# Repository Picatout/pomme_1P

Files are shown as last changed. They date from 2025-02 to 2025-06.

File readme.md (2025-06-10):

<!-- 
Copyright Jacques Deschênes, 2025
Ce document fait parti du projet pomme-I+
https://github.com/picatout/pomme-I+
-->

# POMME I+

En 2023/24 j'ai développé l'ordinateur [pomme-I](https://github.com/Picatout/pomme-I) sur une carte [NUCLEO-8S207K8](https://www.st.com/en/evaluation-tools/nucleo-8s207k8.html)
, cette année j'ai décidé de fabriqué une version du [pomme-I](https://github.com/Picatout/pomme-I) avec un micropresseur [W65C02S](https://www.mouser.ca/ProductDetail/Western-Design-Center-WDC/W65C02S6TPG-14?qs=opBjA1TV903lvWo9AEKH5w%3D%3D) qui est une version CMOS améliorée du vénérable 6502 qui était utilisé dans le Apple-I. Cette version du **MPU** comprend des instructions supplémentaires par rapport à l'original mais possède une compatibilité ascendante.

J'ai effectué le montage sur 3 cartes de prototypage pleine longueur [Ptsolns](https://ptsolns.com/fr/products/proto-full-basic) collée l'une à l'autre par la tranche pour former un ensemble mesurant 17,5 x 20 cm. 

### Assemblage résivé
* Ajout du PIA W65C22
* Remplacé socket du EEPROM par un socket ZIF
* Remplacé socket du EEPROM optionnel par un DIP-28 300mil au lieu du DIP28 600 mil.

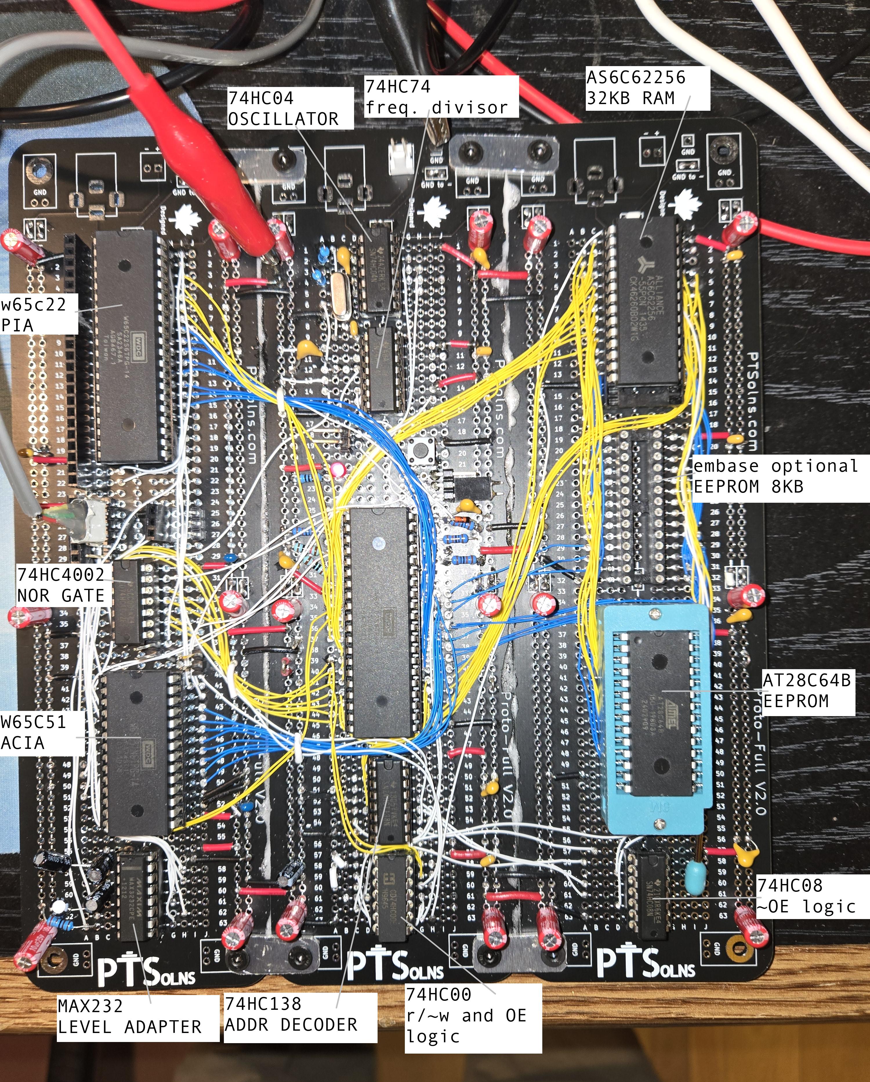
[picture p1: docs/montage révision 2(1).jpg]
assemblage


* La carte centrale comprend l'oscillateur *system clock* le *MPU* ainsi que le *décodeur d'adresses*.
* La carte de droite contient la mémoire **RAM** et **EEPROM**
* La carte de gauche contient un [W65C51S](https://www.mouser.ca/ProductDetail/Western-Design-Center-WDC/W65C51N6TPG-14?qs=AgbsAOSw7WDdUCKSkUixbw%3D%3D) qui est une interface de communication sérielle, i.e. UART. Un [MAX232CPE](https://www.mouser.ca/ProductDetail/Analog-Devices-Maxim-Integrated/MAX232CPE%2b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) est utilisé pour l'adaptation de niveau au standard **RS-232** pour permettre la communication avec un port sériel de PC. Il y a un espace libre suffisante sur la carte pour ajouter un module de développement du genre **NUCLEO-8S207K8**, **PI-PICO**, **BLUE PILL** ou encore **BLACK PILL**. À ce moment je n'ai pas arrêté mon choix sur le type d'exention que je vais ajouté sur cet espace. 

À cette étape je vais utilisé mon PC comme terminal pour le développement du software.  

### Schématique

Pour l'essentiel la schématique du circuit est complète et peut-être consultée dans le document [docs/pomme_1+_schematic.pdf](docs/pomme_1+_schematic.pdf).

### État actuel du projet
Dans l'état actuel du projet je branche l'ordinateur au PC et utilise l'émulateur de terminal **GTKTerm** configuré à 115200 8N1. Il n'y a qu'un petit programme de [test1.s](p1pMonitor/test1.s) dans l'EEPROM. 

Le projet [eeProg](https://github.com/Picatout/eeprom-programmer) que j'ai développer dernièrement me sert à programmer cet EEPROM. 

### spécifications:

* Processeur **W65C02STPG** de Western Design Center
* 3 fréquences d'horlogue (*system clock*) sont disponibles en positionnant un cavalier.
    * 3,6864Mhz 
    * 1,8432Mhz 
    * 0,9216Mhz 

* Mémoire RAM de 32Ko, 0x0000-0x7FFF 
* Mémoire EEPROM de 8Ko, 0xE000-0xFFFF 
* Mémoire EEPROM optionnelle de 8Ko, 0xB000-0xCFFF
* Périphérique ACIA à 0xD000-0xD003, décodage partiel sur un espace de 4Ko.

### Dévelopement logiciel
J'utilise l'assembleur [ca65](https://cc65.github.io/doc/ca65.html) pour le dévelopement logiciel.

1. je vais écrire les fonctions de base de l'interface de communication et ensuite adapter le WOZMON du Apple I. 

2. je vais étendre le BIOS et écrire un système d'exploitation inspiré de CP/M. 

3. Adapter le Microsoft BASIC à partir du Travail de [Ben Eater](https://github.com/beneater/msbasic) qui est lui-même une adaptation à partir de [mist64/msBasic](https://github.com/mist64/msbasic).

### Continuation du dévelopement matériel
Au final cet ordinateur aura son propre terminal intégré et sera monté dans un boitier en bois semblable à celui que j'ai fait pour le [pomme-I](https://github.com/Picatout/pomme-I).

### 2025-03-11 vidéo de présention 

[vidéo de présentation du pomme 1+](https://youtu.be/0cAoQgj5ZgQ)

[début](#top)

### 2025-04-24

* Changement de direction, pour le moment j'ai abandonné le sous-projet **p1+_drive** pour fabriquer une carte contenant seulement la mémoire flash **W25Q080DV** de 1MO et qui et branchée directement sur un connecteur relié au PIA **W65C22**. Donc tous le firmware pour le stockage des programmes dans la mémoire flash cera programmé dans le BIOS du **pomme 1+.** 

carte mémoire flash. 

[lien vidéo montrant la carte](https://youtube.com/shorts/QT92BZp_K6k?feature=share)

[début](#top)

### 2025-05-21

Modification de la carte SSD et son. Ajout d'un amplificateur audio et d'un petit haut-parleur sur la carte. LE timer 1 du VIA , i.e. **W65C22** est utilisé pour générer des tonalités en sortie sur PB7. 

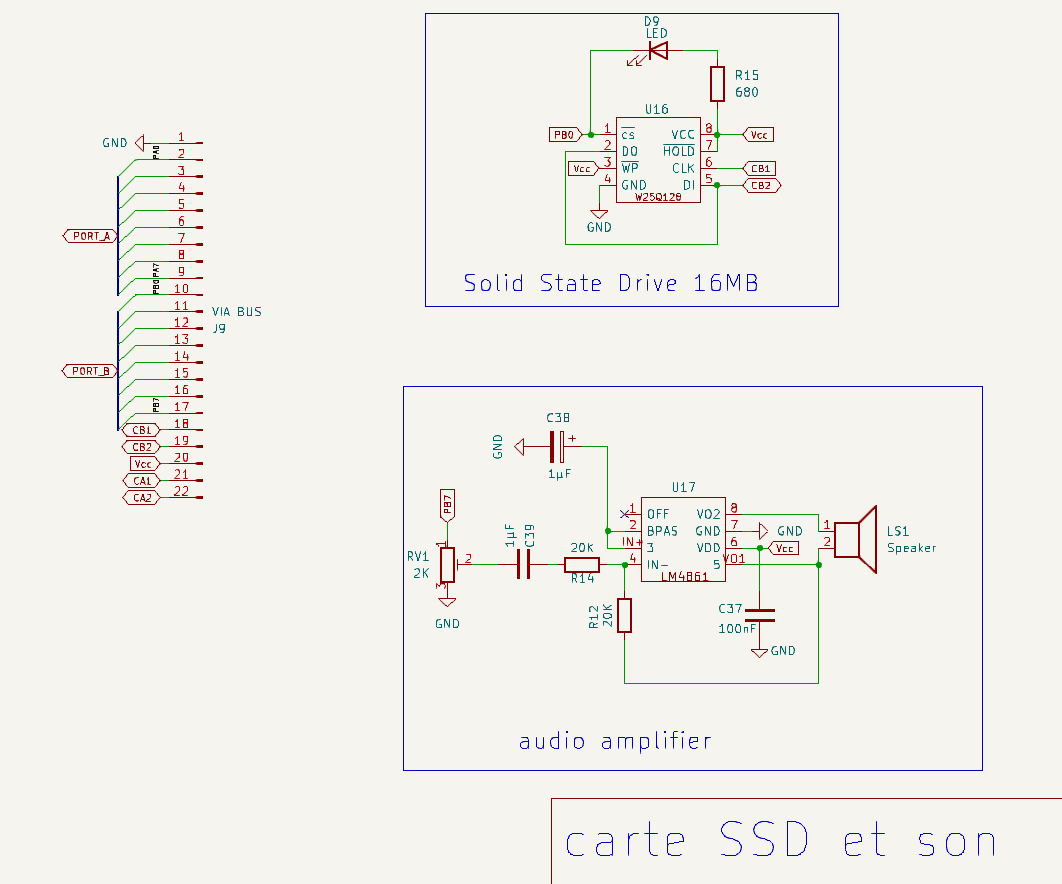
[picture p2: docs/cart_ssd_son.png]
schématique ssd et son
 

carte ssd+son 

Cette carte se branche sur un connecteur qui est relié à toutes les broches E/S du VIA. 

**p1+Monitor version 1.2.2** 

[lien vidéo démonstration de la dernière version du moniteur](https://youtu.be/FdeKaAmC1mY)

[début](#top)

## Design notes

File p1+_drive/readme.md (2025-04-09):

# p1+_drive 

Comme tous les ordinateurs le **pomme 1+** a besoin d'une mémoire de masse persistante pour stocké les fichiers. Ce projet créé un périphérique de stockage de 1 Mo en utilisant un MCU STM8S207K8T ainsi qu'une mémoire flash Winbond W25Q080DV . Le STM8S207K8T sera interfacé avec le **pomme 1+** directement par le **data bus**.

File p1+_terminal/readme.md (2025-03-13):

# STM8 terminal 

Un terminal ASCII réalisé sur une carte NUCLEO-S207K8

*   Affichage 62 caractères par ligne, 25 lignes 
*   Clavier PS/2 
*   TVout NTSC. 
*   interface UART niveaux 0:5 volts 

### NOTE 

Sur la carte **nucleo_8S207K8** les cavaliers **SB3,SB4** doivent-être déplacés vers **SB7,SB9**.

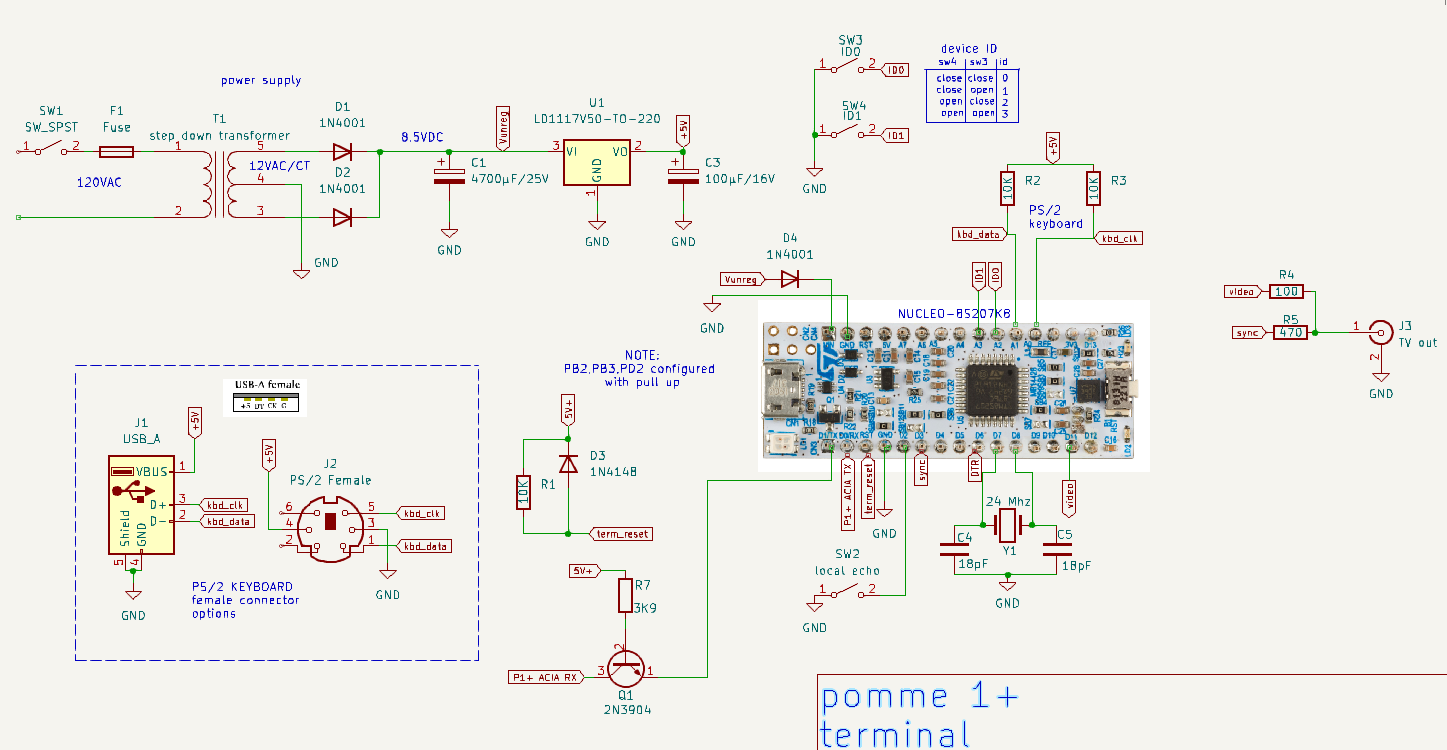
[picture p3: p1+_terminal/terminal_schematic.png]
schématique


Ce terminal a été créé pour le projet [POMME-I+](https://github.com/Picatout/pomme-1P).

Les 2 cartes NUCLEO-8S207K8 communique entre elle via le UART. Voir la schématique complète du projet [POMME-I](https://github.com/Picatout/pomme-I) sur le déppôt github de ce dernier. 

## Quand il faut compter les cycles machines.

Sortir 40 caractères par ligne avec un MCU fonctionnant à 20Mhz en utilisant le protocole NTSC n'a pa été évident. Il n'y avait tout simplement pas suffisamment de temps pour utiliser des compteurs avec boucle. Le temps d'affichage d'une ligne de balayage NTSC est de 52µsec. 1 cycle cpu à 20Mhz dure 50nsec on dispose donc d'un maximum de 1040 cycles pour afficher les 40 caractères ce qui donne 26 cycles cpu par caractère.

Après plusieurs expérimentation avec le périphérique SPI qui ne donnait pas de résultat satisfaisant j'ai abandonné le SPI. Pour y parvenir j'ai fait 2 choses. 

1. Le tampon video **video_buffer** ne contient pas les caractères à afficher mais l'adresse du caractère dans la table **font_6x8**. Ainsi il n'y a pas de cycle perdu pour faire le calcul de l'adresse du caractère pendant l'affichage. C'est la routine **tv_putc** qui fait le travail. 

1. Pour sortir les pixels vidéos il faut sérialiser les pixels représentant le caractère. Faire ça en sorftware prend 14 cycles cpu avec la macro  **_shift_out_char** du fichier [tvout.asm](tvout.asm).
La macro **_shift_out_scan_line** prend 20 cycles au total en incluant **_shift_out_char**. Si on fait le calcul pour 40 caractères ça fait 800 cycles soit 40µsec. Bien en déça des 52µsec allouée. Ça c'est selon les cycles machines fournis par le manufacturier du STM8 mais en pratique la durée mesurée à l'oscilloscope est de 51.2µsec. C'est serré! Tellement serré que je ne pouvait utiliser des boucles avec compteurs. Pour arriver à ce temps j'ai du dérouler la macro 40 fois. 

# Où sont passés ces cycles CPU. 

Je me suis mis à réfléchir à cette différence entre le nombre de cycles CPU selon ce que je mesure à l'oscilloscope le temps d'éxécution par caractère serait de 51.2µsec/50nsec=1024/40=25.6 cycles au lieu de 20 cycles. 5.6 de plus. Donc je me demandais où étaient passés ces cycles? Je me suis dit que le fait de lire l'octet dans la table font_6x8 entre en concurrence avec la lecture des instructions machine. STM8 est une architecture Harvard. Ça signigit que le bus d'instruction est séparé du bus de données. Cette architecture a étée conçue pour améliorer la vitesse d'exécution des instructions puisque celle-ci n'ont pas à partager l'accès mémoire avec les données. Je me suis donc dit que si je copiais la table [font_6x8](font.asm) dans la mémoire RAM ce conflit d'accès serait éliminé et que l'exécution serait plus rapide. 

J'ai fait le test et c'est bien le cas, sauf qu'il n'y a qu'un seul cycle machine par caractère de récupéré. L'affichage des 40 caractères avec la police en mémoire RAM prend 49.2µsec soit 2µsec de moins ce qui correspond une fois le calcul fait à 1 cycle par caractère. Il y a donc encore 4.6 cycles manquant. 

Pour comprendre cette différence il faut lire le chapitre 5 du manuel de progammation  [PM0044](https://www.st.com/content/ccc/resource/technical/document/programming_manual/43/24/13/9a/89/df/45/ed/CD00161709.pdf/files/CD00161709.pdf/jcr:content/translations/en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). La section 5.4 et la table 3 nous donnes un bel exemple. Selon le nombre de cycles données dans la description de chaque instruction: 

1.  LDW X,[$50.w] ; 5 cycles 
1.  ADDW X,#20   ; 2 cycles 
1.  LD A,[$300].w ; 4 cycles 

On obtient un total de **11 cycles**. mais dans la table 3 on voit qu'en fait il en faut **12**. 

Donc en conclusion le pipelining permet d'accélérer l'exécution des instructions sauf qu'il n'est plus possible de se fier au nombre de cycles donnés dans la description de chaque instruction pour calculer le temps d'exécution d'une séquence d'instructions, comme c'est le cas pour un mcu PIC 16Fxxxx. 

### 2023-07-17

L'intégration du **STM8_terminal** avec l'ordinateur **POMME-I** a nécessité des modifications aux 2 projets. Durant certaines opérations du terminal ce dernier perdait des caractères envoyés par l'ordinateur. Le problème a été corrigé par l'ajout d'un contrôle de flux matériel appellé **DTR** pour *Data Terminal Ready*. l'ordinateur n'envoie des caractères au terminal que lorsque ce signal est à **0** volt.

### 2023-07-05 

* Modification au circuit du terminal pour ajouter des commutateurs pour la sélection d'options utilisateur.

    * **SW3** sert à sélectionner un écho local lorsqu'il est à **1** 
    * **SW4** et **SW5** permettent de sélectionner un BAUD rate pour  le UART.

  SW4|SW5|BAUD 
    -|-|-
    0|0| 9600
    0|1| 19200
    1|0| 38400
    1|1| 115200

Si les commutateurs ne sont pas installés par défaut les broches sont toutes à **1** à travers les résistances *pull up* MCU, donc il y a écho local et le BAUD est à 115200.

Les commautateurs sont lu lors de l'initialisation et toute modification de leur position requiert un redémarrage du MCU pour que la nouvelle configuration prenne effet.

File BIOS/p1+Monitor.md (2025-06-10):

# manuel du moniteur pomme I+

Le moniteur est l'application qui est exécutée au démarrage de l'ordinateur pomme I+. Cette application permet les fonctions suivantes:

* Examiner le contenu de la mémoire.
* Modifier le contenu de la mémoire RAM.
* Initialiser une plage mémoire à zéro.
* Copier une plage mémoire vers une autre addresse.
* Comparer du plages mémoire pour les différences.
* Sauvarder une plage mémoire vers le SSD.
* Charger une plage mémoire avec le contenu du SSD.
* Exécuter une routine en langage machine.

## Utilisation du moniteur 

Au démarrage le message suivant apparaît. le caractère **#** est le prompt de commande.

```
pomme I+ BIOS version 1.0R0
pomme 1+ monitor version 1.2R1

#
```
## les commandes 

Toutes les valeurs numériques doivent-être en hexadécimal.

### Examiner le contenu de la mémoire.

Simplement en appuyant sur la touche __&lt;ENTER&gt;__ le contenu de 16 adresses mémoire est affiché. 
```
#

0000: E5 97 11 00 00 00 00 00 00 00 00 00 03 00 7D FF  ;               } 
#

0010: FF 00 00 00 00 00 00 02 02 00 FC 0D 0D 33 66 66  ;              3ff
#

0020: 0D 66 66 6D 33 30 31 0D 33 30 30 2E 33 66 66 0D  ;  ffm301 300.3ff 
#

0030: 33 30 30 2E 33 66 66 7A 0D 33 30 00 00 3D 00 3F  ; 300.3ffz 30  = ?
#
``` 
Pour afficher une plage mémoire spécifique on entre l'adresse de départ et l'adresse de fin séparées par un **.** (point). 
```
#400.4FF

0400: 47 00 00 00 00 00 00 00 00 00 00 00 00 00 00 00  ; G               
0410: 00 00 00 00 00 00 00 00 00 00 00 00 00 00 00 00  ;                 
0420: 00 00 00 00 00 00 00 00 00 00 00 00 00 00 00 00  ;                 
0430: 00 00 00 00 00 00 00 00 00 00 00 00 00 00 00 00  ;                 
0440: 00 00 00 00 00 00 00 00 00 00 00 00 00 00 00 00  ;                 
0450: 00 00 00 00 00 00 00 00 00 00 00 00 00 00 00 00  ;                 
0460: 00 00 00 00 00 00 00 00 00 00 00 00 00 00 00 00  ;                 
0470: 00 00 00 00 00 00 00 00 00 00 00 00 00 00 00 00  ;                 
0480: 00 00 00 00 00 00 00 00 00 00 00 00 00 00 00 00  ;                 
0490: 00 00 00 00 00 00 00 00 00 00 00 00 00 00 00 00  ;                 
04A0: 00 00 00 00 00 00 00 00 00 00 00 00 00 00 00 00  ;                 
04B0: 00 00 00 00 00 00 00 00 00 00 00 00 00 00 00 00  ;                 
04C0: 00 00 00 00 00 00 00 00 00 00 00 00 00 00 00 00  ;                 
04D0: 00 00 00 00 00 00 00 00 00 00 00 00 00 00 00 00  ;                 
04E0: 00 00 00 00 00 00 00 00 00 00 00 00 00 00 00 00  ;                 
04F0: 00 00 00 00 00 00 00 00 00 00 00 00 00 00 00 00  ;                 
#
```
 __&lt;ENTER&gt;__ après cette commande va afficher le contenu de 500.50f
 ```
 #

0500: 00 00 00 00 00 00 00 00 00 00 00 00 00 00 00 00  ;                 
#

``` 

### Modifier le contenu de la mémoire. 
Une addresse suivie du caractère **:**  et de valeurs numérique ou chaines de caractères permet de modifier le contenu de la mémoire.
```
#400: 30 31 32 33 34 35 " bonjour  vous!"

#400.41f

0400: 30 31 32 33 34 35 20 62 6F 6E 6A 6F 75 72 20 20  ; 012345 bonjour  
0410: 76 6F 75 73 21 00 00 00 00 00 00 00 00 00 00 00  ; vous!           
#
```
### Exécuter une routine en langage machine.
La commande **G**o sub permet d'exécuter une sous-routine en langague machine.
```
#300:d "hello world!"

#310: A9 3 A2 0 20 43 E4 60

#300.31F

0300: 0D 68 65 6C 6C 6F 20 77 6F 72 6C 64 21 00 83 71  ;  hello world!  q
0310: A9 03 A2 00 20 43 E4 60 00 00 00 04 02 00 00 00  ;      C `        
#310G

hello world!
#G

hello world!
#
```
Dans cet exemple on a inscrit à l'adresse **0x300** la chaine de caractères "\rhello world!" et à l'adresse **0x310** on a inscrit la routine à exécuter.
l'adresse de la routine suivit de la lettre **G** permet d'exécuter la routine. On peut réexécuter la routine plusieurs fois simplement en entrant la lettre **G** Suivant de la touche **&lt;ENTER&gt;**. 

### Copîer le contenu d'une plage mémoire 
La commande **M**  permet de copier une plage vers une destination.
```
#400.415M420

#400.44F

0400: 30 31 32 33 34 35 20 62 6F 6E 6A 6F 75 72 20 20  ; 012345 bonjour  
0410: 76 6F 75 73 21 00 00 00 00 00 00 00 00 00 00 00  ; vous!           
0420: 30 31 32 33 34 35 20 62 6F 6E 6A 6F 75 72 20 20  ; 012345 bonjour  
0430: 76 6F 75 73 21 00 00 00 00 00 00 00 00 00 00 00  ; vous!           
0440: 00 00 00 00 00 00 00 00 00 00 00 00 00 00 00 00  ;                 
#
```
Dans cette exemple le contenu de la plage débutant à 400 et se terminant à 415 a été copiée à l'adresse 420.

### Mettre une plage à la valeur zéro.
La commande **Z** permet de mettre une plage mémoire à zéro.
```
#400.435Z

#400.435

0400: 00 00 00 00 00 00 00 00 00 00 00 00 00 00 00 00  ;                 
0410: 00 00 00 00 00 00 00 00 00 00 00 00 00 00 00 00  ;                 
0420: 00 00 00 00 00 00 00 00 00 00 00 00 00 00 00 00  ;                 
0430: 00 00 00 00 00 00  ;                 
#
```
ComMe on le voie le texte a été remplacé par des zéro. 

### Mettre une autre valeur que zéro.
Il existe une astuce pour remplir une plage avec une valeur autre que zéro. Il s'agit d'utiliser la commandees **:** suivit de la commande **M**.
```
#400: "hello world!" 

#400.40f

0400: 68 65 6C 6C 6F 20 77 6F 72 6C 64 21 00 00 00 00  ; hello world!    
#400.4FFM40C

#400.4FF

0400: 68 65 6C 6C 6F 20 77 6F 72 6C 64 21 68 65 6C 6C  ; hello world!hell
0410: 6F 20 77 6F 72 6C 64 21 68 65 6C 6C 6F 20 77 6F  ; o world!hello wo
0420: 72 6C 64 21 68 65 6C 6C 6F 20 77 6F 72 6C 64 21  ; rld!hello world!
0430: 68 65 6C 6C 6F 20 77 6F 72 6C 64 21 68 65 6C 6C  ; hello world!hell
0440: 6F 20 77 6F 72 6C 64 21 68 65 6C 6C 6F 20 77 6F  ; o world!hello wo
0450: 72 6C 64 21 68 65 6C 6C 6F 20 77 6F 72 6C 64 21  ; rld!hello world!
0460: 68 65 6C 6C 6F 20 77 6F 72 6C 64 21 68 65 6C 6C  ; hello world!hell
0470: 6F 20 77 6F 72 6C 64 21 68 65 6C 6C 6F 20 77 6F  ; o world!hello wo
0480: 72 6C 64 21 68 65 6C 6C 6F 20 77 6F 72 6C 64 21  ; rld!hello world!
0490: 68 65 6C 6C 6F 20 77 6F 72 6C 64 21 68 65 6C 6C  ; hello world!hell
04A0: 6F 20 77 6F 72 6C 64 21 68 65 6C 6C 6F 20 77 6F  ; o world!hello wo
04B0: 72 6C 64 21 68 65 6C 6C 6F 20 77 6F 72 6C 64 21  ; rld!hello world!
04C0: 68 65 6C 6C 6F 20 77 6F 72 6C 64 21 68 65 6C 6C  ; hello world!hell
04D0: 6F 20 77 6F 72 6C 64 21 68 65 6C 6C 6F 20 77 6F  ; o world!hello wo
04E0: 72 6C 64 21 68 65 6C 6C 6F 20 77 6F 72 6C 64 21  ; rld!hello world!
04F0: 68 65 6C 6C 6F 20 77 6F 72 6C 64 21 68 65 6C 6C  ; hello world!hell
#
```
Dans cette exemple on a initialiser la plage 400.41C avec la chaine "hello world!" ensuite on a utiliser la commande **M**ove pour copier à répétion cette chaîne en décallant l'adresse de destination juste après la chaîne. 

Évidemment on peut remplir avec une valeur unique avec cette astuce.
```
#400: 21
#400.4FFM401

#400.4FF

0400: 21 21 21 21 21 21 21 21 21 21 21 21 21 21 21 21  ; !!!!!!!!!!!!!!!!
0410: 21 21 21 21 21 21 21 21 21 21 21 21 21 21 21 21  ; !!!!!!!!!!!!!!!!
0420: 21 21 21 21 21 21 21 21 21 21 21 21 21 21 21 21  ; !!!!!!!!!!!!!!!!
0430: 21 21 21 21 21 21 21 21 21 21 21 21 21 21 21 21  ; !!!!!!!!!!!!!!!!
0440: 21 21 21 21 21 21 21 21 21 21 21 21 21 21 21 21  ; !!!!!!!!!!!!!!!!
0450: 21 21 21 21 21 21 21 21 21 21 21 21 21 21 21 21  ; !!!!!!!!!!!!!!!!
0460: 21 21 21 21 21 21 21 21 21 21 21 21 21 21 21 21  ; !!!!!!!!!!!!!!!!
0470: 21 21 21 21 21 21 21 21 21 21 21 21 21 21 21 21  ; !!!!!!!!!!!!!!!!
0480: 21 21 21 21 21 21 21 21 21 21 21 21 21 21 21 21  ; !!!!!!!!!!!!!!!!
0490: 21 21 21 21 21 21 21 21 21 21 21 21 21 21 21 21  ; !!!!!!!!!!!!!!!!
04A0: 21 21 21 21 21 21 21 21 21 21 21 21 21 21 21 21  ; !!!!!!!!!!!!!!!!
04B0: 21 21 21 21 21 21 21 21 21 21 21 21 21 21 21 21  ; !!!!!!!!!!!!!!!!
04C0: 21 21 21 21 21 21 21 21 21 21 21 21 21 21 21 21  ; !!!!!!!!!!!!!!!!
04D0: 21 21 21 21 21 21 21 21 21 21 21 21 21 21 21 21  ; !!!!!!!!!!!!!!!!
04E0: 21 21 21 21 21 21 21 21 21 21 21 21 21 21 21 21  ; !!!!!!!!!!!!!!!!
04F0: 21 21 21 21 21 21 21 21 21 21 21 21 21 21 21 21  ; !!!!!!!!!!!!!!!!
#
```
## Sauvagarder et restaurer dans la mémoire FLASH 
Le pomme I+ possède une mémoire FLASH de 16Mo **W25Q128**  qui sert de SSD pour l'ordinateur. Il est possible de sauvegarder une plage mémoire dans celle-ci et de la recharger dans la RAM de l'ordinaeur. Cette plage doit-être un multiple de 256 octets.

### Sauvegarde une plage 
La sauvegarde se fait par plage de 256 octets car pour la programmation le W25Q128 n'accepte que 256 octets par étape. La commande **W** est effectuée 
pour cette opération. 

On va d'abord initialiser une plage mémoire avec un patron facilement reconnaissable.
```
#300: "The quick brown fox jump over the lazy dog."          

#32B.3FFZ

#400: "Le renard rapide saute par dessus le chien paresseux."

#438.4FFZ

#300.4FFW0 

#300.4FFZ  

```

Examinons cette plage mémoire avant de la sauvegardée sur le SSD.
```
0300: 54 68 65 20 71 75 69 63 6B 20 62 72 6F 77 6E 20  ; The quick brown 
0310: 66 6F 78 20 6A 75 6D 70 20 6F 76 65 72 20 74 68  ; fox jump over th
0320: 65 20 6C 61 7A 79 20 64 6F 67 2E 00 00 00 00 00  ; e lazy dog.     
0330: 00 00 00 00 00 00 00 00 00 00 00 00 00 00 00 00  ;                 
0340: 00 00 00 00 00 00 00 00 00 00 00 00 00 00 00 00  ;                 
0350: 00 00 00 00 00 00 00 00 00 00 00 00 00 00 00 00  ;                 
0360: 00 00 00 00 00 00 00 00 00 00 00 00 00 00 00 00  ;                 
0370: 00 00 00 00 00 00 00 00 00 00 00 00 00 00 00 00  ;                 
0380: 00 00 00 00 00 00 00 00 00 00 00 00 00 00 00 00  ;                 
0390: 00 00 00 00 00 00 00 00 00 00 00 00 00 00 00 00  ;                 
03A0: 00 00 00 00 00 00 00 00 00 00 00 00 00 00 00 00  ;                 
03B0: 00 00 00 00 00 00 00 00 00 00 00 00 00 00 00 00  ;                 
03C0: 00 00 00 00 00 00 00 00 00 00 00 00 00 00 00 00  ;                 
03D0: 00 00 00 00 00 00 00 00 00 00 00 00 00 00 00 00  ;                 
03E0: 00 00 00 00 00 00 00 00 00 00 00 00 00 00 00 00  ;                 
03F0: 00 00 00 00 00 00 00 00 00 00 00 00 00 00 00 00  ;                 
0400: 4C 65 20 72 65 6E 61 72 64 20 72 61 70 69 64 65  ; Le renard rapide
0410: 20 73 61 75 74 65 20 70 61 72 20 64 65 73 73 75  ;  saute par dessu
0420: 73 20 6C 65 20 63 68 69 65 6E 20 70 61 72 65 73  ; s le chien pares
0430: 73 65 75 78 2E 00 00 00 00 00 00 00 00 00 00 00  ; seux.           
0440: 00 00 00 00 00 00 00 00 00 00 00 00 00 00 00 00  ;                 
0450: 00 00 00 00 00 00 00 00 00 00 00 00 00 00 00 00  ;                 
0460: 00 00 00 00 00 00 00 00 00 00 00 00 00 00 00 00  ;                 
0470: 00 00 00 00 00 00 00 00 00 00 00 00 00 00 00 00  ;                 
0480: 00 00 00 00 00 00 00 00 00 00 00 00 00 00 00 00  ;                 
0490: 00 00 00 00 00 00 00 00 00 00 00 00 00 00 00 00  ;                 
04A0: 00 00 00 00 00 00 00 00 00 00 00 00 00 00 00 00  ;                 
04B0: 00 00 00 00 00 00 00 00 00 00 00 00 00 00 00 00  ;                 
04C0: 00 00 00 00 00 00 00 00 00 00 00 00 00 00 00 00  ;                 
04D0: 00 00 00 00 00 00 00 00 00 00 00 00 00 00 00 00  ;                 
04E0: 00 00 00 00 00 00 00 00 00 00 00 00 00 00 00 00  ;                 
04F0: 00 00 00 00 00 00 00 00 00 00 00 00 00 00 00 00  ;                 
#
```

On va sauvegarder cette plage de 512 octets à la page 0  de la W25Q128 
```
#300.4FFW0

#
```
On va recharger cette page à l'adresse 0x500 avec la commande **R**EAD.
```
#500.6FFR0
```
Maintenant on va regarché ses 512 octets dans la plage 500.6FF et vérifier que le chargement est identuique à la plaque sauvegardée sur le SSD. 
```
#500.6FFR0

#300.4FFV500

#
```

Il n'y a pas de différences d'affichées donc c'est correct. Affichons la plage pour voir son contenu.
```
#500.6FF

0500: 54 68 65 20 71 75 69 63 6B 20 62 72 6F 77 6E 20  ; The quick brown 
0510: 66 6F 78 20 6A 75 6D 70 20 6F 76 65 72 20 74 68  ; fox jump over th
0520: 65 20 6C 61 7A 79 20 64 6F 67 2E 00 00 00 00 00  ; e lazy dog.     
0530: 00 00 00 00 00 00 00 00 00 00 00 00 00 00 00 00  ;                 
0540: 00 00 00 00 00 00 00 00 00 00 00 00 00 00 00 00  ;                 
0550: 00 00 00 00 00 00 00 00 00 00 00 00 00 00 00 00  ;                 
0560: 00 00 00 00 00 00 00 00 00 00 00 00 00 00 00 00  ;                 
0570: 00 00 00 00 00 00 00 00 00 00 00 00 00 00 00 00  ;                 
0580: 00 00 00 00 00 00 00 00 00 00 00 00 00 00 00 00  ;                 
0590: 00 00 00 00 00 00 00 00 00 00 00 00 00 00 00 00  ;                 
05A0: 00 00 00 00 00 00 00 00 00 00 00 00 00 00 00 00  ;                 
05B0: 00 00 00 00 00 00 00 00 00 00 00 00 00 00 00 00  ;                 
05C0: 00 00 00 00 00 00 00 00 00 00 00 00 00 00 00 00  ;                 
05D0: 00 00 00 00 00 00 00 00 00 00 00 00 00 00 00 00  ;                 
05E0: 00 00 00 00 00 00 00 00 00 00 00 00 00 00 00 00  ;                 
05F0: 00 00 00 00 00 00 00 00 00 00 00 00 00 00 00 00  ;                 
0600: 4C 65 20 72 65 6E 61 72 64 20 72 61 70 69 64 65  ; Le renard rapide
0610: 20 73 61 75 74 65 20 70 61 72 20 64 65 73 73 75  ;  saute par dessu
0620: 73 20 6C 65 20 63 68 69 65 6E 20 70 61 72 65 73  ; s le chien pares
0630: 73 65 75 78 2E 00 00 00 00 00 00 00 00 00 00 00  ; seux.           
0640: 00 00 00 00 00 00 00 00 00 00 00 00 00 00 00 00  ;                 
0650: 00 00 00 00 00 00 00 00 00 00 00 00 00 00 00 00  ;                 
0660: 00 00 00 00 00 00 00 00 00 00 00 00 00 00 00 00  ;                 
0670: 00 00 00 00 00 00 00 00 00 00 00 00 00 00 00 00  ;                 
0680: 00 00 00 00 00 00 00 00 00 00 00 00 00 00 00 00  ;                 
0690: 00 00 00 00 00 00 00 00 00 00 00 00 00 00 00 00  ;                 
06A0: 00 00 00 00 00 00 00 00 00 00 00 00 00 00 00 00  ;                 
06B0: 00 00 00 00 00 00 00 00 00 00 00 00 00 00 00 00  ;                 
06C0: 00 00 00 00 00 00 00 00 00 00 00 00 00 00 00 00  ;                 
06D0: 00 00 00 00 00 00 00 00 00 00 00 00 00 00 00 00  ;                 
06E0: 00 00 00 00 00 00 00 00 00 00 00 00 00 00 00 00  ;                 
06F0: 00 00 00 00 00 00 00 00 00 00 00 00 00 00 00 00  ;                 
#

```

### Vérifier le contenu.
Dans l'exemple précédent il est facile de vérifier que l'opération s'est effectuée correctement, mais s'il s'agissait de code binaire ce ne serait pas si simple. La commande **V**erify  peut le faire pour nous.
```
#400.4FFV600

#

```
La vérification n'a rien affichée donc les 2 plages sont identiques. Modifions quelques octets à l'adresse 400 et répétons la vérification.
```
#400:"bonjour"

#400.4ffv600
0400 62  0600 48
0401 6F  0601 45
0402 6E  0602 4C
0403 6A  0603 4C
0404 6F  0604 4F
0405 75  0605 20
0406 72  0606 57
0407 00  0607 4F

#
```
Le **bonjour** a remplacé le début de **HELLO WORLD!** donc la commande affiche les 7 adresses mémoires qui divergent.

### Effacer un secteur du SSD 
la Commande **X** permet d'effacer un secteur de la W25Q128. Le plus petit bloc de la mémoire FLASH qui peut-être effacé est de 4096 octets. Puisque le W25Q128 possède 16MO de mémoire il y a 65536 secteurs effacables {0..FFFF}.
Puisqu'on a enregistré quelque chose à la page 0x10 on va effacer le secteur qui contient cette page. Puisqu'il y a 16 pages par secteur la page 0x10 est la première page du secteur 1.
```
#1x
CONFIRM FLASH ERASE(Y/N)

#300r10

#300.3ff

0300: FF FF FF FF FF FF FF FF FF FF FF FF FF FF FF FF  ;                 
0310: FF FF FF FF FF FF FF FF FF FF FF FF FF FF FF FF  ;                 
0320: FF FF FF FF FF FF FF FF FF FF FF FF FF FF FF FF  ;                 
0330: FF FF FF FF FF FF FF FF FF FF FF FF FF FF FF FF  ;                 
0340: FF FF FF FF FF FF FF FF FF FF FF FF FF FF FF FF  ;                 
0350: FF FF FF FF FF FF FF FF FF FF FF FF FF FF FF FF  ;                 
0360: FF FF FF FF FF FF FF FF FF FF FF FF FF FF FF FF  ;                 
0370: FF FF FF FF FF FF FF FF FF FF FF FF FF FF FF FF  ;                 
0380: FF FF FF FF FF FF FF FF FF FF FF FF FF FF FF FF  ;                 
0390: FF FF FF FF FF FF FF FF FF FF FF FF FF FF FF FF  ;                 
03A0: FF FF FF FF FF FF FF FF FF FF FF FF FF FF FF FF  ;                 
03B0: FF FF FF FF FF FF FF FF FF FF FF FF FF FF FF FF  ;                 
03C0: FF FF FF FF FF FF FF FF FF FF FF FF FF FF FF FF  ;                 
03D0: FF FF FF FF FF FF FF FF FF FF FF FF FF FF FF FF  ;                 
03E0: FF FF FF FF FF FF FF FF FF FF FF FF FF FF FF FF  ;                 
03F0: FF FF FF FF FF FF FF FF FF FF FF FF FF FF FF FF  ;                 
#
```
Une demande de confirmation est faite à laquelle on doit répondre **Y** pour effectuer l'opération.

Lorsque un secteur est effacé toutes les valeurs sont mise à **0xFF** 

### Effacer tout le SSD 
La commande __*__ permet d'effacer tout le chip W25Q128. Cette opération dure plus de **40 secondes**.
```
*
THIS WILL ERASE WHOLE SSD, (Y/N)?
Be patient it take 40+ seconds

#300r0

#300.3ff

0300: FF FF FF FF FF FF FF FF FF FF FF FF FF FF FF FF  ;                 
0310: FF FF FF FF FF FF FF FF FF FF FF FF FF FF FF FF  ;                 
0320: FF FF FF FF FF FF FF FF FF FF FF FF FF FF FF FF  ;                 
0330: FF FF FF FF FF FF FF FF FF FF FF FF FF FF FF FF  ;                 
0340: FF FF FF FF FF FF FF FF FF FF FF FF FF FF FF FF  ;                 
0350: FF FF FF FF FF FF FF FF FF FF FF FF FF FF FF FF  ;                 
0360: FF FF FF FF FF FF FF FF FF FF FF FF FF FF FF FF  ;                 
0370: FF FF FF FF FF FF FF FF FF FF FF FF FF FF FF FF  ;                 
0380: FF FF FF FF FF FF FF FF FF FF FF FF FF FF FF FF  ;                 
0390: FF FF FF FF FF FF FF FF FF FF FF FF FF FF FF FF  ;                 
03A0: FF FF FF FF FF FF FF FF FF FF FF FF FF FF FF FF  ;                 
03B0: FF FF FF FF FF FF FF FF FF FF FF FF FF FF FF FF  ;                 
03C0: FF FF FF FF FF FF FF FF FF FF FF FF FF FF FF FF  ;                 
03D0: FF FF FF FF FF FF FF FF FF FF FF FF FF FF FF FF  ;                 
03E0: FF FF FF FF FF FF FF FF FF FF FF FF FF FF FF FF  ;                 
03F0: FF FF FF FF FF FF FF FF FF FF FF FF FF FF FF FF  ;                 
#
```

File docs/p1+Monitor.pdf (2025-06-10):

p1+Monitor.md | 2025-06-10

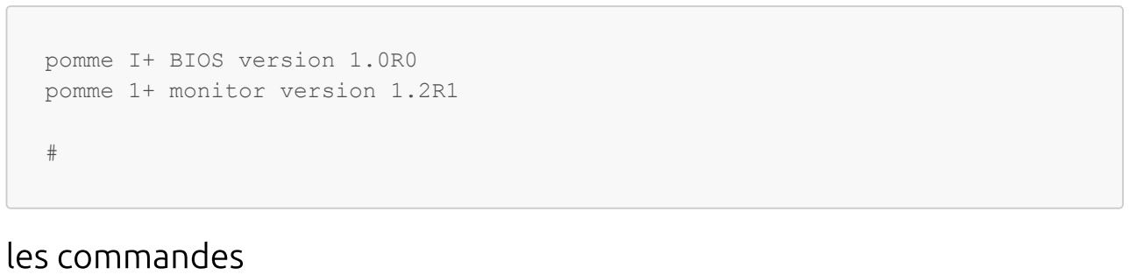
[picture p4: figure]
pomme I+ BIOS version 1.0R0 pomme 1+ monitor version 1.2R1; les commandes

/

## manuel du moniteur pomme I+

Le moniteur est l'application qui est exécutée au démarrage de l'ordinateur pomme I+. Cette application

permet les fonctions suivantes:

Examiner le contenu de la mémoire.

Modier le contenu de la mémoire RAM.

Initialiser une plage mémoire à zéro.

Copier une plage mémoire vers une autre addresse.

Comparer du plages mémoire pour les diérences.

Sauvarder une plage mémoire vers le SSD.

Charger une plage mémoire avec le contenu du SSD.

Exécuter une routine en langage machine.

Utilisation du moniteur

Au démarrage le message suivant apparaît. le caractère # est le prompt de commande.

Toutes les valeurs numériques doivent-être en hexadécimal.

Examiner le contenu de la mémoire.

Simplement en appuyant sur la touche <ENTER> le contenu de 16 adresses mémoire est aché.

0000: E5 97 11 00 00 00 00 00 00 00 00 00 03 00 7D FF ; | }
0010: FF 00 00 00 00 00 00 02 02 00 FC 0D 0D 33 66 66 ; | 3ff

0020: 0D 66 66 6D 33 30 31 0D 33 30 30 2E 33 66 66 0D ; ffm301 300.3ff #

0030: 33 30 30 2E 33 66 66 7A 0D 33 30 00 00 3D 00 3F ; 300.3ffz 30 = ? #

Pour acher une plage mémoire spécique on entre l'adresse de départ et l'adresse de n séparées par un .

(point).

#400.4FF

0400: 47 00 00 00 00 00 00 00 00 00 00 00 00 00 00 00 ; G 0410: 00 00 00 00 00 00 00 00 00 00 00 00 00 00 00 00 ; 0420: 00 00 00 00 00 00 00 00 00 00 00 00 00 00 00 00 ; 0430: 00 00 00 00 00 00 00 00 00 00 00 00 00 00 00 00 ; 0440: 00 00 00 00 00 00 00 00 00 00 00 00 00 00 00 00 ; 0450: 00 00 00 00 00 00 00 00 00 00 00 00 00 00 00 00 ; 0460: 00 00 00 00 00 00 00 00 00 00 00 00 00 00 00 00 ; 0470: 00 00 00 00 00 00 00 00 00 00 00 00 00 00 00 00 ; 0480: 00 00 00 00 00 00 00 00 00 00 00 00 00 00 00 00 ; 0490: 00 00 00 00 00 00 00 00 00 00 00 00 00 00 00 00 ; 04A0: 00 00 00 00 00 00 00 00 00 00 00 00 00 00 00 00 ; 04B0: 00 00 00 00 00 00 00 00 00 00 00 00 00 00 00 00 ; 04C0: 00 00 00 00 00 00 00 00 00 00 00 00 00 00 00 00 ; 04D0: 00 00 00 00 00 00 00 00 00 00 00 00 00 00 00 00 ; 04E0: 00 00 00 00 00 00 00 00 00 00 00 00 00 00 00 00 ; 04F0: 00 00 00 00 00 00 00 00 00 00 00 00 00 00 00 00 ; #

<ENTER> après cette commande va acher le contenu de 500.50f

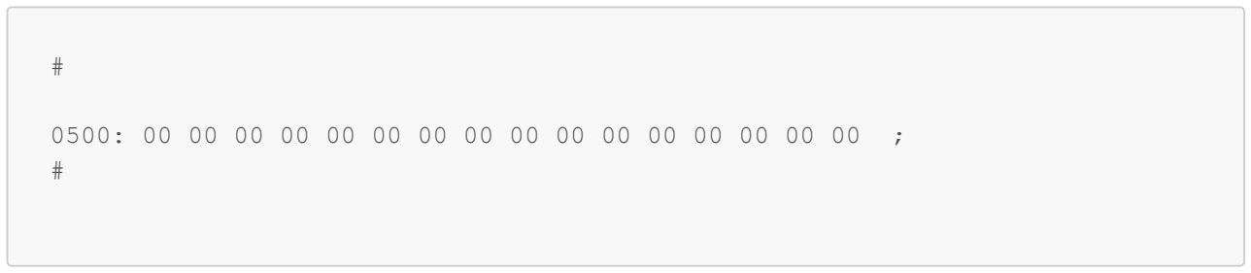
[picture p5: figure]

0500: 00 00 00 00 00 00 00 00 00 00 00 00 00 00 00 00 ;

Modier le contenu de la mémoire.

Une addresse suivie du caractère : et de valeurs numérique ou chaines de caractères permet de modier le

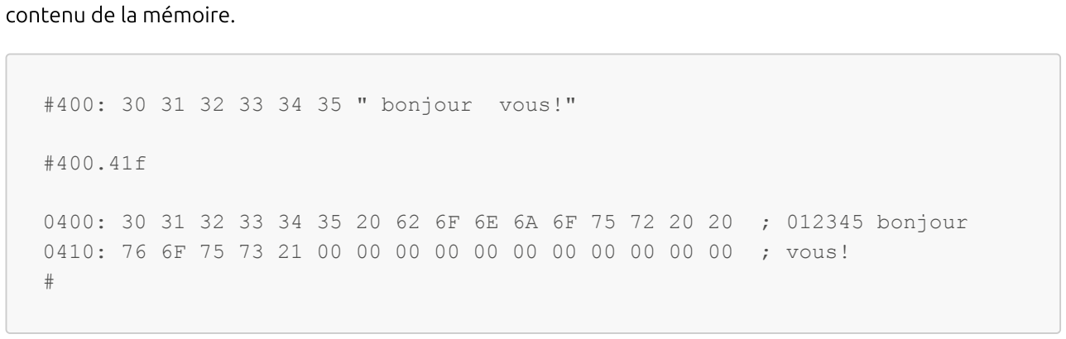
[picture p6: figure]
contenu de la mémoire.

#400: 30 31 32 33 34 35 " bonjour vous!"

0400: 30 31 32 33 34 35 20 62 6F 6E 6A 6F 75 72 20 20 ; 012345 bonjour 0410: 76 6F 75 73 21 00 00 00 00 00 00 00 00 00 00 00 ; vous!

Exécuter une routine en langage machine.

La commande Go sub permet d'exécuter une sous-routine en langague machine.

#300:d "hello world!"

#310: A9 3 A2 0 20 43 E4 60

#300.31F

0300: 0D 68 65 6C 6C 6F 20 77 6F 72 6C 64 21 00 83 71 ; hello world! q
0310: A9 03 A2 00 20 43 E4 60 00 00 00 04 02 00 00 00 ; | C `
#310G

hello world!
#G

hello world!

Dans cet exemple on a inscrit à l'adresse 0x300 la chaine de caractères "\rhello world!" et à l'adresse 0x310

on a inscrit la routine à exécuter. l'adresse de la routine suivit de la lettre G permet d'exécuter la routine. On

peut réexécuter la routine plusieurs fois simplement en entrant la lettre G Suivant de la touche <ENTER>.

Copîer le contenu d'une plage mémoire

La commande M permet de copier une plage vers une destination.

#400.415M420

#400.44F

0400: 30 31 32 33 34 35 20 62 6F 6E 6A 6F 75 72 20 20 ; 012345 bonjour 0410: 76 6F 75 73 21 00 00 00 00 00 00 00 00 00 00 00 ; vous!
0420: 30 31 32 33 34 35 20 62 6F 6E 6A 6F 75 72 20 20 ; 012345 bonjour 0430: 76 6F 75 73 21 00 00 00 00 00 00 00 00 00 00 00 ; vous!
0440: 00 00 00 00 00 00 00 00 00 00 00 00 00 00 00 00 ;

Dans cette exemple le contenu de la plage débutant à 400 et se terminant à 415 a été copiée à l'adresse 420.

Mettre une plage à la valeur zéro.

La commande Z permet de mettre une plage mémoire à zéro.

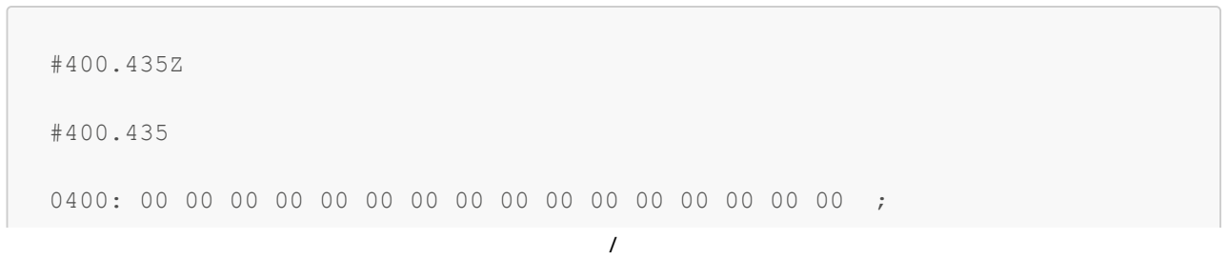
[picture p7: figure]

0400: 00 00 00 00 00 00 00 00 00 00 00 00 00 00 00 00 ;

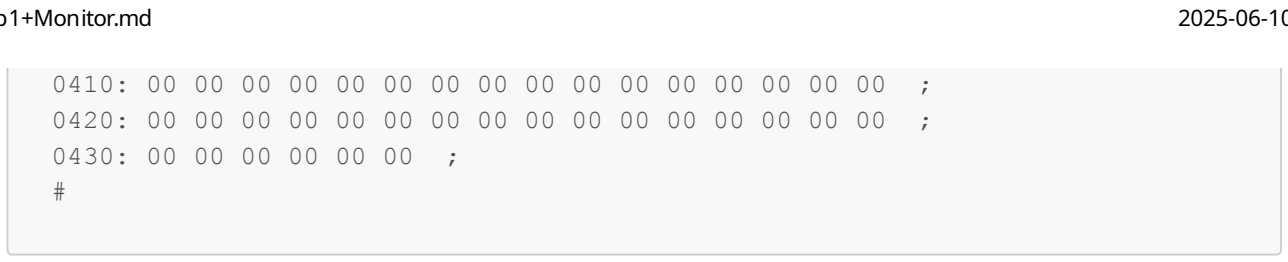
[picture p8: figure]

0410: 00 00 00 00 00 00 00 00 00 00 00 00 00 00 00 00 ; 0420: 00 00 00 00 00 00 00 00 00 00 00 00 00 00 00 00 ;

ComMe on le voie le texte a été remplacé par des zéro.

Mettre une autre valeur que zéro.

Il existe une astuce pour remplir une plage avec une valeur autre que zéro. Il s'agit d'utiliser la commandees :

suivit de la commande M.

#400: "hello world!"

#400.40f

0400: 68 65 6C 6C 6F 20 77 6F 72 6C 64 21 00 00 00 00 ; hello world! #400.4FFM40C

#400.4FF

0400: 68 65 6C 6C 6F 20 77 6F 72 6C 64 21 68 65 6C 6C ; hello world!hell 0410: 6F 20 77 6F 72 6C 64 21 68 65 6C 6C 6F 20 77 6F ; o world!hello wo 0420: 72 6C 64 21 68 65 6C 6C 6F 20 77 6F 72 6C 64 21 ; rld!hello world! 0430: 68 65 6C 6C 6F 20 77 6F 72 6C 64 21 68 65 6C 6C ; hello world!hell 0440: 6F 20 77 6F 72 6C 64 21 68 65 6C 6C 6F 20 77 6F ; o world!hello wo 0450: 72 6C 64 21 68 65 6C 6C 6F 20 77 6F 72 6C 64 21 ; rld!hello world! 0460: 68 65 6C 6C 6F 20 77 6F 72 6C 64 21 68 65 6C 6C ; hello world!hell 0470: 6F 20 77 6F 72 6C 64 21 68 65 6C 6C 6F 20 77 6F ; o world!hello wo 0480: 72 6C 64 21 68 65 6C 6C 6F 20 77 6F 72 6C 64 21 ; rld!hello world! 0490: 68 65 6C 6C 6F 20 77 6F 72 6C 64 21 68 65 6C 6C ; hello world!hell 04A0: 6F 20 77 6F 72 6C 64 21 68 65 6C 6C 6F 20 77 6F ; o world!hello wo 04B0: 72 6C 64 21 68 65 6C 6C 6F 20 77 6F 72 6C 64 21 ; rld!hello world! 04C0: 68 65 6C 6C 6F 20 77 6F 72 6C 64 21 68 65 6C 6C ; hello world!hell 04D0: 6F 20 77 6F 72 6C 64 21 68 65 6C 6C 6F 20 77 6F ; o world!hello wo 04E0: 72 6C 64 21 68 65 6C 6C 6F 20 77 6F 72 6C 64 21 ; rld!hello world! 04F0: 68 65 6C 6C 6F 20 77 6F 72 6C 64 21 68 65 6C 6C ; hello world!hell #

Dans cette exemple on a initialiser la plage 400.41C avec la chaine "hello world!" ensuite on a utiliser la

commande Move pour copier à répétion cette chaîne en décallant l'adresse de destination juste après la

chaîne.

Évidemment on peut remplir avec une valeur unique avec cette astuce.

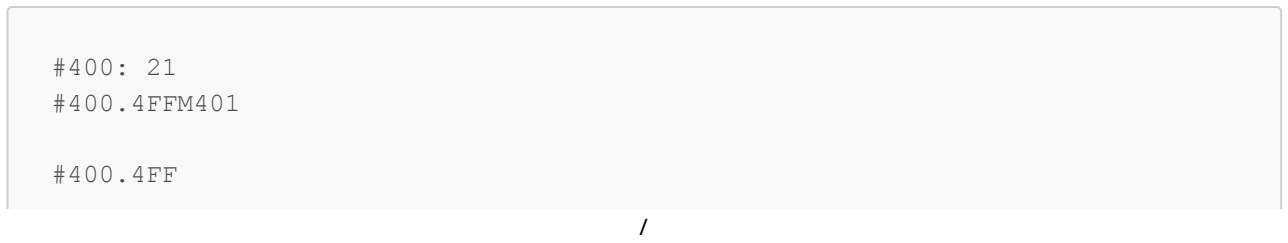
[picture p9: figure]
#400: 21 #400.4FFM401

0400: 21 21 21 21 21 21 21 21 21 21 21 21 21 21 21 21 ; !!!!!!!!!!!!!!!! 0410: 21 21 21 21 21 21 21 21 21 21 21 21 21 21 21 21 ; !!!!!!!!!!!!!!!! 0420: 21 21 21 21 21 21 21 21 21 21 21 21 21 21 21 21 ; !!!!!!!!!!!!!!!! 0430: 21 21 21 21 21 21 21 21 21 21 21 21 21 21 21 21 ; !!!!!!!!!!!!!!!! 0440: 21 21 21 21 21 21 21 21 21 21 21 21 21 21 21 21 ; !!!!!!!!!!!!!!!! 0450: 21 21 21 21 21 21 21 21 21 21 21 21 21 21 21 21 ; !!!!!!!!!!!!!!!! 0460: 21 21 21 21 21 21 21 21 21 21 21 21 21 21 21 21 ; !!!!!!!!!!!!!!!! 0470: 21 21 21 21 21 21 21 21 21 21 21 21 21 21 21 21 ; !!!!!!!!!!!!!!!! 0480: 21 21 21 21 21 21 21 21 21 21 21 21 21 21 21 21 ; !!!!!!!!!!!!!!!! 0490: 21 21 21 21 21 21 21 21 21 21 21 21 21 21 21 21 ; !!!!!!!!!!!!!!!! 04A0: 21 21 21 21 21 21 21 21 21 21 21 21 21 21 21 21 ; !!!!!!!!!!!!!!!! 04B0: 21 21 21 21 21 21 21 21 21 21 21 21 21 21 21 21 ; !!!!!!!!!!!!!!!! 04C0: 21 21 21 21 21 21 21 21 21 21 21 21 21 21 21 21 ; !!!!!!!!!!!!!!!! 04D0: 21 21 21 21 21 21 21 21 21 21 21 21 21 21 21 21 ; !!!!!!!!!!!!!!!! 04E0: 21 21 21 21 21 21 21 21 21 21 21 21 21 21 21 21 ; !!!!!!!!!!!!!!!! 04F0: 21 21 21 21 21 21 21 21 21 21 21 21 21 21 21 21 ; !!!!!!!!!!!!!!!! #

Sauvagarder et restaurer dans la mémoire FLASH

Le pomme I+ possède une mémoire FLASH de 16Mo W25Q128 qui sert de SSD pour l'ordinateur. Il est

possible de sauvegarder une plage mémoire dans celle-ci et de la recharger dans la RAM de l'ordinaeur.

Cette plage doit-être un multiple de 256 octets.

Sauvegarde une plage

La sauvegarde se fait par plage de 256 octets car pour la programmation le W25Q128 n'accepte que 256

octets par étape. La commande W est eectuée pour cette opération.

On va d'abord initialiser une plage mémoire avec un patron facilement reconnaissable.

#300: "The quick brown fox jump over the lazy dog."

#32B.3FFZ

#400: "Le renard rapide saute par dessus le chien paresseux."

#438.4FFZ

#300.4FFW0

#300.4FFZ

Examinons cette plage mémoire avant de la sauvegardée sur le SSD.

0300: 54 68 65 20 71 75 69 63 6B 20 62 72 6F 77 6E 20 ; The quick brown 0310: 66 6F 78 20 6A 75 6D 70 20 6F 76 65 72 20 74 68 ; fox jump over th

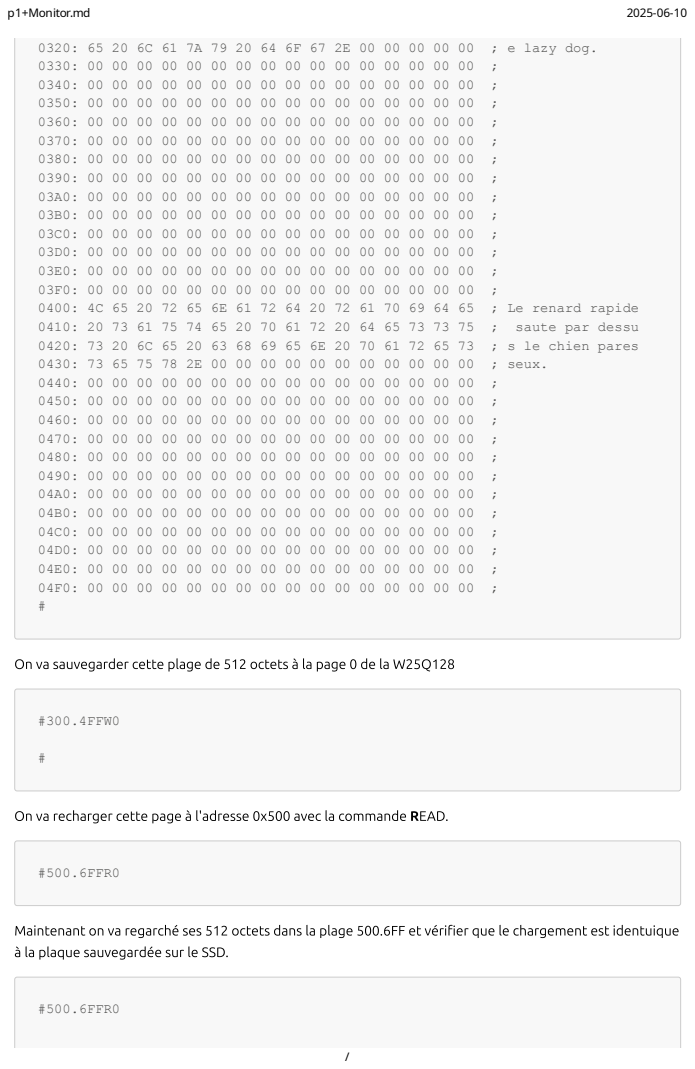
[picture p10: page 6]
0320: 65 20 6C 61 7A 79 20 64 6F 67 2E 00 00 00 00 00 ; e lazy dog. 0330: 00 00 00 00 00 00 00 00 00 00 00 00 00 00 00 00 ; 0340: 00 00 00 00 00 00 00 00 00 00 00 00 00 00 00 00 ; 0350: 00 00 00 00 00 00 00 00 00 00 00 00 00 00 00 00 ; 0360: 00 00 00 00 00 00 00 00 00 00 00 00 00 00 00 00 ; 0370: 00 00 00 00 00 00 00 00 00 00 00 00 00 00 00 00 ; 0380: 00 00 00 00 00 00 00 00 00 00 00 00 00 00 00 00 ; 0390: 00 00 00 00 00 00 00 00 00 00 00 00 00 00 00 00 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

On va sauvegarder cette plage de 512 octets à la page 0 de la W25Q128

On va recharger cette page à l'adresse 0x500 avec la commande READ.

Maintenant on va regarché ses 512 octets dans la plage 500.6FF et vérier que le chargement est identuique

à la plaque sauvegardée sur le SSD.

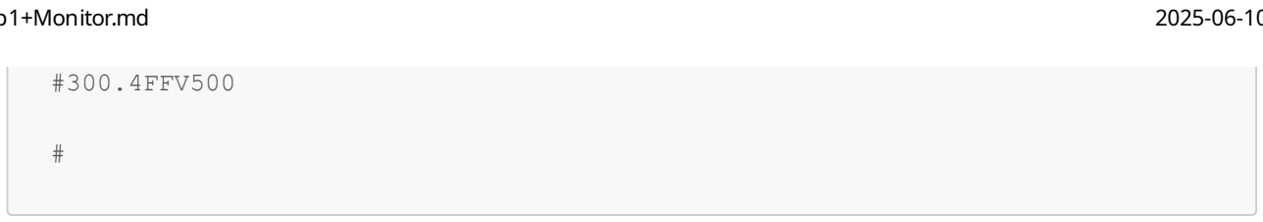
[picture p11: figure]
#300.4FFV500

Il n'y a pas de diérences d'achées donc c'est correct. Achons la plage pour voir son contenu.

#500.6FF

0500: 54 68 65 20 71 75 69 63 6B 20 62 72 6F 77 6E 20 ; The quick brown 0510: 66 6F 78 20 6A 75 6D 70 20 6F 76 65 72 20 74 68 ; fox jump over th 0520: 65 20 6C 61 7A 79 20 64 6F 67 2E 00 00 00 00 00 ; e lazy dog. 0530: 00 00 00 00 00 00 00 00 00 00 00 00 00 00 00 00 ;
0540: 00 00 00 00 00 00 00 00 00 00 00 00 00 00 00 00 ;
0550: 00 00 00 00 00 00 00 00 00 00 00 00 00 00 00 00 ;
0560: 00 00 00 00 00 00 00 00 00 00 00 00 00 00 00 00 ; 0570: 00 00 00 00 00 00 00 00 00 00 00 00 00 00 00 00 ; 0580: 00 00 00 00 00 00 00 00 00 00 00 00 00 00 00 00 ; 0590: 00 00 00 00 00 00 00 00 00 00 00 00 00 00 00 00 ; 05A0: 00 00 00 00 00 00 00 00 00 00 00 00 00 00 00 00 ; 05B0: 00 00 00 00 00 00 00 00 00 00 00 00 00 00 00 00 ; 05C0: 00 00 00 00 00 00 00 00 00 00 00 00 00 00 00 00 ; 05D0: 00 00 00 00 00 00 00 00 00 00 00 00 00 00 00 00 ;
05E0: 00 00 00 00 00 00 00 00 00 00 00 00 00 00 00 00 ;
05F0: 00 00 00 00 00 00 00 00 00 00 00 00 00 00 00 00 ;
0600: 4C 65 20 72 65 6E 61 72 64 20 72 61 70 69 64 65 ; Le renard rapide 0610: 20 73 61 75 74 65 20 70 61 72 20 64 65 73 73 75 ; saute par dessu 0620: 73 20 6C 65 20 63 68 69 65 6E 20 70 61 72 65 73 ; s le chien pares 0630: 73 65 75 78 2E 00 00 00 00 00 00 00 00 00 00 00 ; seux.
0640: 00 00 00 00 00 00 00 00 00 00 00 00 00 00 00 00 ;
0650: 00 00 00 00 00 00 00 00 00 00 00 00 00 00 00 00 ;
0660: 00 00 00 00 00 00 00 00 00 00 00 00 00 00 00 00 ; 0670: 00 00 00 00 00 00 00 00 00 00 00 00 00 00 00 00 ; 0680: 00 00 00 00 00 00 00 00 00 00 00 00 00 00 00 00 ; 0690: 00 00 00 00 00 00 00 00 00 00 00 00 00 00 00 00 ; 06A0: 00 00 00 00 00 00 00 00 00 00 00 00 00 00 00 00 ; 06B0: 00 00 00 00 00 00 00 00 00 00 00 00 00 00 00 00 ; 06C0: 00 00 00 00 00 00 00 00 00 00 00 00 00 00 00 00 ; 06D0: 00 00 00 00 00 00 00 00 00 00 00 00 00 00 00 00 ; 06E0: 00 00 00 00 00 00 00 00 00 00 00 00 00 00 00 00 ; 06F0: 00 00 00 00 00 00 00 00 00 00 00 00 00 00 00 00 ; #

Vérier le contenu.

Dans l'exemple précédent il est facile de vérier que l'opération s'est eectuée correctement, mais s'il

s'agissait de code binaire ce ne serait pas si simple. La commande Verify peut le faire pour nous.

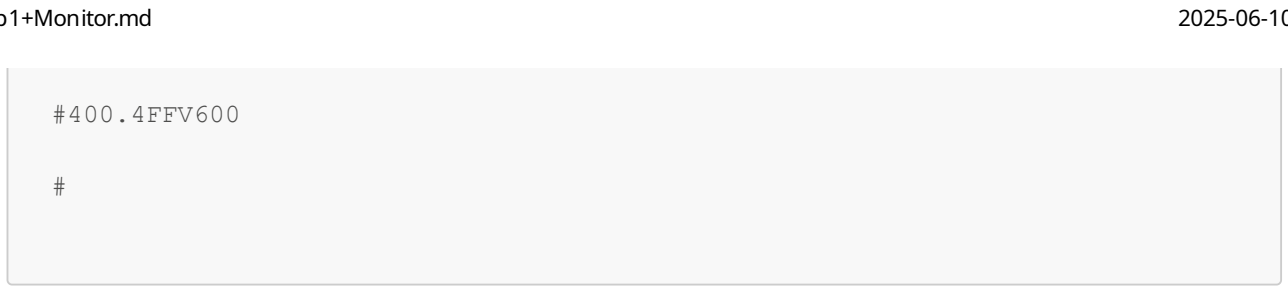
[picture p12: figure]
#400.4FFV600

La vérication n'a rien achée donc les 2 plages sont identiques. Modions quelques octets à l'adresse 400

et répétons la vérication.

#400:"bonjour"

#400.4ffv600

0400 62 0600 48
0401 6F 0601 45
0402 6E 0602 4C
0403 6A 0603 4C
0404 6F 0604 4F
0405 75 0605 20
0406 72 0606 57
0407 00 0607 4F

Le bonjour a remplacé le début de HELLO WORLD! donc la commande ache les 7 adresses mémoires qui

divergent.

Eacer un secteur du SSD

la Commande X permet d'eacer un secteur de la W25Q128. Le plus petit bloc de la mémoire FLASH qui

peut-être eacé est de 4096 octets. Puisque le W25Q128 possède 16MO de mémoire il y a 65536 secteurs

eacables {0..FFFF}. Puisqu'on a enregistré quelque chose à la page 0x10 on va eacer le secteur qui

contient cette page. Puisqu'il y a 16 pages par secteur la page 0x10 est la première page du secteur 1.

#1x

CONFIRM FLASH ERASE(Y/N)

#300r10

#300.3ff

0300: FF FF FF FF FF FF FF FF FF FF FF FF FF FF FF FF ; 0310: FF FF FF FF FF FF FF FF FF FF FF FF FF FF FF FF ; 0320: FF FF FF FF FF FF FF FF FF FF FF FF FF FF FF FF ; 0330: FF FF FF FF FF FF FF FF FF FF FF FF FF FF FF FF ; 0340: FF FF FF FF FF FF FF FF FF FF FF FF FF FF FF FF ; 0350: FF FF FF FF FF FF FF FF FF FF FF FF FF FF FF FF ; 0360: FF FF FF FF FF FF FF FF FF FF FF FF FF FF FF FF ; 0370: FF FF FF FF FF FF FF FF FF FF FF FF FF FF FF FF ; 0380: FF FF FF FF FF FF FF FF FF FF FF FF FF FF FF FF ;

0390: FF FF FF FF FF FF FF FF FF FF FF FF FF FF FF FF ; 03A0: FF FF FF FF FF FF FF FF FF FF FF FF FF FF FF FF ; 03B0: FF FF FF FF FF FF FF FF FF FF FF FF FF FF FF FF ; 03C0: FF FF FF FF FF FF FF FF FF FF FF FF FF FF FF FF ; 03D0: FF FF FF FF FF FF FF FF FF FF FF FF FF FF FF FF ; 03E0: FF FF FF FF FF FF FF FF FF FF FF FF FF FF FF FF ; 03F0: FF FF FF FF FF FF FF FF FF FF FF FF FF FF FF FF ;

Une demande de conrmation est faite à laquelle on doit répondre Y pour eectuer l'opération.

Lorsque un secteur est eacé toutes les valeurs sont mise à 0xFF

Eacer tout le SSD

La commande * permet d'eacer tout le chip W25Q128. Cette opération dure plus de 40 secondes.

*
THIS WILL ERASE WHOLE SSD, (Y/N)?
Be patient it take 40+ seconds

#300r0

#300.3ff

0300: FF FF FF FF FF FF FF FF FF FF FF FF FF FF FF FF ; 0310: FF FF FF FF FF FF FF FF FF FF FF FF FF FF FF FF ; 0320: FF FF FF FF FF FF FF FF FF FF FF FF FF FF FF FF ; 0330: FF FF FF FF FF FF FF FF FF FF FF FF FF FF FF FF ; 0340: FF FF FF FF FF FF FF FF FF FF FF FF FF FF FF FF ; 0350: FF FF FF FF FF FF FF FF FF FF FF FF FF FF FF FF ; 0360: FF FF FF FF FF FF FF FF FF FF FF FF FF FF FF FF ; 0370: FF FF FF FF FF FF FF FF FF FF FF FF FF FF FF FF ; 0380: FF FF FF FF FF FF FF FF FF FF FF FF FF FF FF FF ; 0390: FF FF FF FF FF FF FF FF FF FF FF FF FF FF FF FF ; 03A0: FF FF FF FF FF FF FF FF FF FF FF FF FF FF FF FF ; 03B0: FF FF FF FF FF FF FF FF FF FF FF FF FF FF FF FF ; 03C0: FF FF FF FF FF FF FF FF FF FF FF FF FF FF FF FF ; 03D0: FF FF FF FF FF FF FF FF FF FF FF FF FF FF FF FF ; 03E0: FF FF FF FF FF FF FF FF FF FF FF FF FF FF FF FF ; 03F0: FF FF FF FF FF FF FF FF FF FF FF FF FF FF FF FF ; #

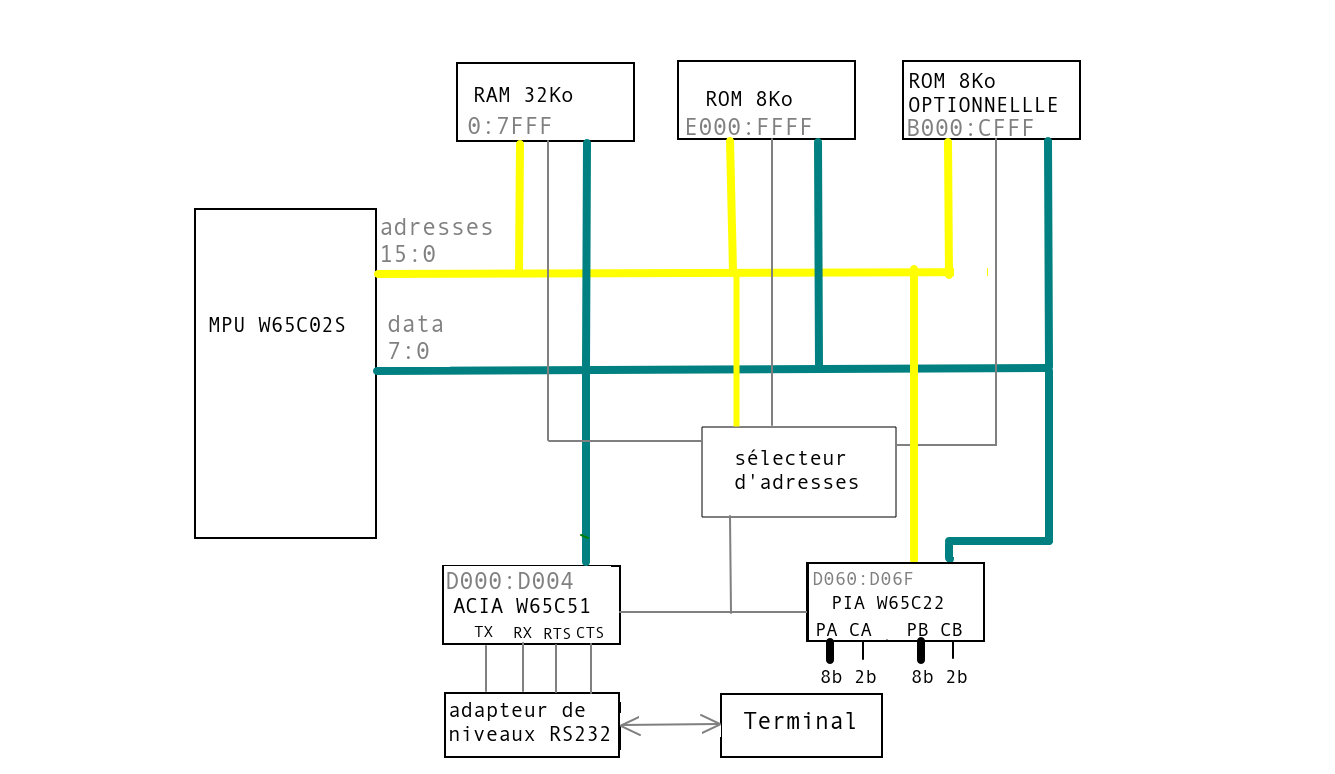
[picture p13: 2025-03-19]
docs/diagramme-bloc.png

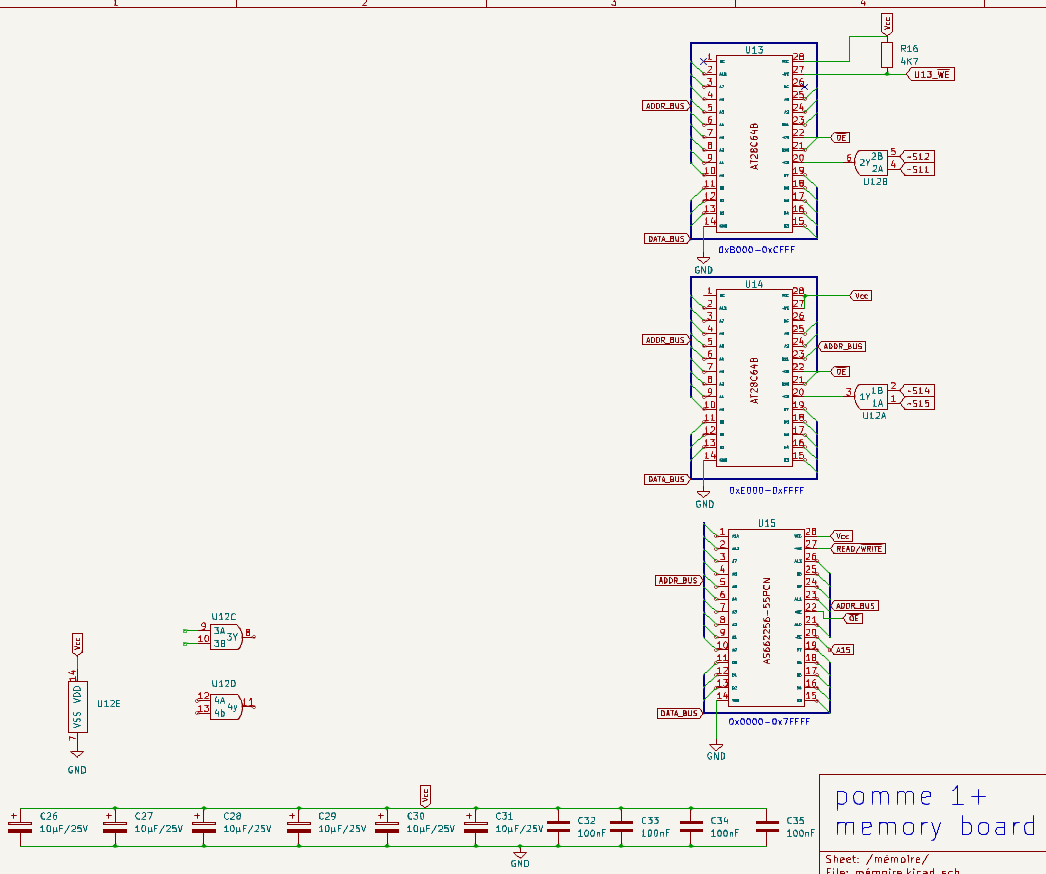
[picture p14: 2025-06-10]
docs/memory_board.png

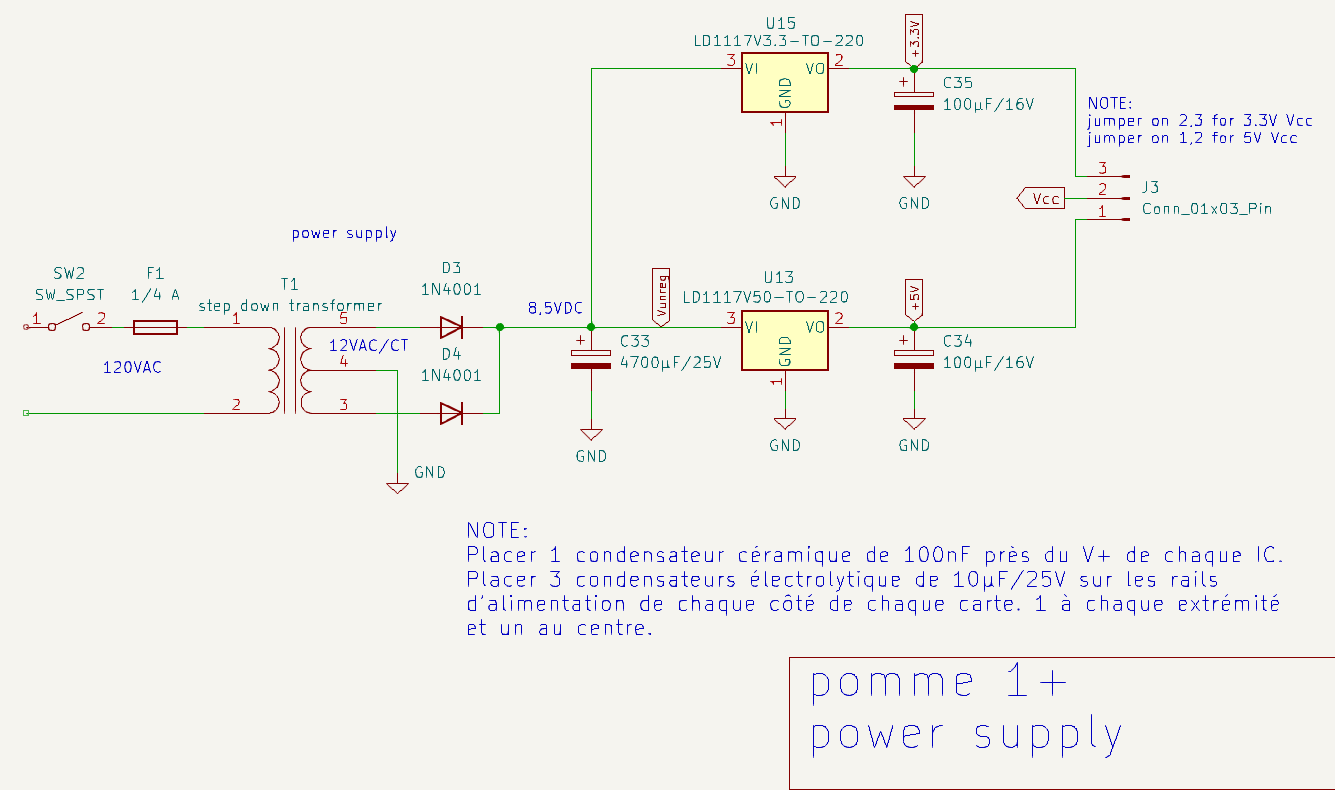
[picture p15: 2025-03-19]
docs/power_supply.png

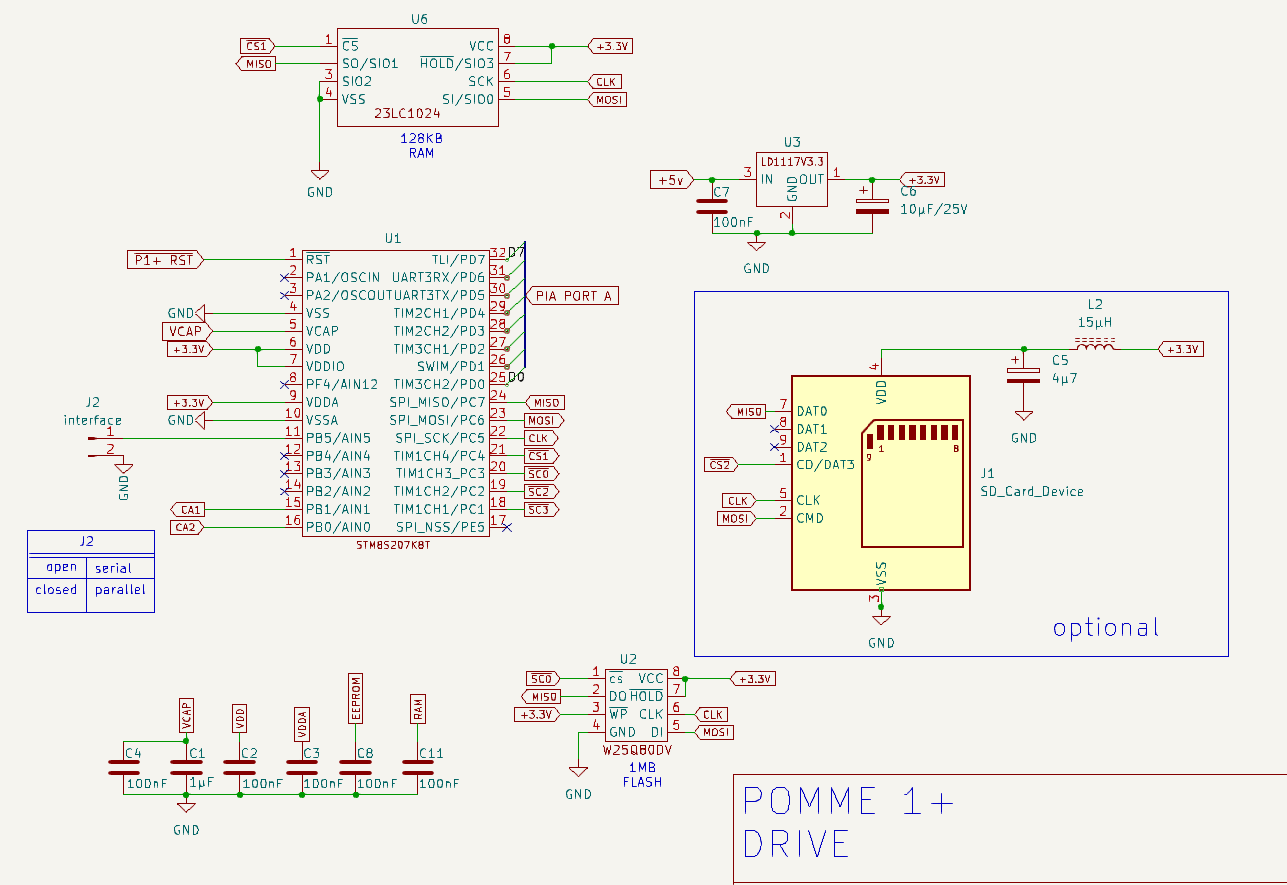
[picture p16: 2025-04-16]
p1+_drive/docs/p1+_drive.png

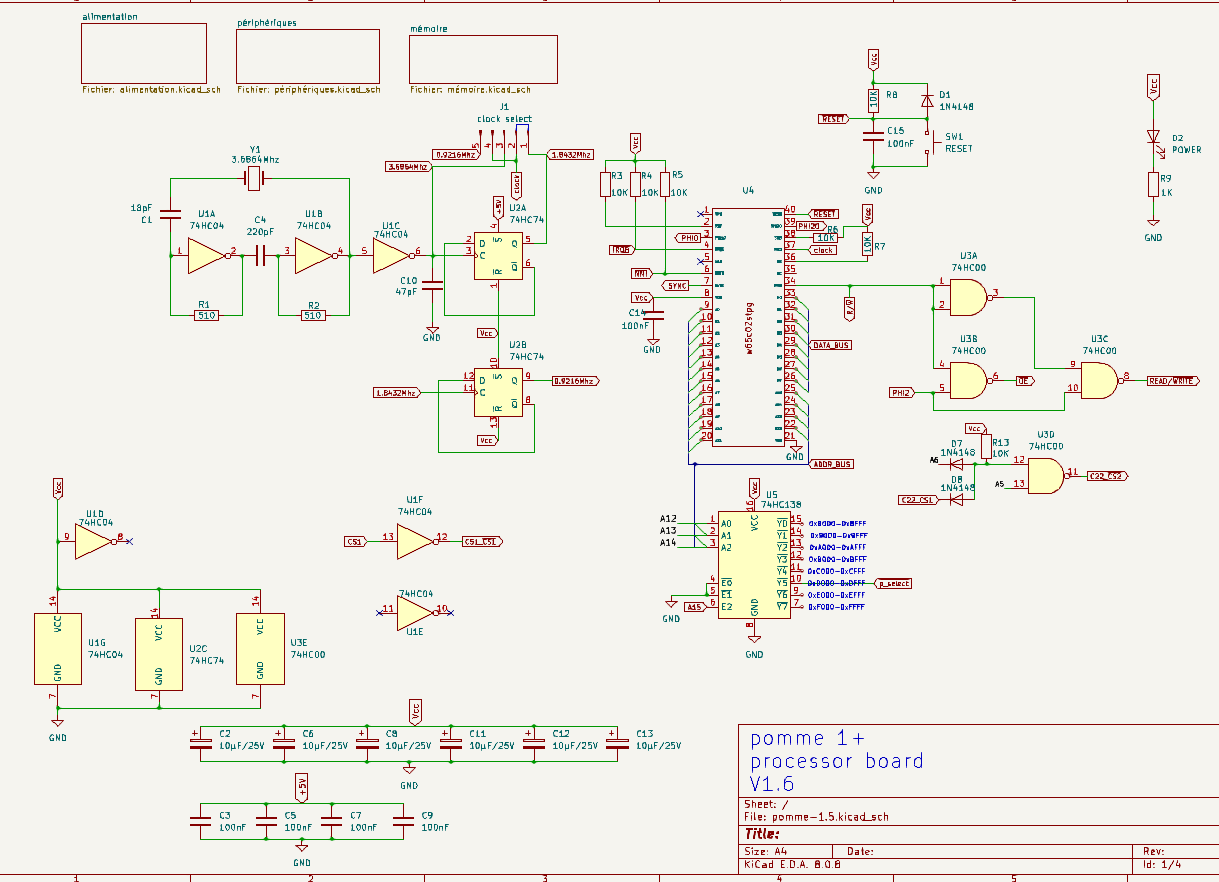
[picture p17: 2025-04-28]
docs/mpu_board.png

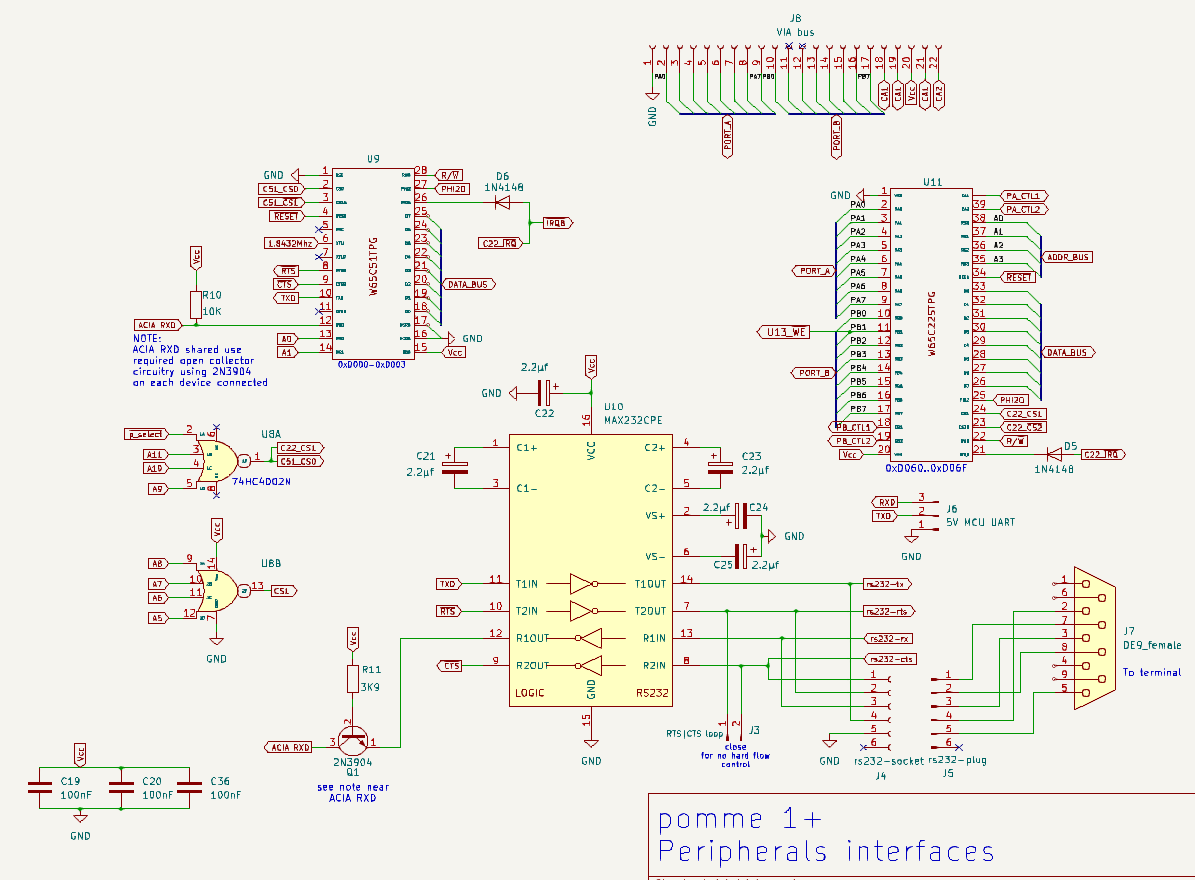
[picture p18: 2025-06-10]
docs/peripherals_board.png

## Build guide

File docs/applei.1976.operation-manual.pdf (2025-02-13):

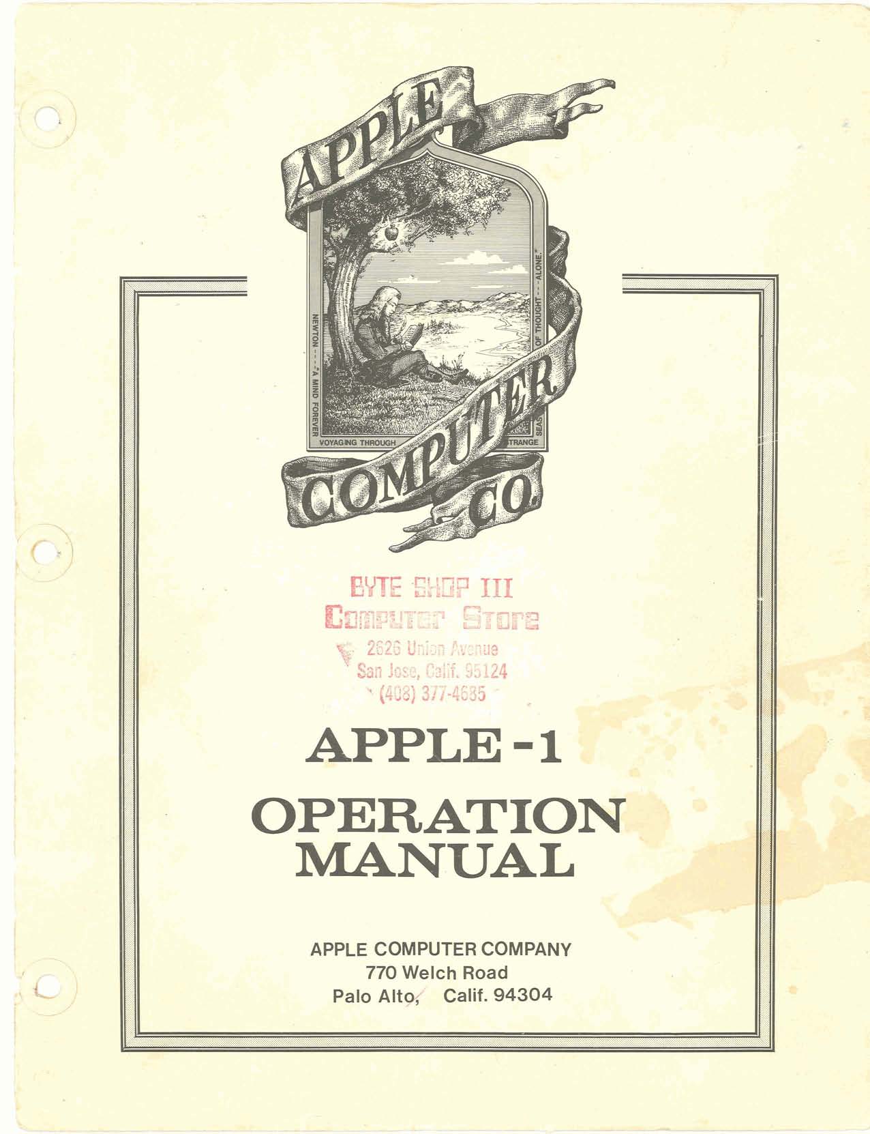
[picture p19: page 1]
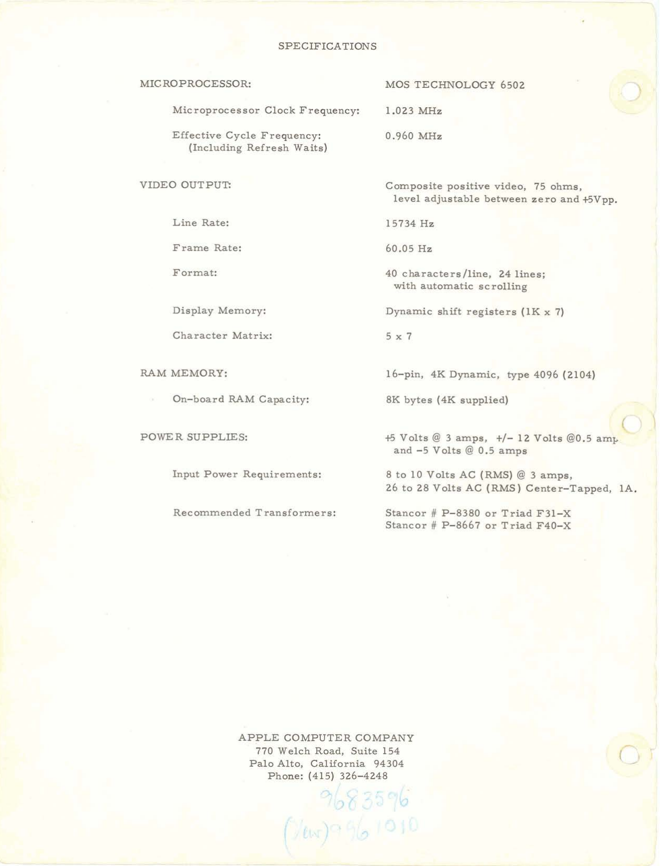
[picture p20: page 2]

SPECIFICATIONS

MICROPROCESSOR:

Microprocessor Clock Frequency:

Effective Cycle Frequency: (Including Ref re sh Waits)

VIDEO OUTPUT:

Line Rate:

Frame Rate:

Format:

Display Memory:

Character Matrix:

RAM MEMORY:

On-board RAM Capacity:

POWER SUPPLES:

Input Power Requirements:

Recommended Transformers:

MOS TECHNOLOGY 6502

1.023 MHz

0.960 MHz

Composite positive video, 75 ohms, level adjustable between zero and -15Vpp.

40 characters/line, 24 lines; with automatic scrolling

Dynamic shift registers (1K x 7)

16-pin, 4K Dynamic, type 4096 (21 04)

8K bytes (4K supplied)

+5 Volts @ 3 amps, +/- 12 Volts @0.5 amp and -5 Volts @ 0.5 amps

8 to 10 Volts AC (RMS) @ 3 amps,
26 to 28 Volts AC (RMS) Center-Tapped, 1A.

Stancor # P-8380 or Triad F31-X
Stancor # P-8667 or Triad F40-X

APPLE COMPUTER COMPANY
770 Welch Road, Suite 154
Palo Alto, California 94304 Phone: (415) 326-4248

The Apple Computer is a complete micro-'~,ocessor system, consisting of a Mos Technology 2 microprocessor and support hardware, in-Jral video display electronics, dynamic memory and refresh hardware, and fully regulated power supplies. It contains resident system monitor software, enabling the user, via the keyboard and display, to write, examine, debug, and run programs efficiently; thus being an educational tool for the learning of microprocessor programming, and an aid in the development of software.

The integral video display section and the keyboard interface renders unnecessary the need for an external teletype. The display section contains its ownmemory, leaving all of RAM for user programs, and the outputformat is 40 characters/ line, 24 lines /page, with auto scrolling. Almost any ASCII encoded keyboard will interface directly with the Apple system.

The board has sockets for upto 8K bytes of the 16 pin, 4K type, RAM, and the system is fully expandable to 65K via the edge connector. The system uses dynamic memory (4K bytes supplied), although static memory may also be used. All refreshing of dynamic memory,' including all " off -board" expansion memory, is done auto-

matically. The entire system timing, including the microprocessor clock and all video signals, originates in a single crystal oscillator.

Further, the printed circuit board contains a "breadboard area", in which the user can add additional " on -board " hardware ( for example,

extra PIAfs, ACIAfs, EROMfs, and so on).

This manual is divided into three Sections:

Section I GETTING THE SYSTEM RUNNING. Section I1 USING THE SYSTEM MONITOR. (listing included)
Section I11 EXPANDING THE SYSTEM.

Please readsection I thoroughly, before attempting to "power-up" your system, and study Section I11 carefully before attempting to expand your system. In addition to this manual, Apple "Tech Notes" are available which contain example s of expansion hardware and technique s.

*
SECTION I
GETTING THE SYSTEM RUNNING

The Apple Computer is fully assembled, tested, and burned in. The only external devices necessary for operation of the system are: An ASCII encoded keyboard, a video display monitor, and AC power sources of 8 to 10 Volts (RMS) @3 amps and 28Volts (RMS) @1amp. The following three articles describe the attachment of these devices in detail.

Keyboard:
Any ASCII encoded keyboard, with positive DATA outputs, interfaces directly with the Apple system via a "DIP" connector. If your keyboard has negative logic DATA outputs (rare), you can install inverters (7404) in the breadboard area. The strobe can be either positive or negative, of long or short duration. The "DIP" keyboard connector (B4) has inputs for seven DATA lines, one

1
87

ST ROBE line, and two normally-open pushbutton switches, used for RESET (enter monitor), and CLEAR SCREEN (see schematic diagram, sheet

### 3 of 3, for exact circuitry). This keyboard con-

nector also supplies three voltages, (+5V, +12V, and-12V) of which one or more may be necessary to operate the keyboard. Pin 15 of the keyboard connector (B4) must be tied to +5V (pin 16) for normal operation.

NOTE: The system monitor accepts only uppercase alpha (A-F, R).
It is therefore convenient, though it's not essential, tohave a keyboard equipped with uppercasealphalock (usuallyintheelectronics). Either of the following suggested circuits may be used to provide alpha lock capability, if needed, and
can be built in the breadboard area.

Vcc(+S)

Bp-wB6 13 | TO KBD
FROM l5 | 00
KBD 14 | CONNECTOR 184)

Display:
The Apple Computer outputs a composite video signal (composite of sync and video information) which can be applied to any standard raster-scan type video display monitor. The output level is adjustable with the potentiometer located near the video output Molex connector, J2. The additional two outside pins on the Molex connector supply $5 andi-12 volts, to be used in future Apple accessories. The composite video signal can also be modulated at the proper RFfrequency, with an inexpensive commercially available device , and applied to the antenna terminals of a home television receiver. Since the character format is 40 characters /line, all television receivers will have the necessary bandwidth to display the entire 40 characters. Two large manufacturers of video display monitors, which connect directly with the Apple Computer, are Motorola and Ball. The mating four-pin Molex connector is provided.

AC Power Sources:
Two incoming AC power sources are required for operation: 8 to 10 VAC (RMS) at 3 amps, and 28VAC (RMS) Center-Tapped

at 1amp. These
AC supplies enter the system at the Molex connector, Jl. The 8 to10 volts AC provides the raw AC for the +5 volt supply, while the 28 VCT supplies the raw AC for the +12 and -12 volt supplies, and the -5V supply is derived from the -1 2V reg-
ulated output. | I

The board, as supplied, requires no more than 1.5 amps DC from the t5V supply, while the regulator is capable of supplying 3 amps. The remaining 1.5 amps DC from the t5V supply is available for user hardware expansion (provided ratings are employed).

rce of the raw AC voltages , are two commercially available trans-,Stancor P/N P-8380 or equivalent (8 to at 3 amps), and Stancor PIN P-8667 or equivalent ( 28VCT at 1 amp ) . Simply wire the

secondaries to the mating six-pin Molex connector supplied, and wire the primaries in parallel, as -
shown in the schematic diagram (power supd section, Dwg. No. 00101, sheet 3 of 3.
TEST PROGRAM | &

After attaching the keyboard, display, and
AC power sources, you can try a simple program to test if your system and the attachments are functioning together properly. While it does not test many possible areas of the microprocessor system, the test program will test for the correct attachment of the keyboard, display, and power supplies.

FIRST:
Hit the RESET button to enter the system monitor. A backslash should be displayed, and the cursor should drop to the next line.
SECOND: | 4Y
Type- | 0 :A9 b 0 b AA b 20 b EF b FF b
E8 b 8A b 4C b'2 bib-(RE~)
(0 is a zero, NOT an alpha "0"; b means blank or space; and (RET) hit the "return" key on the keyboard)

THIRD:
Type- 0 . A (RET)

(This should print out, on the display, program you have just entered. )

FOURTH:
Type- R (RET)
(R means run the program. )

THE PROGRAM SHOULD THEN PRINT OUT ON THE DISPLAY A CONTINUOUS STREAM OF ASCII CHARACTERS. TO STOP THE PRO-GRAM AND RETURN TO THE SYSTEM MONITOR, HIT THE "RESET" BUTTON. TO RUN AGAIN, TYPE : R (RET).

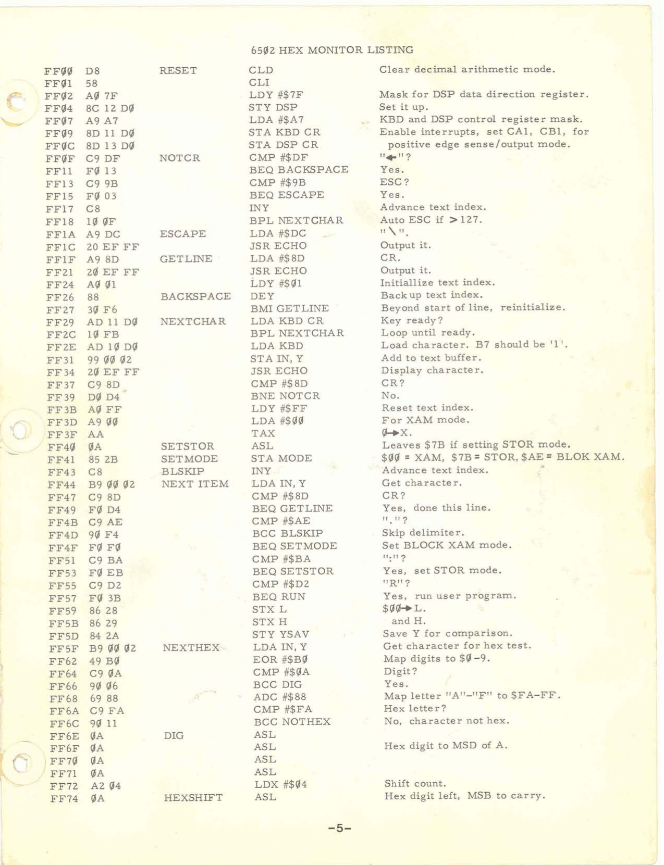
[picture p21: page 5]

ifhmetic mode.

| | LDY #$7F | | Mask for DSP data direction register.
| | STY DSP | | Set it up.
| | LDA #$A7 | | KBD and DSP control register mask.
FF09 8D 11 D0 | | STA KBD CR | | Enable interrupts, set CAI, CB1, for
FFgC 8D 13 D0 | | STA DSP CR | | positive edge sense/output mode.
FF0F C9 DF | NOTCR | CMP #$DF | | 11 ?
FFll F0 13 | BEQ BACKSPACE | Yes.
FF13 C9 9B | | CMP #$9B | | ESC ?
FF15 F0 03 | | BEQ ESCAPE | | Yes.
FF17 C8 | | INY | | Advance text index.
FF18 10 0F | BPL NEXTCHAR | Auto ESC if >127.
FFlA A9 DC | ESCAPE | LDA #$DC | * | 11 \It,
FFlC 20 EF FF | | JSR ECHO | | Output it.
FFlF A9 8D | GETLINE | LDA #$8D | | CR.
FF21 241 EF FF | | JSR ECHO | | Output it.
FF24 A0 01 | | LDY #$a1 | | Initiallize text index.
FF26 88 FF27 30 F6 | BACKSPACE | DEY
BMI GETLINE
| | | | Back up text index.
| | | | Beyond start of line, reinitialize.
FFZ~AD 11 DQ | NEXTCHAR | LDA KBD CR | Key ready?
FFZC 10 FB
FFZE AD 10D0

BPL NEXTCHAR

| | LDA KBD | | Loop until ready. Load character. B7 should be '1 I.
FF31 99 00 02 | | STA IN, Y | | Add to text buffer.
FF34 20 EF FF | | JSR ECHO | | Display character.
FF37 C9 8DI | | CMP #$8D | | CR?
FF39 D0 D4 | | BNE NOTCR | | No.
FF3B A0 FF | | LDY #$FF | | Reset text index.
FF3D A9 00 | | LDA #$a0 | | For XAM mode.
FF3F AA | | TAX
FF40 4A | SETSTOR | ASL
FF41 85 2B | SETMODE | STA MODE
FF43 C8 | BLSKIP | INY | - | 'Advance text index.
I
i
FF44 B9 09 02 FF47 C9 8D | NEXT ITEM | LDA IN, Y
| | CMP #$8D | | Get character.
| | | | CR?
FF49 F0 D4 | BEQ GETLINE
FF4B C9 AE | | CMP #$AE
FF4D 90 F4 | BCC BLSKIP | Skip delimiter.
FF4F Fg F0 | BEQ SETMODE
FF51 C9 BA
FF53 F0 EB
FF55 C9 D2 | | CMP #$D2 | | Yes, set STOR mode. "R"?
l | FF57 F0 3B
FF59 86 28 | | BEQ RUN
| | STX L | | Yes, run user prbgram
! | FF5B 86 29 | STX H
FF5D 84 2A | | STY YSAV
FF5F B9 (40 02 | NEXTHEX-. | LDA IN, Y
FF62 49 B0 | | EOR #$I30 | | Map digits to $@-9.
FF64 C9 0A | | CMP #$@A
FF66 90 06 | | BCC DIG
FF68 69 88 | | ADC #$88
FF~A C9 FA | | C.MP #$FA | | Hex letter?
BCC NOTHEX | . | No, character not hzx.
| | | | Hex digit .to MSD of
| | | | Shift count.

Fd 97

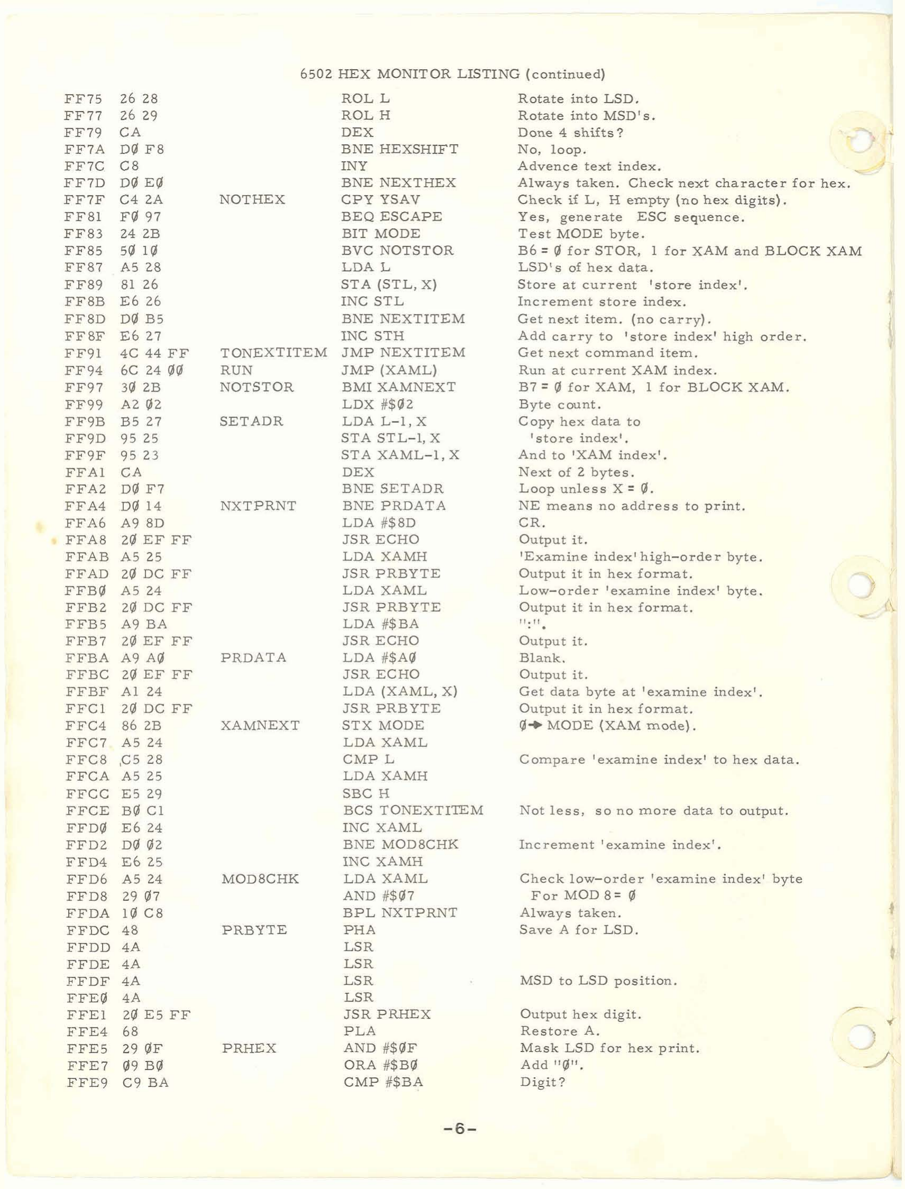
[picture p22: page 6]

i

6502 HEX MONITOR LISTING (continued) FF75
FF77
FF79
FF7A
FF7C
FF7D
FF7F
FF81
FF83
FF85
FF87
FF89
FF8B
FF8D
FF8F
FF91
FF94
FF97
FF99
FF9B
FF9D
FF9F
FFAl

26 28
26 29
CA
Db F8
C8
DQ EQ
C4 2A

24 2B
50 10
A5 28
81 26
E6 26
DQ B5
E6 27
4C 44 FF
6C 24 00
30 2B
A2 02
B5 27
95 25
95 23
CA
| ROL L | Rotate into LSD.
| ROL H | Rotate into MSD's.
| DEX | Done 4 shXts?
| BNE HEXSHIFT | No, loop.
| INY | Advence text index.
| BNE NEXTHEX | Always taken. Check next character for he,
| CPY YSAV | Check ifL, H empty (no hex digits).
| BEQ ESCAPE | Yes, generate ESC sequence.
| BIT MODE | Test MODE byte.
| BVC NOTSTOR | B6 = 0 for STOR, 1 for XAM and BLOCK XAM
| LDA L | LSD's of hex data.
| STA (STL, X) | Store at current 'store index'.
| INC STL | Increment store index.
| BNE NEXTITEM | Get next item. (no carry).
| INC STH | Add carry to 'store index' high order.
TONEXTITEM JMP NEXTITEM | Get next command item.
RUN | JMP (XAML) | Run at current XAM index.
NOTSTOR | BMI XAMNEXT | B7 = 0 for XAM, 1 for BLOCK XAM.
| LDX #$02 | Byte count.
SETADR | LDA L-1 ,X | Copy hex data to
| STA STL-1, X | 'store index'.
| STA XAML-1, X | And to 'XAM index'.
| DEX
| BNE SETADR | Next of 2 bytes.
| | Loop unless X = 0.
NXTPRNT | BNE PRDATA | NE means no address to print.
| LDA #$8D | CR.
| JSR ECHO | Output it.
| LDA XAMH | 'Examine index'high-order byte.
| JSR PRBYTE | Output it in hex format.
| LDA XAML | Low-order 'examine index' byte.
| JSR PRBYTE | Output it in hex format.
| LDA #$BA | ,I:,#
| JSR ECHO | Output it.
PRDATA | LDA #$A0 | Blank.
| JSR ECHO | Output it.
| LDA (XAML, X) | Get data byte at 'examine index'.
| JSR PRBYTE | Output it in hex format.
XAMNEXT | STX MODE | 0-C MODE (XAM mode).
| LDA XAML
| CMP L | Compare 'examine index' to hex data.
| LDA XAMH
| SBC H
| BCS TONEXTITEM | Not less, so no more data to output.
| INC XAML
| BNE MOD8CHK | Increment 'examine index'.
| INC XAMH
MODBCHK | LDA XAML
| AND #$07 | Check low-order 'examine index' byte
| | For MOD 8' 0
| BPL NXTPRNT | Always taken.
PRBYTE | PHA | Save A for LSD.
| LSR
| LSR
| LSR | MSD to LSD position.
| LSR
| JSR PRHEX | Output hex digit.
| PL A | Restore A.
PRHE X | AND #$@F | Mask LSD for hex print.
| ORA #$BQ | Add "0".
| CMP #$BA | Digit?

d~~A2 D0 F7
L%IX;

FFAB
FFAD
FFBQ
FFB2
FFB5
FFB7
FFBA
FFBC
FFBF
FFCl
FFC4
FFC7
FFC8
FFCA
FFCC
FFCE

$fi,

A5 25
20 DC FF
A5 24
20 DC FF
A9 BA
20 EF FF
A9 A0
20 EF FF
A1 24
20 DC FF
86 2B
A5 24
,C5 28
A5 25
E5 29
B0 Cl
FFDQ E6 24
FFD2
FFD4
FFD6
FED8
FFDA
FFDC
FFDD
FFDE
FFDF
FFE0
FFEl
FFE4
FFE5
FFE7
FFE9

D0 02
E6 25
A5 24
29 07
10 C8
48
4A
4A
4A
4A
20E5FF
68
29 0F
09 B0
C9 BA

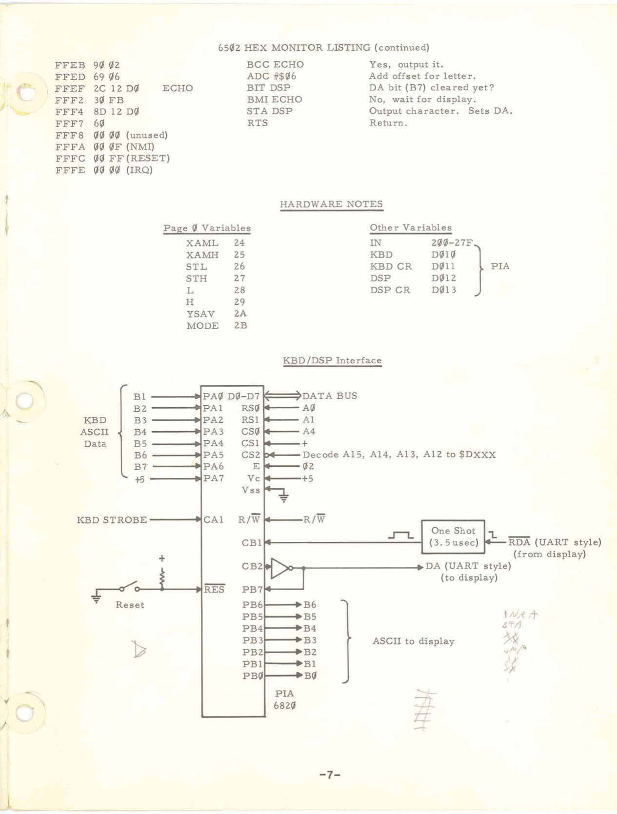
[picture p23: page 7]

Page 0 Variables
XAML | 24
XAMH | 25
STL | 26
STH | 27
L | 28
H | 29
YSAV | 2A
MODE | 2B

HARDWARE NOTES

Other Variables
IN | 200-27F
KBD
KBDCR Doll
DSP
DSP CR DQ13

SECTION I11
HOW TO EXPAND THE APPLE SYSTEM

The Apple system can be expanded to include more memory and I0 devices, via a 44-pin edge connector. The system is fully expandable to 65K, with the entire data and address busses, clocks, control signals ( i. e. IRQ, NMI, DMA, RDY, etc.), and power sources available at the connector. All address lines are TTL buffered, and data lines can drive ten equivalent capacitive loads (one TTL load and 130pf) without external buffers. All clock signals are TTL. The Apple system runs at approximately 1 MHz ( see spec sheet) and is fully compatible with 6800/6500 style timing.

Three power sources are available at the edge connector: f5 volts regulated, and raw DC (approximately +/- 14V) for the +12'V, -12V, and -5V supplies. If +12V, -12V, or -5V supplies are required, EXTERNAL REGULATORS MUST BE USED. An excess of 1.5 amps from the "onboardu regulated f5V supply is available for expansion (assuming suitable transformer ratings are employed). Exercise great care in the handling of the raw DC, as no short-circuit protection is provided.

REFRESH:
Four out of every 65 clock cycles is dedicated to memory refresh. At the start of a re-
- fresh cycle (150 ns after leading edge of 01), RF

goes low, and remains low for one clock cycle. $42 is inhibited during a refresh cycle, and the processor is held in 01 (it's inactive state). Dynamic memories, which must clock during refresh cycles, should derive their clock from 00, which is equivalent to 02, except that it continues during a refresh cycle. Devices, such as PIA1s, will not be affected by a refresh cycle, since they react to 02 only. Refer to Apple "TechNotesl' for a variety of inte riacing examples .

DMA:
The Apple system has full DMA capabli
For DMA, the DMA control line tri- states ,
address buss, thus allowing external devices t, | '
control the buss. | Consult MOS TECHNOLOGY
6502 Hardware Manual for details. (For DMA use, the solder jumper on the board, marked "DMA", must be broken. )

For the 6502 microprocessor, the RDY line is used to halt the processor for single stepping, or slow ROM applications. Refer to Apple "Tech Notes" for examples.

SOFTWARE CONSIDERATIONS:
The sequences listedbelow are the routines used to read the keyboard or output to the display,

Read Key from KBD:
LDA KBD CR (D011)

LDA KBD DATA (DQlo)

Output to Display:
BIT DSP (D012)

STA DSP (Do12)

PIA Internal Registers:
KBD Data | I3010
High order bit equals 1.

KBD Control Reg. Doll
High order bit indicates "key ready". Reading key clears flag. Rising edge of KBD sets flag.
DSP DATA | D012
Lower seven bits are data output, high order bit is display ready" input (1 equals ready, 0 equals busy)

DSP Control Reg. D013

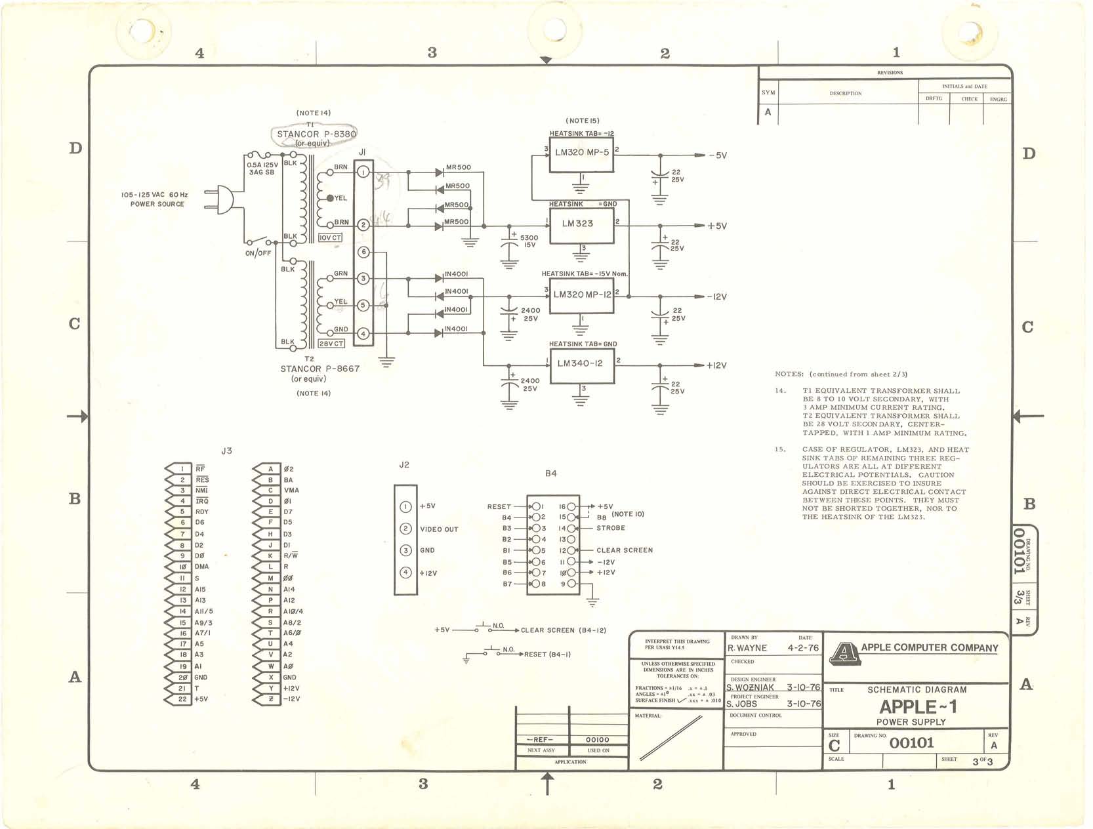
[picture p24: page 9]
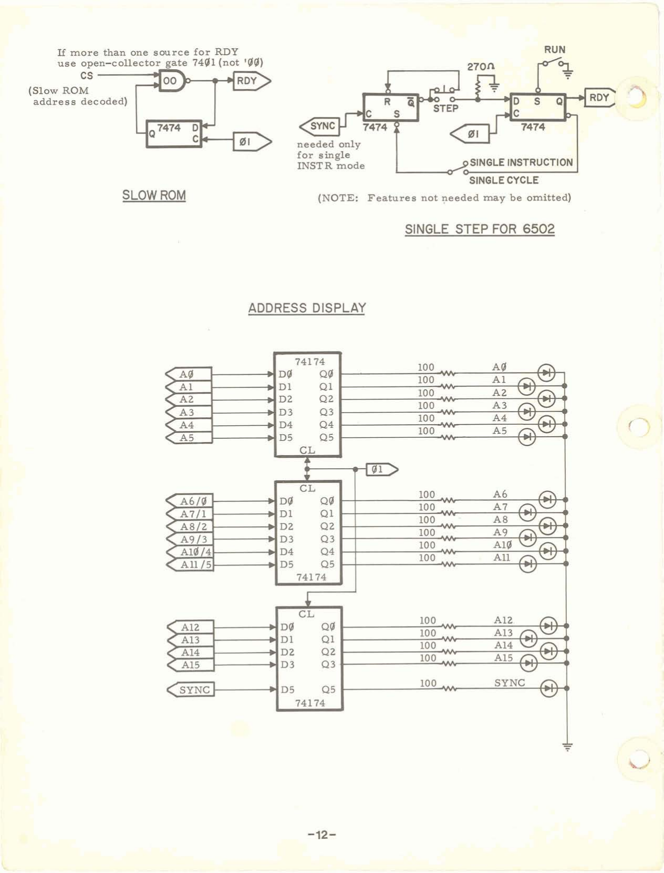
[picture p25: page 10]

If more than one source for RDY | RUN
use owen-collector gate 7401 (not '00)
CS
(SlowROM
address decoded) I | I | , ' | 1 STEP | -1,I | Y

needed only
for single

INSTR mode I poSINGLE lNSTRUCTlON I

SINGLE CYCLE
SLOW ROM | (NOTE: Features not needed may be omitted)

## SINGLE STEP FOR 6502

## ADDRESS DISPLAY

D0
Dl
D2
D3
100 ,.. | SYNC SYNC | D5 | Q5

The Apple Computer Company hereby warrants each of its products, and all components therein contained, to be free from defects in materials and/or workmanship for a period of thirty (30) days from date of purchase. In the event of the occurrence of malfunction, or other indication of failure attributable directly to faulty workmanship and/or mate rial, then, upon return of the product to the Apple Computer Company, at 770 Welch Road, Palo Alto, California, 94304 (postage prepaid), the Apple Computer Company will, at its option, repair or replace said products or components the reof, to what sve r extent Apple Computer Company shall deem necessary, to restore said product to proper operating condition. All such repairs or replacements shall be rendered by the Apple Computer Company, without charge to the customer.

The responsibility for the failure of any Apple Computer product, or component thereof, which, at the discretion of the Apple Computer Company, shall have resulted either directly or indirectly from accident, abuse, or misapplication of the product, shall be assumed by the customer, andthe Apple Computer Company shall assume no liability as a consequence of such events under the terms of this warranty.

While every effort, on the part of Apple Computer Company, is made to provide clear and accurate technical instruction on the use, implementation, and application of its products, the Apple Computer Company shall assume no liability in events which may arise from the application of such technical instruction, nor shall the Apple Computer Company be held liable for the quality, interconnection, or application of periferal products, which may have been recommended by Apple Computer Company, but which havenotbeensuppliedaspart oftheproduct.

This warranty contains and embodies the limits of responsibility of the Apple Computer Company, with regard to its products, and no other liability is expressed, implied, or should be assumed by the purchaser, and in no event shall the Apple Computer Company be held liable for the loss of time, effort, or transportation costs, nor for loss of potential profits or other consequentiallosses whichmight arise from the purchase, assembly, use, application, or subsequent sale of the products of Apple Computer Company, nor from any instructions and/or technical information thereto related.

4

f

d

k

C

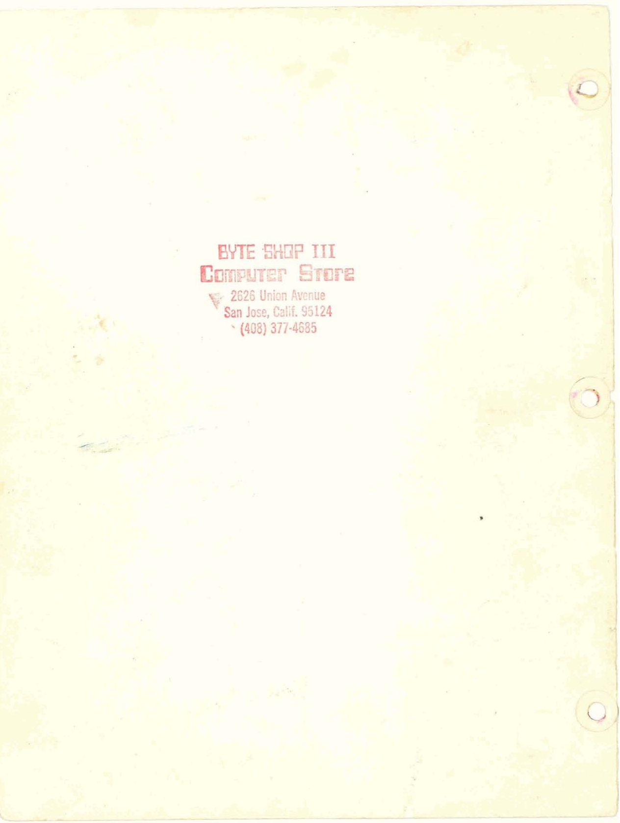
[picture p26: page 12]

# em 'anp 1\11

# v $621 Union A%en+Qe $gsj Mf;351124

@@4i137746g$

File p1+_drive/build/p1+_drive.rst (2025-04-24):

ASxxxx Assembler V02.00 + NoICE + SDCC mods  (STMicroelectronics STM8), page 1.
Hexadecimal [24-Bits]

                                      1 ;;
                                      2 ; Copyright Jacques Deschênes 2025  
                                      3 ; This file is part of p1+_drive 
                                      4 ;
                                      5 ;     p1+_drive is free software: you can redistribute it and/or modify
                                      6 ;     it under the terms of the GNU General Public License as published by
                                      7 ;     the Free Software Foundation, either version 3 of the License, or
                                      8 ;     (at your option) any later version.
                                      9 ;
                                     10 ;     p1+_drive is distributed in the hope that it will be useful,
                                     11 ;     but WITHOUT ANY WARRANTY; without even the implied warranty of
                                     12 ;     MERCHANTABILITY or FITNESS FOR A PARTICULAR PURPOSE.  See the
                                     13 ;     GNU General Public License for more details.
                                     14 ;
                                     15 ;     You should have received a copy of the GNU General Public License
                                     16 ;     along with p1+_drive.  If not, see <http://www.gnu.org/licenses/>.
                                     17 ;;
                                     18 
                                     19 ;;;;;;;;;;;;;;;;;;;;;;;;;;;;;;;
                                     20 ;;; hardware initialization
                                     21 ;;;;;;;;;;;;;;;;;;;;;;;;;;;;;; 
                                     22 
                                     23     .module HW_INIT 
                                     24 

ASxxxx Assembler V02.00 + NoICE + SDCC mods  (STMicroelectronics STM8), page 2.
Hexadecimal [24-Bits]

                                     25     .include "config.inc"
                                      1 ;;;;;;;;;;;;;;;;;;;;;;;;;;;;;;
                                      2 ;;  configuration parameters 
                                      3 ;;;;;;;;;;;;;;;;;;;;;;;;;;;;;;
                                      4 
                                      5 ;     MCU STM88S207K8T 
                                      6 
                                      7 ; version 
                           000001     8     MAJOR=1 
                           000000     9     MINOR=0 
                           000000    10     REV=0
                                     11     
                           000010    12 FMSTR=16 ; MHZ
                                     13 
                                     14 ; flags 
                           000000    15 FTX=0 ; set to 1 when transmitting data to computer, otherwise reset  
                           000001    16 FCOMP_RDY=1 ; set this bit when computer is ready to receive, otherwise reset 
                           000005    17 FITF=5 ; which interface to use, 0 parallel, 1 serial 
                                     18 
                                     19 

ASxxxx Assembler V02.00 + NoICE + SDCC mods  (STMicroelectronics STM8), page 3.
Hexadecimal [24-Bits]

                                     20     .include "inc/stm8s207.inc" 
                                      1 ;;
                                      2 ; Copyright Jacques Deschênes 2019,2022 
                                      3 ; This file is part of MONA 
                                      4 ;
                                      5 ;     MONA is free software: you can redistribute it and/or modify
                                      6 ;     it under the terms of the GNU General Public License as published by
                                      7 ;     the Free Software Foundation, either version 3 of the License, or
                                      8 ;     (at your option) any later version.
                                      9 ;
                                     10 ;     MONA is distributed in the hope that it will be useful,
                                     11 ;     but WITHOUT ANY WARRANTY; without even the implied warranty of
                                     12 ;     MERCHANTABILITY or FITNESS FOR A PARTICULAR PURPOSE.  See the
                                     13 ;     GNU General Public License for more details.
                                     14 ;
                                     15 ;     You should have received a copy of the GNU General Public License
                                     16 ;     along with MONA.  If not, see <http://www.gnu.org/licenses/>.
                                     17 ;;
                                     18 ;;;;;;;;;;;;;;;;;;;;;;;;;;;;;;;;;;;
                                     19 ; 2022/11/14
                                     20 ; STM8S207K8 µC registers map
                                     21 ; sdas source file
                                     22 ; author: Jacques Deschênes, copyright 2018,2019,2022
                                     23 ; licence: GPLv3
                                     24 ;;;;;;;;;;;;;;;;;;;;;;;;;;;;;;;;;;;;
                                     25 
                                     26 ;;;;;;;;;;;
                                     27 ; bits
                                     28 ;;;;;;;;;;;;
                           000000    29  BIT0 = 0
                           000001    30  BIT1 = 1
                           000002    31  BIT2 = 2
                           000003    32  BIT3 = 3
                           000004    33  BIT4 = 4
                           000005    34  BIT5 = 5
                           000006    35  BIT6 = 6
                           000007    36  BIT7 = 7
                                     37  	
                                     38 ;;;;;;;;;;;;
                                     39 ; bits masks
                                     40 ;;;;;;;;;;;;
                           000001    41  B0_MASK = (1<<0)
                           000002    42  B1_MASK = (1<<1)
                           000004    43  B2_MASK = (1<<2)
                           000008    44  B3_MASK = (1<<3)
                           000010    45  B4_MASK = (1<<4)
                           000020    46  B5_MASK = (1<<5)
                           000040    47  B6_MASK = (1<<6)
                           000080    48  B7_MASK = (1<<7)
                                     49 
                                     50 ; HSI oscillator frequency 16Mhz
                           F42400    51  FHSI = 16000000
                                     52 ; LSI oscillator frequency 128Khz
                           01F400    53  FLSI = 128000 
                                     54 

ASxxxx Assembler V02.00 + NoICE + SDCC mods  (STMicroelectronics STM8), page 4.
Hexadecimal [24-Bits]

                                     55 ; controller memory regions
                           001800    56  RAM_SIZE = (0x1800) ; 6KB 
                           000400    57  EEPROM_SIZE = (0x400) ; 1KB
                                     58 ; STM8S207K8 have 64K flash
                           010000    59  FLASH_SIZE = (0x10000)
                                     60 ; erase block size 
                           000080    61 BLOCK_SIZE=128 ; bytes 
                                     62 
                           000000    63  RAM_BASE = (0)
                           0017FF    64  RAM_END = (RAM_BASE+RAM_SIZE-1)
                           004000    65  EEPROM_BASE = (0x4000)
                           0043FF    66  EEPROM_END = (EEPROM_BASE+EEPROM_SIZE-1)
                           005000    67  SFR_BASE = (0x5000)
                           0057FF    68  SFR_END = (0x57FF)
                           006000    69  BOOT_ROM_BASE = (0x6000)
                           007FFF    70  BOOT_ROM_END = (0x7fff)
                           008000    71  FLASH_BASE = (0x8000)
                           017FFF    72  FLASH_END = (FLASH_BASE+FLASH_SIZE-1)
                           004800    73  OPTION_BASE = (0x4800)
                           000080    74  OPTION_SIZE = (0x80)
                           00487F    75  OPTION_END = (OPTION_BASE+OPTION_SIZE-1)
                           0048CD    76  DEVID_BASE = (0x48CD)
                           0048D8    77  DEVID_END = (0x48D8)
                           007F00    78  DEBUG_BASE = (0X7F00)
                           007FFF    79  DEBUG_END = (0X7FFF)
                                     80 
                                     81 ; options bytes
                                     82 ; this one can be programmed only from SWIM  (ICP)
                           004800    83  OPT0  = (0x4800)
                                     84 ; these can be programmed at runtime (IAP)
                           004801    85  OPT1  = (0x4801)
                           004802    86  NOPT1  = (0x4802)
                           004803    87  OPT2  = (0x4803)
                           004804    88  NOPT2  = (0x4804)
                           004805    89  OPT3  = (0x4805)
                           004806    90  NOPT3  = (0x4806)
                           004807    91  OPT4  = (0x4807)
                           004808    92  NOPT4  = (0x4808)
                           004809    93  OPT5  = (0x4809)
                           00480A    94  NOPT5  = (0x480A)
                           00480B    95  OPT6  = (0x480B)
                           00480C    96  NOPT6 = (0x480C)
                           00480D    97  OPT7 = (0x480D)
                           00480E    98  NOPT7 = (0x480E)
                           00487E    99  OPTBL  = (0x487E)
                           00487F   100  NOPTBL  = (0x487F)
                                    101 ; option registers usage
                                    102 ; read out protection, value 0xAA enable ROP
                           004800   103  ROP = OPT0  
                                    104 ; user boot code, {0..0x3e} 512 bytes row
                           004801   105  UBC = OPT1
                           004802   106  NUBC = NOPT1
                                    107 ; alternate function register
                           004803   108  AFR = OPT2
                           004804   109  NAFR = NOPT2

ASxxxx Assembler V02.00 + NoICE + SDCC mods  (STMicroelectronics STM8), page 5.
Hexadecimal [24-Bits]

                                    110 ; miscelinous options
                           004805   111  WDGOPT = OPT3
                           004806   112  NWDGOPT = NOPT3
                                    113 ; clock options
                           004807   114  CLKOPT = OPT4
                           004808   115  NCLKOPT = NOPT4
                                    116 ; HSE clock startup delay
                           004809   117  HSECNT = OPT5
                           00480A   118  NHSECNT = NOPT5
                                    119 ; flash wait state
                           00480D   120 FLASH_WS = OPT7
                           00480E   121 NFLASH_WS = NOPT7
                                    122 
                                    123 ; watchdog options bits
                           000003   124   WDGOPT_LSIEN   =  BIT3
                           000002   125   WDGOPT_IWDG_HW =  BIT2
                           000001   126   WDGOPT_WWDG_HW =  BIT1
                           000000   127   WDGOPT_WWDG_HALT = BIT0
                                    128 ; NWDGOPT bits
                           FFFFFFFC   129   NWDGOPT_LSIEN    = ~BIT3
                           FFFFFFFD   130   NWDGOPT_IWDG_HW  = ~BIT2
                           FFFFFFFE   131   NWDGOPT_WWDG_HW  = ~BIT1
                           FFFFFFFF   132   NWDGOPT_WWDG_HALT = ~BIT0
                                    133 
                                    134 ; CLKOPT bits
                           000003   135  CLKOPT_EXT_CLK  = BIT3
                           000002   136  CLKOPT_CKAWUSEL = BIT2
                           000001   137  CLKOPT_PRS_C1   = BIT1
                           000000   138  CLKOPT_PRS_C0   = BIT0
                                    139 
                                    140 ; AFR option, remapable functions
                           000007   141  AFR7_BEEP    = BIT7
                           000006   142  AFR6_I2C     = BIT6
                           000005   143  AFR5_TIM1    = BIT5
                           000004   144  AFR4_TIM1    = BIT4
                           000003   145  AFR3_TIM1    = BIT3
                           000002   146  AFR2_CCO     = BIT2
                           000001   147  AFR1_TIM2    = BIT1
                           000000   148  AFR0_ADC     = BIT0
                                    149 
                                    150 ; device ID = (read only)
                           0048CD   151  DEVID_XL  = (0x48CD)
                           0048CE   152  DEVID_XH  = (0x48CE)
                           0048CF   153  DEVID_YL  = (0x48CF)
                           0048D0   154  DEVID_YH  = (0x48D0)
                           0048D1   155  DEVID_WAF  = (0x48D1)
                           0048D2   156  DEVID_LOT0  = (0x48D2)
                           0048D3   157  DEVID_LOT1  = (0x48D3)
                           0048D4   158  DEVID_LOT2  = (0x48D4)
                           0048D5   159  DEVID_LOT3  = (0x48D5)
                           0048D6   160  DEVID_LOT4  = (0x48D6)
                           0048D7   161  DEVID_LOT5  = (0x48D7)
                           0048D8   162  DEVID_LOT6  = (0x48D8)
                                    163 
                                    164 

ASxxxx Assembler V02.00 + NoICE + SDCC mods  (STMicroelectronics STM8), page 6.
Hexadecimal [24-Bits]

                           005000   165 GPIO_BASE = (0x5000)
                           000005   166 GPIO_SIZE = (5)
                                    167 ; PORTS SFR OFFSET
                           000000   168 PA = 0
                           000005   169 PB = 5
                           00000A   170 PC = 10
                           00000F   171 PD = 15
                           000014   172 PE = 20
                           000019   173 PF = 25
                           00001E   174 PG = 30
                           000023   175 PH = 35 
                           000028   176 PI = 40 
                                    177 
                                    178 ; GPIO
                                    179 ; gpio register offset to base
                           000000   180  GPIO_ODR = 0
                           000001   181  GPIO_IDR = 1
                           000002   182  GPIO_DDR = 2
                           000003   183  GPIO_CR1 = 3
                           000004   184  GPIO_CR2 = 4
                           005000   185  GPIO_BASE=(0X5000)
                                    186  
                                    187 ; port A
                           005000   188  PA_BASE = (0X5000)
                           005000   189  PA_ODR  = (0x5000)
                           005001   190  PA_IDR  = (0x5001)
                           005002   191  PA_DDR  = (0x5002)
                           005003   192  PA_CR1  = (0x5003)
                           005004   193  PA_CR2  = (0x5004)
                                    194 ; port B
                           005005   195  PB_BASE = (0X5005)
                           005005   196  PB_ODR  = (0x5005)
                           005006   197  PB_IDR  = (0x5006)
                           005007   198  PB_DDR  = (0x5007)
                           005008   199  PB_CR1  = (0x5008)
                           005009   200  PB_CR2  = (0x5009)
                                    201 ; port C
                           00500A   202  PC_BASE = (0X500A)
                           00500A   203  PC_ODR  = (0x500A)
                           00500B   204  PC_IDR  = (0x500B)
                           00500C   205  PC_DDR  = (0x500C)
                           00500D   206  PC_CR1  = (0x500D)
                           00500E   207  PC_CR2  = (0x500E)
                                    208 ; port D
                           00500F   209  PD_BASE = (0X500F)
                           00500F   210  PD_ODR  = (0x500F)
                           005010   211  PD_IDR  = (0x5010)
                           005011   212  PD_DDR  = (0x5011)
                           005012   213  PD_CR1  = (0x5012)
                           005013   214  PD_CR2  = (0x5013)
                                    215 ; port E
                           005014   216  PE_BASE = (0X5014)
                           005014   217  PE_ODR  = (0x5014)
                           005015   218  PE_IDR  = (0x5015)
                           005016   219  PE_DDR  = (0x5016)

ASxxxx Assembler V02.00 + NoICE + SDCC mods  (STMicroelectronics STM8), page 7.
Hexadecimal [24-Bits]

                           005017   220  PE_CR1  = (0x5017)
                           005018   221  PE_CR2  = (0x5018)
                                    222 ; port F
                           005019   223  PF_BASE = (0X5019)
                           005019   224  PF_ODR  = (0x5019)
                           00501A   225  PF_IDR  = (0x501A)
                           00501B   226  PF_DDR  = (0x501B)
                           00501C   227  PF_CR1  = (0x501C)
                           00501D   228  PF_CR2  = (0x501D)
                                    229 ; port G
                           00501E   230  PG_BASE = (0X501E)
                           00501E   231  PG_ODR  = (0x501E)
                           00501F   232  PG_IDR  = (0x501F)
                           005020   233  PG_DDR  = (0x5020)
                           005021   234  PG_CR1  = (0x5021)
                           005022   235  PG_CR2  = (0x5022)
                                    236 ; port H not present on LQFP48/LQFP64 package
                           005023   237  PH_BASE = (0X5023)
                           005023   238  PH_ODR  = (0x5023)
                           005024   239  PH_IDR  = (0x5024)
                           005025   240  PH_DDR  = (0x5025)
                           005026   241  PH_CR1  = (0x5026)
                           005027   242  PH_CR2  = (0x5027)
                                    243 ; port I ; only bit 0 on LQFP64 package, not present on LQFP48
                           005028   244  PI_BASE = (0X5028)
                           005028   245  PI_ODR  = (0x5028)
                           005029   246  PI_IDR  = (0x5029)
                           00502A   247  PI_DDR  = (0x502a)
                           00502B   248  PI_CR1  = (0x502b)
                           00502C   249  PI_CR2  = (0x502c)
                                    250 
                                    251 ; input modes CR1
                           000000   252  INPUT_FLOAT = (0) ; no pullup resistor
                           000001   253  INPUT_PULLUP = (1)
                                    254 ; output mode CR1
                           000000   255  OUTPUT_OD = (0) ; open drain
                           000001   256  OUTPUT_PP = (1) ; push pull
                                    257 ; input modes CR2
                           000000   258  INPUT_DI = (0)
                           000001   259  INPUT_EI = (1)
                                    260 ; output speed CR2
                           000000   261  OUTPUT_SLOW = (0)
                           000001   262  OUTPUT_FAST = (1)
                                    263 
                                    264 
                                    265 ; Flash memory
                           000080   266  BLOCK_SIZE=128 
                           00505A   267  FLASH_CR1  = (0x505A)
                           00505B   268  FLASH_CR2  = (0x505B)
                           00505C   269  FLASH_NCR2  = (0x505C)
                           00505D   270  FLASH_FPR  = (0x505D)
                           00505E   271  FLASH_NFPR  = (0x505E)
                           00505F   272  FLASH_IAPSR  = (0x505F)
                           005062   273  FLASH_PUKR  = (0x5062)
                           005064   274  FLASH_DUKR  = (0x5064)

ASxxxx Assembler V02.00 + NoICE + SDCC mods  (STMicroelectronics STM8), page 8.
Hexadecimal [24-Bits]

                                    275 ; data memory unlock keys
                           0000AE   276  FLASH_DUKR_KEY1 = (0xae)
                           000056   277  FLASH_DUKR_KEY2 = (0x56)
                                    278 ; flash memory unlock keys
                           000056   279  FLASH_PUKR_KEY1 = (0x56)
                           0000AE   280  FLASH_PUKR_KEY2 = (0xae)
                                    281 ; FLASH_CR1 bits
                           000003   282  FLASH_CR1_HALT = BIT3
                           000002   283  FLASH_CR1_AHALT = BIT2
                           000001   284  FLASH_CR1_IE = BIT1
                           000000   285  FLASH_CR1_FIX = BIT0
                                    286 ; FLASH_CR2 bits
                           000007   287  FLASH_CR2_OPT = BIT7
                           000006   288  FLASH_CR2_WPRG = BIT6
                           000005   289  FLASH_CR2_ERASE = BIT5
                           000004   290  FLASH_CR2_FPRG = BIT4
                           000000   291  FLASH_CR2_PRG = BIT0
                                    292 ; FLASH_FPR bits
                           000005   293  FLASH_FPR_WPB5 = BIT5
                           000004   294  FLASH_FPR_WPB4 = BIT4
                           000003   295  FLASH_FPR_WPB3 = BIT3
                           000002   296  FLASH_FPR_WPB2 = BIT2
                           000001   297  FLASH_FPR_WPB1 = BIT1
                           000000   298  FLASH_FPR_WPB0 = BIT0
                                    299 ; FLASH_NFPR bits
                           000005   300  FLASH_NFPR_NWPB5 = BIT5
                           000004   301  FLASH_NFPR_NWPB4 = BIT4
                           000003   302  FLASH_NFPR_NWPB3 = BIT3
                           000002   303  FLASH_NFPR_NWPB2 = BIT2
                           000001   304  FLASH_NFPR_NWPB1 = BIT1
                           000000   305  FLASH_NFPR_NWPB0 = BIT0
                                    306 ; FLASH_IAPSR bits
                           000006   307  FLASH_IAPSR_HVOFF = BIT6
                           000003   308  FLASH_IAPSR_DUL = BIT3
                           000002   309  FLASH_IAPSR_EOP = BIT2
                           000001   310  FLASH_IAPSR_PUL = BIT1
                           000000   311  FLASH_IAPSR_WR_PG_DIS = BIT0
                                    312 
                                    313 ; Interrupt control
                           0050A0   314  EXTI_CR1  = (0x50A0)
                           0050A1   315  EXTI_CR2  = (0x50A1)
                                    316 
                                    317 ; Reset Status
                           0050B3   318  RST_SR  = (0x50B3)
                                    319 
                                    320 ; Clock Registers
                           0050C0   321  CLK_ICKR  = (0x50c0)
                           0050C1   322  CLK_ECKR  = (0x50c1)
                           0050C3   323  CLK_CMSR  = (0x50C3)
                           0050C4   324  CLK_SWR  = (0x50C4)
                           0050C5   325  CLK_SWCR  = (0x50C5)
                           0050C6   326  CLK_CKDIVR  = (0x50C6)
                           0050C7   327  CLK_PCKENR1  = (0x50C7)
                           0050C8   328  CLK_CSSR  = (0x50C8)
                           0050C9   329  CLK_CCOR  = (0x50C9)

ASxxxx Assembler V02.00 + NoICE + SDCC mods  (STMicroelectronics STM8), page 9.
Hexadecimal [24-Bits]

                           0050CA   330  CLK_PCKENR2  = (0x50CA)
                           0050CC   331  CLK_HSITRIMR  = (0x50CC)
                           0050CD   332  CLK_SWIMCCR  = (0x50CD)
                                    333 
                                    334 ; Peripherals clock gating
                                    335 ; CLK_PCKENR1 
                           000007   336  CLK_PCKENR1_TIM1 = (7)
                           000006   337  CLK_PCKENR1_TIM3 = (6)
                           000005   338  CLK_PCKENR1_TIM2 = (5)
                           000004   339  CLK_PCKENR1_TIM4 = (4)
                           000003   340  CLK_PCKENR1_UART3 = (3)
                           000002   341  CLK_PCKENR1_UART1 = (2)
                           000001   342  CLK_PCKENR1_SPI = (1)
                           000000   343  CLK_PCKENR1_I2C = (0)
                                    344 ; CLK_PCKENR2
                           000007   345  CLK_PCKENR2_CAN = (7)
                           000003   346  CLK_PCKENR2_ADC = (3)
                           000002   347  CLK_PCKENR2_AWU = (2)
                                    348 
                                    349 ; Clock bits
                           000005   350  CLK_ICKR_REGAH = (5)
                           000004   351  CLK_ICKR_LSIRDY = (4)
                           000003   352  CLK_ICKR_LSIEN = (3)
                           000002   353  CLK_ICKR_FHW = (2)
                           000001   354  CLK_ICKR_HSIRDY = (1)
                           000000   355  CLK_ICKR_HSIEN = (0)
                                    356 
                           000001   357  CLK_ECKR_HSERDY = (1)
                           000000   358  CLK_ECKR_HSEEN = (0)
                                    359 ; clock source
                           0000E1   360  CLK_SWR_HSI = 0xE1
                           0000D2   361  CLK_SWR_LSI = 0xD2
                           0000B4   362  CLK_SWR_HSE = 0xB4
                                    363 
                           000003   364  CLK_SWCR_SWIF = (3)
                           000002   365  CLK_SWCR_SWIEN = (2)
                           000001   366  CLK_SWCR_SWEN = (1)
                           000000   367  CLK_SWCR_SWBSY = (0)
                                    368 
                           000004   369  CLK_CKDIVR_HSIDIV1 = (4)
                           000003   370  CLK_CKDIVR_HSIDIV0 = (3)
                           000002   371  CLK_CKDIVR_CPUDIV2 = (2)
                           000001   372  CLK_CKDIVR_CPUDIV1 = (1)
                           000000   373  CLK_CKDIVR_CPUDIV0 = (0)
                                    374 
                                    375 ; Watchdog
                           0050D1   376  WWDG_CR  = (0x50D1)
                           0050D2   377  WWDG_WR  = (0x50D2)
                           0050E0   378  IWDG_KR  = (0x50E0)
                           0050E1   379  IWDG_PR  = (0x50E1)
                           0050E2   380  IWDG_RLR  = (0x50E2)
                           0000CC   381  IWDG_KEY_ENABLE = 0xCC  ; enable IWDG key 
                           0000AA   382  IWDG_KEY_REFRESH = 0xAA ; refresh counter key 
                           000055   383  IWDG_KEY_ACCESS = 0x55 ; write register key 
                                    384  

ASxxxx Assembler V02.00 + NoICE + SDCC mods  (STMicroelectronics STM8), page 10.
Hexadecimal [24-Bits]

                           0050F0   385  AWU_CSR  = (0x50F0)
                           0050F1   386  AWU_APR  = (0x50F1)
                           0050F2   387  AWU_TBR  = (0x50F2)
                           000004   388  AWU_CSR_AWUEN = 4
                                    389 
                                    390 
                                    391 
                                    392 ; Beeper
                                    393 ; beeper output is alternate function AFR7 on PD4
                                    394 ; connected to CN9-6
                           0050F3   395  BEEP_CSR  = (0x50F3)
                           00000F   396  BEEP_PORT = PD
                           000004   397  BEEP_BIT = 4
                           000010   398  BEEP_MASK = B4_MASK
                                    399 
                                    400 ; SPI
                           005200   401  SPI_CR1  = (0x5200)
                           005201   402  SPI_CR2  = (0x5201)
                           005202   403  SPI_ICR  = (0x5202)
                           005203   404  SPI_SR  = (0x5203)
                           005204   405  SPI_DR  = (0x5204)
                           005205   406  SPI_CRCPR  = (0x5205)
                           005206   407  SPI_RXCRCR  = (0x5206)
                           005207   408  SPI_TXCRCR  = (0x5207)
                                    409 
                                    410 ; SPI_CR1 bit fields 
                           000000   411   SPI_CR1_CPHA=0
                           000001   412   SPI_CR1_CPOL=1
                           000002   413   SPI_CR1_MSTR=2
                           000003   414   SPI_CR1_BR=3
                           000006   415   SPI_CR1_SPE=6
                           000007   416   SPI_CR1_LSBFIRST=7
                                    417   
                                    418 ; SPI_CR2 bit fields 
                           000000   419   SPI_CR2_SSI=0
                           000001   420   SPI_CR2_SSM=1
                           000002   421   SPI_CR2_RXONLY=2
                           000004   422   SPI_CR2_CRCNEXT=4
                           000005   423   SPI_CR2_CRCEN=5
                           000006   424   SPI_CR2_BDOE=6
                           000007   425   SPI_CR2_BDM=7  
                                    426 
                                    427 ; SPI_SR bit fields 
                           000000   428   SPI_SR_RXNE=0
                           000001   429   SPI_SR_TXE=1
                           000003   430   SPI_SR_WKUP=3
                           000004   431   SPI_SR_CRCERR=4
                           000005   432   SPI_SR_MODF=5
                           000006   433   SPI_SR_OVR=6
                           000007   434   SPI_SR_BSY=7
                                    435 
                                    436 ; I2C
                           005210   437  I2C_BASE_ADDR = 0x5210 
                           005210   438  I2C_CR1  = (0x5210)
                           005211   439  I2C_CR2  = (0x5211)

ASxxxx Assembler V02.00 + NoICE + SDCC mods  (STMicroelectronics STM8), page 11.
Hexadecimal [24-Bits]

                           005212   440  I2C_FREQR  = (0x5212)
                           005213   441  I2C_OARL  = (0x5213)
                           005214   442  I2C_OARH  = (0x5214)
                           005216   443  I2C_DR  = (0x5216)
                           005217   444  I2C_SR1  = (0x5217)
                           005218   445  I2C_SR2  = (0x5218)
                           005219   446  I2C_SR3  = (0x5219)
                           00521A   447  I2C_ITR  = (0x521A)
                           00521B   448  I2C_CCRL  = (0x521B)
                           00521C   449  I2C_CCRH  = (0x521C)
                           00521D   450  I2C_TRISER  = (0x521D)
                           00521E   451  I2C_PECR  = (0x521E)
                                    452 
                           000007   453  I2C_CR1_NOSTRETCH = (7)
                           000006   454  I2C_CR1_ENGC = (6)
                           000000   455  I2C_CR1_PE = (0)
                                    456 
                           000007   457  I2C_CR2_SWRST = (7)
                           000003   458  I2C_CR2_POS = (3)
                           000002   459  I2C_CR2_ACK = (2)
                           000001   460  I2C_CR2_STOP = (1)
                           000000   461  I2C_CR2_START = (0)
                                    462 
                           000000   463  I2C_OARL_ADD0 = (0)
                                    464 
                           000009   465  I2C_OAR_ADDR_7BIT = ((I2C_OARL & 0xFE) >> 1)
                           000813   466  I2C_OAR_ADDR_10BIT = (((I2C_OARH & 0x06) << 9) | (I2C_OARL & 0xFF))
                                    467 
                           000007   468  I2C_OARH_ADDMODE = (7)
                           000006   469  I2C_OARH_ADDCONF = (6)
                           000002   470  I2C_OARH_ADD9 = (2)
                           000001   471  I2C_OARH_ADD8 = (1)
                                    472 
                           000007   473  I2C_SR1_TXE = (7)
                           000006   474  I2C_SR1_RXNE = (6)
                           000004   475  I2C_SR1_STOPF = (4)
                           000003   476  I2C_SR1_ADD10 = (3)
                           000002   477  I2C_SR1_BTF = (2)
                           000001   478  I2C_SR1_ADDR = (1)
                           000000   479  I2C_SR1_SB = (0)
                                    480 
                           000005   481  I2C_SR2_WUFH = (5)
                           000003   482  I2C_SR2_OVR = (3)
                           000002   483  I2C_SR2_AF = (2)
                           000001   484  I2C_SR2_ARLO = (1)
                           000000   485  I2C_SR2_BERR = (0)
                                    486 
                           000007   487  I2C_SR3_DUALF = (7)
                           000004   488  I2C_SR3_GENCALL = (4)
                           000002   489  I2C_SR3_TRA = (2)
                           000001   490  I2C_SR3_BUSY = (1)
                           000000   491  I2C_SR3_MSL = (0)
                                    492 
                           000002   493  I2C_ITR_ITBUFEN = (2)
                           000001   494  I2C_ITR_ITEVTEN = (1)

ASxxxx Assembler V02.00 + NoICE + SDCC mods  (STMicroelectronics STM8), page 12.
Hexadecimal [24-Bits]

                           000000   495  I2C_ITR_ITERREN = (0)
                                    496 
                           000007   497  I2C_CCRH_FAST = 7 
                           000006   498  I2C_CCRH_DUTY = 6 
                                    499  
                                    500 ; Precalculated values, all in KHz
                           000080   501  I2C_CCRH_16MHZ_FAST_400 = 0x80
                           00000D   502  I2C_CCRL_16MHZ_FAST_400 = 0x0D
                                    503 ;
                                    504 ; Fast I2C mode max rise time = 300ns
                                    505 ; I2C_FREQR = 16 = (MHz) => tMASTER = 1/16 = 62.5 ns
                                    506 ; TRISER = = (300/62.5) + 1 = floor(4.8) + 1 = 5.
                                    507 
                           000005   508  I2C_TRISER_16MHZ_FAST_400 = 0x05
                                    509 
                           0000C0   510  I2C_CCRH_16MHZ_FAST_320 = 0xC0
                           000002   511  I2C_CCRL_16MHZ_FAST_320 = 0x02
                           000005   512  I2C_TRISER_16MHZ_FAST_320 = 0x05
                                    513 
                           000080   514  I2C_CCRH_16MHZ_FAST_200 = 0x80
                           00001A   515  I2C_CCRL_16MHZ_FAST_200 = 0x1A
                           000005   516  I2C_TRISER_16MHZ_FAST_200 = 0x05
                                    517 
                           000000   518  I2C_CCRH_16MHZ_STD_100 = 0x00
                           000050   519  I2C_CCRL_16MHZ_STD_100 = 0x50
                                    520 ;
                                    521 ; Standard I2C mode max rise time = 1000ns
                                    522 ; I2C_FREQR = 16 = (MHz) => tMASTER = 1/16 = 62.5 ns
                                    523 ; TRISER = = (1000/62.5) + 1 = floor(16) + 1 = 17.
                                    524 
                           000011   525  I2C_TRISER_16MHZ_STD_100 = 0x11
                                    526 
                           000000   527  I2C_CCRH_16MHZ_STD_50 = 0x00
                           0000A0   528  I2C_CCRL_16MHZ_STD_50 = 0xA0
                           000011   529  I2C_TRISER_16MHZ_STD_50 = 0x11
                                    530 
                           000001   531  I2C_CCRH_16MHZ_STD_20 = 0x01
                           000090   532  I2C_CCRL_16MHZ_STD_20 = 0x90
                           000011   533  I2C_TRISER_16MHZ_STD_20 = 0x11;
                                    534 
                           000001   535  I2C_READ = 1
                           000000   536  I2C_WRITE = 0
                                    537 
                                    538 ; baudrate constant for brr_value table access
                                    539 ; to be used by uart_init 
                           000000   540 B2400=0
                           000001   541 B4800=1
                           000002   542 B9600=2
                           000003   543 B19200=3
                           000004   544 B38400=4
                           000005   545 B57600=5
                           000006   546 B115200=6
                           000007   547 B230400=7
                           000008   548 B460800=8
                                    549 

ASxxxx Assembler V02.00 + NoICE + SDCC mods  (STMicroelectronics STM8), page 13.
Hexadecimal [24-Bits]

                                    550 
                                    551 ; UART registers offset from
                                    552 ; base address 
                           000000   553 OFS_UART_SR=0
                           000001   554 OFS_UART_DR=1
                           000002   555 OFS_UART_BRR1=2
                           000003   556 OFS_UART_BRR2=3
                           000004   557 OFS_UART_CR1=4
                           000005   558 OFS_UART_CR2=5
                           000006   559 OFS_UART_CR3=6
                           000007   560 OFS_UART_CR4=7
                           000008   561 OFS_UART_CR5=8
                           000009   562 OFS_UART_CR6=9
                           000009   563 OFS_UART_GTR=9
                           00000A   564 OFS_UART_PSCR=10
                                    565 
                                    566 ; uart identifier
                           000000   567  UART1 = 0 
                           000001   568  UART2 = 1
                           000002   569  UART3 = 2
                                    570 
                                    571 ; pins used by uart 
                           000005   572 UART1_TX_PIN=BIT5
                           000004   573 UART1_RX_PIN=BIT4
                           000005   574 UART3_TX_PIN=BIT5
                           000006   575 UART3_RX_PIN=BIT6
                                    576 ; uart port base address 
                           000000   577 UART1_PORT=PA 
                           00000F   578 UART3_PORT=PD
                                    579 
                                    580 ; UART1 
                           005230   581  UART1_BASE  = (0x5230)
                           005230   582  UART1_SR    = (0x5230)
                           005231   583  UART1_DR    = (0x5231)
                           005232   584  UART1_BRR1  = (0x5232)
                           005233   585  UART1_BRR2  = (0x5233)
                           005234   586  UART1_CR1   = (0x5234)
                           005235   587  UART1_CR2   = (0x5235)
                           005236   588  UART1_CR3   = (0x5236)
                           005237   589  UART1_CR4   = (0x5237)
                           005238   590  UART1_CR5   = (0x5238)
                           005239   591  UART1_GTR   = (0x5239)
                           00523A   592  UART1_PSCR  = (0x523A)
                                    593 
                                    594 ; UART3
                           005240   595  UART3_BASE  = (0x5240)
                           005240   596  UART3_SR    = (0x5240)
                           005241   597  UART3_DR    = (0x5241)
                           005242   598  UART3_BRR1  = (0x5242)
                           005243   599  UART3_BRR2  = (0x5243)
                           005244   600  UART3_CR1   = (0x5244)
                           005245   601  UART3_CR2   = (0x5245)
                           005246   602  UART3_CR3   = (0x5246)
                           005247   603  UART3_CR4   = (0x5247)
                           005249   604  UART3_CR6   = (0x5249)

ASxxxx Assembler V02.00 + NoICE + SDCC mods  (STMicroelectronics STM8), page 14.
Hexadecimal [24-Bits]

                                    605 
                                    606 ; UART Status Register bits
                           000007   607  UART_SR_TXE = (7)
                           000006   608  UART_SR_TC = (6)
                           000005   609  UART_SR_RXNE = (5)
                           000004   610  UART_SR_IDLE = (4)
                           000003   611  UART_SR_OR = (3)
                           000002   612  UART_SR_NF = (2)
                           000001   613  UART_SR_FE = (1)
                           000000   614  UART_SR_PE = (0)
                                    615 
                                    616 ; Uart Control Register bits
                           000007   617  UART_CR1_R8 = (7)
                           000006   618  UART_CR1_T8 = (6)
                           000005   619  UART_CR1_UARTD = (5)
                           000004   620  UART_CR1_M = (4)
                           000003   621  UART_CR1_WAKE = (3)
                           000002   622  UART_CR1_PCEN = (2)
                           000001   623  UART_CR1_PS = (1)
                           000000   624  UART_CR1_PIEN = (0)
                                    625 
                           000007   626  UART_CR2_TIEN = (7)
                           000006   627  UART_CR2_TCIEN = (6)
                           000005   628  UART_CR2_RIEN = (5)
                           000004   629  UART_CR2_ILIEN = (4)
                           000003   630  UART_CR2_TEN = (3)
                           000002   631  UART_CR2_REN = (2)
                           000001   632  UART_CR2_RWU = (1)
                           000000   633  UART_CR2_SBK = (0)
                                    634 
                           000006   635  UART_CR3_LINEN = (6)
                           000005   636  UART_CR3_STOP1 = (5)
                           000004   637  UART_CR3_STOP0 = (4)
                           000003   638  UART_CR3_CLKEN = (3)
                           000002   639  UART_CR3_CPOL = (2)
                           000001   640  UART_CR3_CPHA = (1)
                           000000   641  UART_CR3_LBCL = (0)
                                    642 
                           000006   643  UART_CR4_LBDIEN = (6)
                           000005   644  UART_CR4_LBDL = (5)
                           000004   645  UART_CR4_LBDF = (4)
                           000003   646  UART_CR4_ADD3 = (3)
                           000002   647  UART_CR4_ADD2 = (2)
                           000001   648  UART_CR4_ADD1 = (1)
                           000000   649  UART_CR4_ADD0 = (0)
                                    650 
                           000005   651  UART_CR5_SCEN = (5)
                           000004   652  UART_CR5_NACK = (4)
                           000003   653  UART_CR5_HDSEL = (3)
                           000002   654  UART_CR5_IRLP = (2)
                           000001   655  UART_CR5_IREN = (1)
                                    656 ; LIN mode config register
                           000007   657  UART_CR6_LDUM = (7)
                           000005   658  UART_CR6_LSLV = (5)
                           000004   659  UART_CR6_LASE = (4)

ASxxxx Assembler V02.00 + NoICE + SDCC mods  (STMicroelectronics STM8), page 15.
Hexadecimal [24-Bits]

                           000002   660  UART_CR6_LHDIEN = (2) 
                           000001   661  UART_CR6_LHDF = (1)
                           000000   662  UART_CR6_LSF = (0)
                                    663 
                                    664 ; TIMERS
                                    665 ; Timer 1 - 16-bit timer with complementary PWM outputs
                           005250   666  TIM1_CR1  = (0x5250)
                           005251   667  TIM1_CR2  = (0x5251)
                           005252   668  TIM1_SMCR  = (0x5252)
                           005253   669  TIM1_ETR  = (0x5253)
                           005254   670  TIM1_IER  = (0x5254)
                           005255   671  TIM1_SR1  = (0x5255)
                           005256   672  TIM1_SR2  = (0x5256)
                           005257   673  TIM1_EGR  = (0x5257)
                           005258   674  TIM1_CCMR1  = (0x5258)
                           005259   675  TIM1_CCMR2  = (0x5259)
                           00525A   676  TIM1_CCMR3  = (0x525A)
                           00525B   677  TIM1_CCMR4  = (0x525B)
                           00525C   678  TIM1_CCER1  = (0x525C)
                           00525D   679  TIM1_CCER2  = (0x525D)
                           00525E   680  TIM1_CNTRH  = (0x525E)
                           00525F   681  TIM1_CNTRL  = (0x525F)
                           005260   682  TIM1_PSCRH  = (0x5260)
                           005261   683  TIM1_PSCRL  = (0x5261)
                           005262   684  TIM1_ARRH  = (0x5262)
                           005263   685  TIM1_ARRL  = (0x5263)
                           005264   686  TIM1_RCR  = (0x5264)
                           005265   687  TIM1_CCR1H  = (0x5265)
                           005266   688  TIM1_CCR1L  = (0x5266)
                           005267   689  TIM1_CCR2H  = (0x5267)
                           005268   690  TIM1_CCR2L  = (0x5268)
                           005269   691  TIM1_CCR3H  = (0x5269)
                           00526A   692  TIM1_CCR3L  = (0x526A)
                           00526B   693  TIM1_CCR4H  = (0x526B)
                           00526C   694  TIM1_CCR4L  = (0x526C)
                           00526D   695  TIM1_BKR  = (0x526D)
                           00526E   696  TIM1_DTR  = (0x526E)
                           00526F   697  TIM1_OISR  = (0x526F)
                                    698 
                                    699 ; Timer Control Register bits
                           000007   700  TIM1_CR1_ARPE = (7)
                           000006   701  TIM1_CR1_CMSH = (6)
                           000005   702  TIM1_CR1_CMSL = (5)
                           000004   703  TIM1_CR1_DIR = (4)
                           000003   704  TIM1_CR1_OPM = (3)
                           000002   705  TIM1_CR1_URS = (2)
                           000001   706  TIM1_CR1_UDIS = (1)
                           000000   707  TIM1_CR1_CEN = (0)
                                    708 
                           000006   709  TIM1_CR2_MMS2 = (6)
                           000005   710  TIM1_CR2_MMS1 = (5)
                           000004   711  TIM1_CR2_MMS0 = (4)
                           000002   712  TIM1_CR2_COMS = (2)
                           000000   713  TIM1_CR2_CCPC = (0)
                                    714 

ASxxxx Assembler V02.00 + NoICE + SDCC mods  (STMicroelectronics STM8), page 16.
Hexadecimal [24-Bits]

                                    715 ; Timer Slave Mode Control bits
                           000007   716  TIM1_SMCR_MSM = (7)
                           000006   717  TIM1_SMCR_TS2 = (6)
                           000005   718  TIM1_SMCR_TS1 = (5)
                           000004   719  TIM1_SMCR_TS0 = (4)
                           000002   720  TIM1_SMCR_SMS2 = (2)
                           000001   721  TIM1_SMCR_SMS1 = (1)
                           000000   722  TIM1_SMCR_SMS0 = (0)
                                    723 
                                    724 ; Timer External Trigger Enable bits
                           000007   725  TIM1_ETR_ETP = (7)
                           000006   726  TIM1_ETR_ECE = (6)
                           000005   727  TIM1_ETR_ETPS1 = (5)
                           000004   728  TIM1_ETR_ETPS0 = (4)
                           000003   729  TIM1_ETR_ETF3 = (3)
                           000002   730  TIM1_ETR_ETF2 = (2)
                           000001   731  TIM1_ETR_ETF1 = (1)
                           000000   732  TIM1_ETR_ETF0 = (0)
                                    733 
                                    734 ; Timer Interrupt Enable bits
                           000007   735  TIM1_IER_BIE = (7)
                           000006   736  TIM1_IER_TIE = (6)
                           000005   737  TIM1_IER_COMIE = (5)
                           000004   738  TIM1_IER_CC4IE = (4)
                           000003   739  TIM1_IER_CC3IE = (3)
                           000002   740  TIM1_IER_CC2IE = (2)
                           000001   741  TIM1_IER_CC1IE = (1)
                           000000   742  TIM1_IER_UIE = (0)
                                    743 
                                    744 ; Timer Status Register bits
                           000007   745  TIM1_SR1_BIF = (7)
                           000006   746  TIM1_SR1_TIF = (6)
                           000005   747  TIM1_SR1_COMIF = (5)
                           000004   748  TIM1_SR1_CC4IF = (4)
                           000003   749  TIM1_SR1_CC3IF = (3)
                           000002   750  TIM1_SR1_CC2IF = (2)
                           000001   751  TIM1_SR1_CC1IF = (1)
                           000000   752  TIM1_SR1_UIF = (0)
                                    753 
                           000004   754  TIM1_SR2_CC4OF = (4)
                           000003   755  TIM1_SR2_CC3OF = (3)
                           000002   756  TIM1_SR2_CC2OF = (2)
                           000001   757  TIM1_SR2_CC1OF = (1)
                                    758 
                                    759 ; Timer Event Generation Register bits
                           000007   760  TIM1_EGR_BG = (7)
                           000006   761  TIM1_EGR_TG = (6)
                           000005   762  TIM1_EGR_COMG = (5)
                           000004   763  TIM1_EGR_CC4G = (4)
                           000003   764  TIM1_EGR_CC3G = (3)
                           000002   765  TIM1_EGR_CC2G = (2)
                           000001   766  TIM1_EGR_CC1G = (1)
                           000000   767  TIM1_EGR_UG = (0)
                                    768 
                                    769 ; Capture/Compare Mode Register 1 - channel configured in output

ASxxxx Assembler V02.00 + NoICE + SDCC mods  (STMicroelectronics STM8), page 17.
Hexadecimal [24-Bits]

                           000007   770  TIM1_CCMR1_OC1CE = (7)
                           000006   771  TIM1_CCMR1_OC1M2 = (6)
                           000005   772  TIM1_CCMR1_OC1M1 = (5)
                           000004   773  TIM1_CCMR1_OC1M0 = (4)
                           000004   774  TIM1_CCMR1_OCMODE=(4)
                           000003   775  TIM1_CCMR1_OC1PE = (3)
                           000002   776  TIM1_CCMR1_OC1FE = (2)
                           000001   777  TIM1_CCMR1_CC1S1 = (1)
                           000000   778  TIM1_CCMR1_CC1S0 = (0)
                                    779 
                                    780 ; Capture/Compare Mode Register 1 - channel configured in input
                           000007   781  TIM1_CCMR1_IC1F3 = (7)
                           000006   782  TIM1_CCMR1_IC1F2 = (6)
                           000005   783  TIM1_CCMR1_IC1F1 = (5)
                           000004   784  TIM1_CCMR1_IC1F0 = (4)
                           000003   785  TIM1_CCMR1_IC1PSC1 = (3)
                           000002   786  TIM1_CCMR1_IC1PSC0 = (2)
                                    787 ;  TIM1_CCMR1_CC1S1 = (1)
                           000000   788  TIM1_CCMR1_CC1S0 = (0)
                                    789 
                                    790 ; Capture/Compare Mode Register 2 - channel configured in output
                           000007   791  TIM1_CCMR2_OC2CE = (7)
                           000006   792  TIM1_CCMR2_OC2M2 = (6)
                           000005   793  TIM1_CCMR2_OC2M1 = (5)
                           000004   794  TIM1_CCMR2_OC2M0 = (4)
                           000004   795  TIM1_CCMR2_OCMODE=(4)
                           000003   796  TIM1_CCMR2_OC2PE = (3)
                           000002   797  TIM1_CCMR2_OC2FE = (2)
                           000001   798  TIM1_CCMR2_CC2S1 = (1)
                           000000   799  TIM1_CCMR2_CC2S0 = (0)
                                    800 
                                    801 ; Capture/Compare Mode Register 2 - channel configured in input
                           000007   802  TIM1_CCMR2_IC2F3 = (7)
                           000006   803  TIM1_CCMR2_IC2F2 = (6)
                           000005   804  TIM1_CCMR2_IC2F1 = (5)
                           000004   805  TIM1_CCMR2_IC2F0 = (4)
                           000003   806  TIM1_CCMR2_IC2PSC1 = (3)
                           000002   807  TIM1_CCMR2_IC2PSC0 = (2)
                                    808 ;  TIM1_CCMR2_CC2S1 = (1)
                           000000   809  TIM1_CCMR2_CC2S0 = (0)
                                    810 
                                    811 ; Capture/Compare Mode Register 3 - channel configured in output
                           000007   812  TIM1_CCMR3_OC3CE = (7)
                           000006   813  TIM1_CCMR3_OC3M2 = (6)
                           000005   814  TIM1_CCMR3_OC3M1 = (5)
                           000004   815  TIM1_CCMR3_OC3M0 = (4)
                           000004   816  TIM1_CCMR3_OCMODE = (4)
                           000003   817  TIM1_CCMR3_OC3PE = (3)
                           000002   818  TIM1_CCMR3_OC3FE = (2)
                           000001   819  TIM1_CCMR3_CC3S1 = (1)
                           000000   820  TIM1_CCMR3_CC3S0 = (0)
                                    821 
                                    822 ; Capture/Compare Mode Register 3 - channel configured in input
                           000007   823  TIM1_CCMR3_IC3F3 = (7)
                           000006   824  TIM1_CCMR3_IC3F2 = (6)

ASxxxx Assembler V02.00 + NoICE + SDCC mods  (STMicroelectronics STM8), page 18.
Hexadecimal [24-Bits]

                           000005   825  TIM1_CCMR3_IC3F1 = (5)
                           000004   826  TIM1_CCMR3_IC3F0 = (4)
                           000003   827  TIM1_CCMR3_IC3PSC1 = (3)
                           000002   828  TIM1_CCMR3_IC3PSC0 = (2)
                                    829 ;  TIM1_CCMR3_CC3S1 = (1)
                           000000   830  TIM1_CCMR3_CC3S0 = (0)
                                    831 
                                    832 ; Capture/Compare Mode Register 4 - channel configured in output
                           000007   833  TIM1_CCMR4_OC4CE = (7)
                           000006   834  TIM1_CCMR4_OC4M2 = (6)
                           000005   835  TIM1_CCMR4_OC4M1 = (5)
                           000004   836  TIM1_CCMR4_OC4M0 = (4)
                           000004   837  TIM1_CCMR4_OCMODE = (4)
                           000003   838  TIM1_CCMR4_OC4PE = (3)
                           000002   839  TIM1_CCMR4_OC4FE = (2)
                           000001   840  TIM1_CCMR4_CC4S1 = (1)
                           000000   841  TIM1_CCMR4_CC4S0 = (0)
                                    842 
                                    843 ; Capture/Compare Mode Register 4 - channel configured in input
                           000007   844  TIM1_CCMR4_IC4F3 = (7)
                           000006   845  TIM1_CCMR4_IC4F2 = (6)
                           000005   846  TIM1_CCMR4_IC4F1 = (5)
                           000004   847  TIM1_CCMR4_IC4F0 = (4)
                           000003   848  TIM1_CCMR4_IC4PSC1 = (3)
                           000002   849  TIM1_CCMR4_IC4PSC0 = (2)
                                    850 ;  TIM1_CCMR4_CC4S1 = (1)
                           000000   851  TIM1_CCMR4_CC4S0 = (0)
                                    852 
                                    853 ; Timer 2 - 16-bit timer
                           005300   854  TIM2_CR1  = (0x5300)
                           005301   855  TIM2_IER  = (0x5301)
                           005302   856  TIM2_SR1  = (0x5302)
                           005303   857  TIM2_SR2  = (0x5303)
                           005304   858  TIM2_EGR  = (0x5304)
                           005305   859  TIM2_CCMR1  = (0x5305)
                           005306   860  TIM2_CCMR2  = (0x5306)
                           005307   861  TIM2_CCMR3  = (0x5307)
                           005308   862  TIM2_CCER1  = (0x5308)
                           005309   863  TIM2_CCER2  = (0x5309)
                           00530A   864  TIM2_CNTRH  = (0x530A)
                           00530B   865  TIM2_CNTRL  = (0x530B)
                           00530C   866  TIM2_PSCR  = (0x530C)
                           00530D   867  TIM2_ARRH  = (0x530D)
                           00530E   868  TIM2_ARRL  = (0x530E)
                           00530F   869  TIM2_CCR1H  = (0x530F)
                           005310   870  TIM2_CCR1L  = (0x5310)
                           005311   871  TIM2_CCR2H  = (0x5311)
                           005312   872  TIM2_CCR2L  = (0x5312)
                           005313   873  TIM2_CCR3H  = (0x5313)
                           005314   874  TIM2_CCR3L  = (0x5314)
                                    875 
                                    876 ; TIM2_CR1 bitfields
                           000000   877  TIM2_CR1_CEN=(0) ; Counter enable
                           000001   878  TIM2_CR1_UDIS=(1) ; Update disable
                           000002   879  TIM2_CR1_URS=(2) ; Update request source

ASxxxx Assembler V02.00 + NoICE + SDCC mods  (STMicroelectronics STM8), page 19.
Hexadecimal [24-Bits]

                           000003   880  TIM2_CR1_OPM=(3) ; One-pulse mode
                           000007   881  TIM2_CR1_ARPE=(7) ; Auto-reload preload enable
                                    882 
                                    883 ; TIMER2_CCMR bitfields 
                           000000   884  TIM2_CCMR_CCS=(0) ; input/output select
                           000003   885  TIM2_CCMR_OCPE=(3) ; preload enable
                           000004   886  TIM2_CCMR_OCM=(4)  ; output compare mode 
                                    887 
                                    888 ; TIMER2_CCER1 bitfields
                           000000   889  TIM2_CCER1_CC1E=(0)
                           000001   890  TIM2_CCER1_CC1P=(1)
                           000004   891  TIM2_CCER1_CC2E=(4)
                           000005   892  TIM2_CCER1_CC2P=(5)
                                    893 
                                    894 ; TIMER2_EGR bitfields
                           000000   895  TIM2_EGR_UG=(0) ; update generation
                           000001   896  TIM2_EGR_CC1G=(1) ; Capture/compare 1 generation
                           000002   897  TIM2_EGR_CC2G=(2) ; Capture/compare 2 generation
                           000003   898  TIM2_EGR_CC3G=(3) ; Capture/compare 3 generation
                           000006   899  TIM2_EGR_TG=(6); Trigger generation
                                    900 
                                    901 ; Timer 3
                           005320   902  TIM3_CR1  = (0x5320)
                           005321   903  TIM3_IER  = (0x5321)
                           005322   904  TIM3_SR1  = (0x5322)
                           005323   905  TIM3_SR2  = (0x5323)
                           005324   906  TIM3_EGR  = (0x5324)
                           005325   907  TIM3_CCMR1  = (0x5325)
                           005326   908  TIM3_CCMR2  = (0x5326)
                           005327   909  TIM3_CCER1  = (0x5327)
                           005328   910  TIM3_CNTRH  = (0x5328)
                           005329   911  TIM3_CNTRL  = (0x5329)
                           00532A   912  TIM3_PSCR  = (0x532A)
                           00532B   913  TIM3_ARRH  = (0x532B)
                           00532C   914  TIM3_ARRL  = (0x532C)
                           00532D   915  TIM3_CCR1H  = (0x532D)
                           00532E   916  TIM3_CCR1L  = (0x532E)
                           00532F   917  TIM3_CCR2H  = (0x532F)
                           005330   918  TIM3_CCR2L  = (0x5330)
                                    919 
                                    920 ; TIM3_CR1  fields
                           000000   921  TIM3_CR1_CEN = (0)
                           000001   922  TIM3_CR1_UDIS = (1)
                           000002   923  TIM3_CR1_URS = (2)
                           000003   924  TIM3_CR1_OPM = (3)
                           000007   925  TIM3_CR1_ARPE = (7)
                                    926 ; TIM3_CCR2  fields
                           000000   927  TIM3_CCMR2_CC2S_POS = (0)
                           000003   928  TIM3_CCMR2_OC2PE_POS = (3)
                           000004   929  TIM3_CCMR2_OC2M_POS = (4)  
                                    930 ; TIM3_CCER1 fields
                           000000   931  TIM3_CCER1_CC1E = (0)
                           000001   932  TIM3_CCER1_CC1P = (1)
                           000004   933  TIM3_CCER1_CC2E = (4)
                           000005   934  TIM3_CCER1_CC2P = (5)

ASxxxx Assembler V02.00 + NoICE + SDCC mods  (STMicroelectronics STM8), page 20.
Hexadecimal [24-Bits]

                                    935 ; TIM3_CCER2 fields
                           000000   936  TIM3_CCER2_CC3E = (0)
                           000001   937  TIM3_CCER2_CC3P = (1)
                                    938 
                                    939 ; Timer 4
                           005340   940  TIM4_CR1  = (0x5340)
                           005341   941  TIM4_IER  = (0x5341)
                           005342   942  TIM4_SR  = (0x5342)
                           005343   943  TIM4_EGR  = (0x5343)
                           005344   944  TIM4_CNTR  = (0x5344)
                           005345   945  TIM4_PSCR  = (0x5345)
                           005346   946  TIM4_ARR  = (0x5346)
                                    947 
                                    948 ; Timer 4 bitmasks
                                    949 
                           000007   950  TIM4_CR1_ARPE = (7)
                           000003   951  TIM4_CR1_OPM = (3)
                           000002   952  TIM4_CR1_URS = (2)
                           000001   953  TIM4_CR1_UDIS = (1)
                           000000   954  TIM4_CR1_CEN = (0)
                                    955 
                           000000   956  TIM4_IER_UIE = (0)
                                    957 
                           000000   958  TIM4_SR_UIF = (0)
                                    959 
                           000000   960  TIM4_EGR_UG = (0)
                                    961 
                           000002   962  TIM4_PSCR_PSC2 = (2)
                           000001   963  TIM4_PSCR_PSC1 = (1)
                           000000   964  TIM4_PSCR_PSC0 = (0)
                                    965 
                           000000   966  TIM4_PSCR_1 = 0
                           000001   967  TIM4_PSCR_2 = 1
                           000002   968  TIM4_PSCR_4 = 2
                           000003   969  TIM4_PSCR_8 = 3
                           000004   970  TIM4_PSCR_16 = 4
                           000005   971  TIM4_PSCR_32 = 5
                           000006   972  TIM4_PSCR_64 = 6
                           000007   973  TIM4_PSCR_128 = 7
                                    974 
                                    975 ; ADC2
                           005400   976  ADC_CSR  = (0x5400)
                           005401   977  ADC_CR1  = (0x5401)
                           005402   978  ADC_CR2  = (0x5402)
                           005403   979  ADC_CR3  = (0x5403)
                           005404   980  ADC_DRH  = (0x5404)
                           005405   981  ADC_DRL  = (0x5405)
                           005406   982  ADC_TDRH  = (0x5406)
                           005407   983  ADC_TDRL  = (0x5407)
                                    984  
                                    985 ; ADC bitmasks
                                    986 
                           000007   987  ADC_CSR_EOC = (7)
                           000006   988  ADC_CSR_AWD = (6)
                           000005   989  ADC_CSR_EOCIE = (5)

ASxxxx Assembler V02.00 + NoICE + SDCC mods  (STMicroelectronics STM8), page 21.
Hexadecimal [24-Bits]

                           000004   990  ADC_CSR_AWDIE = (4)
                           000003   991  ADC_CSR_CH3 = (3)
                           000002   992  ADC_CSR_CH2 = (2)
                           000001   993  ADC_CSR_CH1 = (1)
                           000000   994  ADC_CSR_CH0 = (0)
                                    995 
                           000006   996  ADC_CR1_SPSEL2 = (6)
                           000005   997  ADC_CR1_SPSEL1 = (5)
                           000004   998  ADC_CR1_SPSEL0 = (4)
                           000001   999  ADC_CR1_CONT = (1)
                           000000  1000  ADC_CR1_ADON = (0)
                                   1001 
                           000006  1002  ADC_CR2_EXTTRIG = (6)
                           000005  1003  ADC_CR2_EXTSEL1 = (5)
                           000004  1004  ADC_CR2_EXTSEL0 = (4)
                           000003  1005  ADC_CR2_ALIGN = (3)
                           000001  1006  ADC_CR2_SCAN = (1)
                                   1007 
                           000007  1008  ADC_CR3_DBUF = (7)
                           000006  1009  ADC_CR3_DRH = (6)
                                   1010 
                                   1011 ; beCAN
                           005420  1012  CAN_MCR = (0x5420)
                           005421  1013  CAN_MSR = (0x5421)
                           005422  1014  CAN_TSR = (0x5422)
                           005423  1015  CAN_TPR = (0x5423)
                           005424  1016  CAN_RFR = (0x5424)
                           005425  1017  CAN_IER = (0x5425)
                           005426  1018  CAN_DGR = (0x5426)
                           005427  1019  CAN_FPSR = (0x5427)
                           005428  1020  CAN_P0 = (0x5428)
                           005429  1021  CAN_P1 = (0x5429)
                           00542A  1022  CAN_P2 = (0x542A)
                           00542B  1023  CAN_P3 = (0x542B)
                           00542C  1024  CAN_P4 = (0x542C)
                           00542D  1025  CAN_P5 = (0x542D)
                           00542E  1026  CAN_P6 = (0x542E)
                           00542F  1027  CAN_P7 = (0x542F)
                           005430  1028  CAN_P8 = (0x5430)
                           005431  1029  CAN_P9 = (0x5431)
                           005432  1030  CAN_PA = (0x5432)
                           005433  1031  CAN_PB = (0x5433)
                           005434  1032  CAN_PC = (0x5434)
                           005435  1033  CAN_PD = (0x5435)
                           005436  1034  CAN_PE = (0x5436)
                           005437  1035  CAN_PF = (0x5437)
                                   1036 
                                   1037 
                                   1038 ; CPU
                           007F00  1039  CPU_A  = (0x7F00)
                           007F01  1040  CPU_PCE  = (0x7F01)
                           007F02  1041  CPU_PCH  = (0x7F02)
                           007F03  1042  CPU_PCL  = (0x7F03)
                           007F04  1043  CPU_XH  = (0x7F04)
                           007F05  1044  CPU_XL  = (0x7F05)

ASxxxx Assembler V02.00 + NoICE + SDCC mods  (STMicroelectronics STM8), page 22.
Hexadecimal [24-Bits]

                           007F06  1045  CPU_YH  = (0x7F06)
                           007F07  1046  CPU_YL  = (0x7F07)
                           007F08  1047  CPU_SPH  = (0x7F08)
                           007F09  1048  CPU_SPL   = (0x7F09)
                           007F0A  1049  CPU_CCR   = (0x7F0A)
                                   1050 
                                   1051 ; global configuration register
                           007F60  1052  CFG_GCR   = (0x7F60)
                           000001  1053  CFG_GCR_AL = 1
                           000000  1054  CFG_GCR_SWIM = 0
                                   1055 
                                   1056 ; interrupt software priority 
                           007F70  1057  ITC_SPR1   = (0x7F70) ; (0..3) 0->resreved,AWU..EXT0 
                           007F71  1058  ITC_SPR2   = (0x7F71) ; (4..7) EXT1..EXT4 RX 
                           007F72  1059  ITC_SPR3   = (0x7F72) ; (8..11) beCAN RX..TIM1 UPDT/OVR  
                           007F73  1060  ITC_SPR4   = (0x7F73) ; (12..15) TIM1 CAP/CMP .. TIM3 UPDT/OVR 
                           007F74  1061  ITC_SPR5   = (0x7F74) ; (16..19) TIM3 CAP/CMP..I2C  
                           007F75  1062  ITC_SPR6   = (0x7F75) ; (20..23) UART3 TX..TIM4 CAP/OVR 
                           007F76  1063  ITC_SPR7   = (0x7F76) ; (24..29) FLASH WR..
                           007F77  1064  ITC_SPR8   = (0x7F77) ; (30..32) ..
                                   1065 
                           000001  1066 ITC_SPR_LEVEL1=1 
                           000000  1067 ITC_SPR_LEVEL2=0
                           000003  1068 ITC_SPR_LEVEL3=3 
                                   1069 
                                   1070 ; SWIM, control and status register
                           007F80  1071  SWIM_CSR   = (0x7F80)
                                   1072 ; debug registers
                           007F90  1073  DM_BK1RE   = (0x7F90)
                           007F91  1074  DM_BK1RH   = (0x7F91)
                           007F92  1075  DM_BK1RL   = (0x7F92)
                           007F93  1076  DM_BK2RE   = (0x7F93)
                           007F94  1077  DM_BK2RH   = (0x7F94)
                           007F95  1078  DM_BK2RL   = (0x7F95)
                           007F96  1079  DM_CR1   = (0x7F96)
                           007F97  1080  DM_CR2   = (0x7F97)
                           007F98  1081  DM_CSR1   = (0x7F98)
                           007F99  1082  DM_CSR2   = (0x7F99)
                           007F9A  1083  DM_ENFCTR   = (0x7F9A)
                                   1084 
                                   1085 ; Interrupt Numbers
                           000000  1086  INT_TLI = 0
                           000001  1087  INT_AWU = 1
                           000002  1088  INT_CLK = 2
                           000003  1089  INT_EXTI0 = 3
                           000004  1090  INT_EXTI1 = 4
                           000005  1091  INT_EXTI2 = 5
                           000006  1092  INT_EXTI3 = 6
                           000007  1093  INT_EXTI4 = 7
                           000008  1094  INT_CAN_RX = 8
                           000009  1095  INT_CAN_TX = 9
                           00000A  1096  INT_SPI = 10
                           00000B  1097  INT_TIM1_OVF = 11
                           00000C  1098  INT_TIM1_CCM = 12
                           00000D  1099  INT_TIM2_OVF = 13

ASxxxx Assembler V02.00 + NoICE + SDCC mods  (STMicroelectronics STM8), page 23.
Hexadecimal [24-Bits]

                           00000E  1100  INT_TIM2_CCM = 14
                           00000F  1101  INT_TIM3_OVF = 15
                           000010  1102  INT_TIM3_CCM = 16
                           000011  1103  INT_UART1_TX_COMPLETED = 17
                           000012  1104  INT_AUART1_RX_FULL = 18
                           000013  1105  INT_I2C = 19
                           000014  1106  INT_UART3_TX_COMPLETED = 20
                           000015  1107  INT_UART3_RX_FULL = 21
                           000016  1108  INT_ADC2 = 22
                           000017  1109  INT_TIM4_OVF = 23
                           000018  1110  INT_FLASH = 24
                                   1111 
                                   1112 ; Interrupt Vectors
                           008000  1113  INT_VECTOR_RESET = 0x8000
                           008004  1114  INT_VECTOR_TRAP = 0x8004
                           008008  1115  INT_VECTOR_TLI = 0x8008
                           00800C  1116  INT_VECTOR_AWU = 0x800C
                           008010  1117  INT_VECTOR_CLK = 0x8010
                           008014  1118  INT_VECTOR_EXTI0 = 0x8014
                           008018  1119  INT_VECTOR_EXTI1 = 0x8018
                           00801C  1120  INT_VECTOR_EXTI2 = 0x801C
                           008020  1121  INT_VECTOR_EXTI3 = 0x8020
                           008024  1122  INT_VECTOR_EXTI4 = 0x8024
                           008028  1123  INT_VECTOR_CAN_RX = 0x8028
                           00802C  1124  INT_VECTOR_CAN_TX = 0x802c
                           008030  1125  INT_VECTOR_SPI = 0x8030
                           008034  1126  INT_VECTOR_TIM1_OVF = 0x8034
                           008038  1127  INT_VECTOR_TIM1_CCM = 0x8038
                           00803C  1128  INT_VECTOR_TIM2_OVF = 0x803C
                           008040  1129  INT_VECTOR_TIM2_CCM = 0x8040
                           008044  1130  INT_VECTOR_TIM3_OVF = 0x8044
                           008048  1131  INT_VECTOR_TIM3_CCM = 0x8048
                           00804C  1132  INT_VECTOR_UART1_TX_COMPLETED = 0x804c
                           008050  1133  INT_VECTOR_UART1_RX_FULL = 0x8050
                           008054  1134  INT_VECTOR_I2C = 0x8054
                           008058  1135  INT_VECTOR_UART3_TX_COMPLETED = 0x8058
                           00805C  1136  INT_VECTOR_UART3_RX_FULL = 0x805C
                           008060  1137  INT_VECTOR_ADC2 = 0x8060
                           008064  1138  INT_VECTOR_TIM4_OVF = 0x8064
                           008068  1139  INT_VECTOR_FLASH = 0x8068
                                   1140 
                                   1141 ; Condition code register bits
                           000007  1142 CC_V = 7  ; overflow flag 
                           000005  1143 CC_I1= 5  ; interrupt bit 1
                           000004  1144 CC_H = 4  ; half carry 
                           000003  1145 CC_I0 = 3 ; interrupt bit 0
                           000002  1146 CC_N = 2 ;  negative flag 
                           000001  1147 CC_Z = 1 ;  zero flag  
                           000000  1148 CC_C = 0 ; carry bit 

ASxxxx Assembler V02.00 + NoICE + SDCC mods  (STMicroelectronics STM8), page 24.
Hexadecimal [24-Bits]

                                     21 	.include "inc/ascii.inc"
                                      1 ;;
                                      2 ; Copyright Jacques Deschênes 2021
                                      3 ; This file is part of stm32-tbi 
                                      4 ;
                                      5 ;     stm32-tbi is free software: you can redistribute it and/or modify
                                      6 ;     it under the terms of the GNU General Public License as published by
                                      7 ;     the Free Software Foundation, either version 3 of the License, or
                                      8 ;     (at your option) any later version.
                                      9 ;
                                     10 ;     stm32-tbi is distributed in the hope that it will be useful,
                                     11 ;     but WITHOUT ANY WARRANTY; without even the implied warranty of
                                     12 ;     MERCHANTABILITY or FITNESS FOR A PARTICULAR PURPOSE.  See the
                                     13 ;     GNU General Public License for more details.
                                     14 ;
                                     15 ;     You should have received a copy of the GNU General Public License
                                     16 ;     along with stm32-tbi.  If not, see <http:;www.gnu.org/licenses/>.
                                     17 ;;
                                     18 
                                     19 ;-------------------------------------------------------
                                     20 ;     ASCII control  values
                                     21 ;     CTRL_x   are VT100 keyboard values  
                                     22 ; REF: https:;en.wikipedia.org/wiki/ASCII    
                                     23 ;-------------------------------------------------------
                           000001    24 	 CTRL_A = 1
                           000001    25 	 SOH=CTRL_A  ; start of heading 
                           000002    26 	 CTRL_B = 2
                           000002    27 	 STRX = CTRL_B  ; start of text 
                           000003    28 	 CTRL_C = 3
                           000003    29 	 ETX=CTRL_C  ; end of text 
                           000004    30 	 CTRL_D = 4
                           000004    31 	 EOT=CTRL_D  ; end of transmission 
                           000005    32 	 CTRL_E = 5
                           000005    33 	 ENQ=CTRL_E  ; enquery 
                           000006    34 	 CTRL_F = 6
                           000006    35 	 ACK=CTRL_F  ; acknowledge
                           000007    36 	 CTRL_G = 7
                           000007    37 	 BELL = 7    ; vt100 terminal generate a sound.
                           000008    38 	 CTRL_H = 8  
                           000008    39 	 BS = 8     ; back space 
                           000009    40 	 CTRL_I = 9
                           000009    41 	 TAB = 9     ; horizontal tabulation
                           00000A    42 	 CTRL_J = 10 
                           00000A    43 	 LF = 10     ; line feed
                           00000B    44 	 CTRL_K = 11
                           00000B    45 	 VT = 11     ; vertical tabulation 
                           00000C    46 	 CTRL_L = 12
                           00000C    47 	 FF = 12      ; new page
                           00000D    48 	 CTRL_M = 13
                           00000D    49 	 CR = 13      ; carriage return 
                           00000E    50 	 CTRL_N = 14
                           00000E    51 	 SO=CTRL_N    ; shift out 
                           00000F    52 	 CTRL_O = 15
                           00000F    53 	 SI=CTRL_O    ; shift in 
                           000010    54 	 CTRL_P = 16

ASxxxx Assembler V02.00 + NoICE + SDCC mods  (STMicroelectronics STM8), page 25.
Hexadecimal [24-Bits]

                           000010    55 	 DLE=CTRL_P   ; data link escape 
                           000011    56 	 CTRL_Q = 17
                           000011    57 	 DC1=CTRL_Q   ; device control 1 
                           000011    58 	 XON=DC1 
                           000012    59 	 CTRL_R = 18
                           000012    60 	 DC2=CTRL_R   ; device control 2 
                           000013    61 	 CTRL_S = 19
                           000013    62 	 DC3=CTRL_S   ; device control 3
                           000013    63 	 XOFF=DC3 
                           000014    64 	 CTRL_T = 20
                           000014    65 	 DC4=CTRL_T   ; device control 4 
                           000015    66 	 CTRL_U = 21
                           000015    67 	 NAK=CTRL_U   ; negative acknowledge
                           000016    68 	 CTRL_V = 22
                           000016    69 	 SYN=CTRL_V   ; synchronous idle 
                           000017    70 	 CTRL_W = 23
                           000017    71 	 ETB=CTRL_W   ; end of transmission block
                           000018    72 	 CTRL_X = 24
                           000018    73 	 CAN=CTRL_X   ; cancel 
                           000019    74 	 CTRL_Y = 25
                           000019    75 	 EM=CTRL_Y    ; end of medium
                           00001A    76 	 CTRL_Z = 26
                           00001A    77 	 SUB=CTRL_Z   ; substitute 
                           00001A    78 	 EOF=SUB      ; end of text file in MSDOS 
                           00001B    79 	 ESC = 27     ; escape 
                           00001C    80 	 FS=28        ; file separator 
                           00001D    81 	 GS=29        ; group separator 
                           00001E    82 	 RS=30  ; record separator 
                           00001F    83 	 US=31  ; unit separator 
                           000020    84 	 SPACE = 32
                           00002C    85 	 COMMA = 44 
                           000023    86 	 SHARP = 35
                           000027    87 	 TICK = 39
                                     88 ;	 DOT = $2E
                                     89 ;	 COLUMN = $3A

ASxxxx Assembler V02.00 + NoICE + SDCC mods  (STMicroelectronics STM8), page 26.
Hexadecimal [24-Bits]

                                     22 	.include "inc/gen_macros.inc" 
                                      1 ;;
                                      2 ; Copyright Jacques Deschênes 2019 
                                      3 ; This file is part of STM8_NUCLEO 
                                      4 ;
                                      5 ;     STM8_NUCLEO is free software: you can redistribute it and/or modify
                                      6 ;     it under the terms of the GNU General Public License as published by
                                      7 ;     the Free Software Foundation, either version 3 of the License, or
                                      8 ;     (at your option) any later version.
                                      9 ;
                                     10 ;     STM8_NUCLEO is distributed in the hope that it will be useful,
                                     11 ;     but WITHOUT ANY WARRANTY; without even the implied warranty of
                                     12 ;     MERCHANTABILITY or FITNESS FOR A PARTICULAR PURPOSE.  See the
                                     13 ;     GNU General Public License for more details.
                                     14 ;
                                     15 ;     You should have received a copy of the GNU General Public License
                                     16 ;     along with STM8_NUCLEO.  If not, see <http://www.gnu.org/licenses/>.
                                     17 ;;
                                     18 ;--------------------------------------
                                     19 ;   console Input/Output module
                                     20 ;   DATE: 2019-12-11
                                     21 ;    
                                     22 ;   General usage macros.   
                                     23 ;
                                     24 ;--------------------------------------
                                     25 
                                     26     ; reserve space on stack
                                     27     ; for local variables
                                     28     .macro _vars n 
                                     29     sub sp,#n 
                                     30     .endm 
                                     31     
                                     32     ; free space on stack
                                     33     .macro _drop n 
                                     34     addw sp,#n 
                                     35     .endm
                                     36 
                                     37     ; declare ARG_OFS for arguments 
                                     38     ; displacement on stack. This 
                                     39     ; value depend on local variables 
                                     40     ; size.
                                     41     .macro _argofs n 
                                     42     ARG_OFS=2+n 
                                     43     .endm 
                                     44 
                                     45     ; declare a function argument 
                                     46     ; position relative to stack pointer 
                                     47     ; _argofs must be called before it.
                                     48     .macro _arg name ofs 
                                     49     name=ARG_OFS+ofs 
                                     50     .endm 
                                     51 
                                     52     ; software reset 
                                     53     .macro _swreset
                                     54     mov WWDG_CR,#0X80

ASxxxx Assembler V02.00 + NoICE + SDCC mods  (STMicroelectronics STM8), page 27.
Hexadecimal [24-Bits]

                                     55     .endm 
                                     56 
                                     57     ; increment zero page variable 
                                     58     .macro _incz v 
                                     59     .byte 0x3c, v 
                                     60     .endm 
                                     61 
                                     62     ; decrement zero page variable 
                                     63     .macro _decz v 
                                     64     .byte 0x3a,v 
                                     65     .endm 
                                     66 
                                     67     ; clear zero page variable 
                                     68     .macro _clrz v 
                                     69     .byte 0x3f, v 
                                     70     .endm 
                                     71 
                                     72     ; load A zero page variable 
                                     73     .macro _ldaz v 
                                     74     .byte 0xb6,v 
                                     75     .endm 
                                     76 
                                     77     ; store A zero page variable 
                                     78     .macro _straz v 
                                     79     .byte 0xb7,v 
                                     80     .endm 
                                     81 
                                     82     ; tnz zero page variable 
                                     83     .macro _tnz v 
                                     84     .byte 0x3d,v 
                                     85     .endm 
                                     86 
                                     87     ; load x from variable in zero page 
                                     88     .macro _ldxz v 
                                     89     .byte 0xbe,v 
                                     90     .endm 
                                     91 
                                     92     ; load y from variable in zero page 
                                     93     .macro _ldyz v 
                                     94     .byte 0x90,0xbe,v 
                                     95     .endm 
                                     96 
                                     97     ; store x in zero page variable 
                                     98     .macro _strxz v 
                                     99     .byte 0xbf,v 
                                    100     .endm 
                                    101 
                                    102     ; store y in zero page variable 
                                    103     .macro _stryz v 
                                    104     .byte 0x90,0xbf,v 
                                    105     .endm 
                                    106 
                                    107     ;  increment 16 bits variable
                                    108     ;  use 10 bytes  
                                    109     .macro _incwz  v 

ASxxxx Assembler V02.00 + NoICE + SDCC mods  (STMicroelectronics STM8), page 28.
Hexadecimal [24-Bits]

                                    110         _incz v+1   ; 1 cy, 2 bytes 
                                    111         jrne .+4  ; 1|2 cy, 2 bytes 
                                    112         _incz v     ; 1 cy, 2 bytes  
                                    113     .endm ; 3 cy 
                                    114 
                                    115     ; xor op with zero page variable 
                                    116     .macro _xorz v 
                                    117     .byte 0xb8,v 
                                    118     .endm 
                                    119     
                                    120     ; move memory to memory in 0 page 
                                    121     .macro _movzz a1, a2 
                                    122     .byte 0x45,a2,a1 
                                    123     .endm 
                                    124 
                                    125     ; check point 
                                    126     ; for debugging help 
                                    127     ; display a character 
                                    128     .macro _cp ch 
                                    129     push a 
                                    130     ld a,#ch 
                                    131     call uart_putc 
                                    132     pop a 
                                    133     .endm 
                                    134     

ASxxxx Assembler V02.00 + NoICE + SDCC mods  (STMicroelectronics STM8), page 29.
Hexadecimal [24-Bits]

                                     23 	.include "app_macros.inc" 
                                      1 ;;
                                      2 ; Copyright Jacques Deschênes 2019 
                                      3 ; This file is part of STM8_NUCLEO 
                                      4 ;
                                      5 ;     STM8_NUCLEO is free software: you can redistribute it and/or modify
                                      6 ;     it under the terms of the GNU General Public License as published by
                                      7 ;     the Free Software Foundation, either version 3 of the License, or
                                      8 ;     (at your option) any later version.
                                      9 ;
                                     10 ;     STM8_NUCLEO is distributed in the hope that it will be useful,
                                     11 ;     but WITHOUT ANY WARRANTY; without even the implied warranty of
                                     12 ;     MERCHANTABILITY or FITNESS FOR A PARTICULAR PURPOSE.  See the
                                     13 ;     GNU General Public License for more details.
                                     14 ;
                                     15 ;     You should have received a copy of the GNU General Public License
                                     16 ;     along with STM8_NUCLEO.  If not, see <http://www.gnu.org/licenses/>.
                                     17 ;;
                                     18 ;--------------------------------------
                           000004    19         TAB_WIDTH=4 ; default tabulation width 
                           0000FF    20         EOF=0xff ; end of file marker 
                           00000F    21         NLEN_MASK=0xf  ; mask to extract name len 
                                     22 
                                     23 
                           000080    24 	STACK_SIZE=128
                           0017FF    25 	STACK_EMPTY=RAM_SIZE-1  
                                     26 	
                                     27 

ASxxxx Assembler V02.00 + NoICE + SDCC mods  (STMicroelectronics STM8), page 30.
Hexadecimal [24-Bits]

                                     24 
                                     25 ;UART=UART3 
                                     26 
                                     27 ; interface port 
                                     28 ; communication with computer PIA W65C22 PORT A 
                                     29 ; using 8 bits bus. 
                           00500F    30 ITF_PORT=PD_BASE ; data transfert bus 
                           005011    31 ITF_DDR=PD_DDR 
                           00500F    32 ITF_ODR=PD_ODR 
                           005010    33 ITF_IDR=PD_IDR 
                           005012    34 ITF_CR1=PD_CR1 
                           005013    35 ITF_CR2=PD_CR2 
                                     36 ; handshake 
                           005005    37 ITF_CTRL_PORT=PB_BASE 
                           005005    38 ITF_CTRL_ODR=PB_ODR 
                           005006    39 ITF_CTRL_IDR=PB_IDR 
                           005007    40 ITF_CTRL_DDR=PB_DDR 
                           005008    41 ITF_CTRL_CR1=PB_CR1 
                           005009    42 ITF_CTRL_CR2=PB_CR2
                                     43 ; handshake control lines 
                           000001    44 ITF_CA1=BIT1 ; drive ready signal on PB1 
                           000000    45 ITF_CA2=BIT0 ; computer ready signal on PB0 
                           0050A0    46 EXTI_CR=EXTI_CR1 ; external interrupt control register 
                           000002    47 ITF_CA2_PBIS=BIT2 ; EXTI_CR1 ext. int. control bits 2:3 
                           000005    48 ITF_SELECT=BIT5 ; serial/parallel interface select
                                     49 
                                     50 ;----------------------------------
                                     51 ;  MACROS  
                                     52 ;----------------------------------
                                     53 
                                     54     ; write byte to interface 
                                     55     .macro _itf_write
                                     56     bset flags,#FTX  
                                     57     btjf flags,#FCOMP_RDY,.
                                     58     ld ITF_ODR,a 
                                     59     bset ITF_CTRL_ODR,#ITF_CA1 
                                     60     ld a,#5 
                                     61 1$: dec a 
                                     62     jrne 1$ 
                                     63     bres ITF_CTRL_ODR,#ITF_CA1 
                                     64     .endm 
                                     65 
                                     66 ; clock enable bit 
                           000003    67 UART_PCKEN=CLK_PCKENR1_UART3 
                                     68 
                                     69 ; uart registers 
                           005240    70 UART_SR=UART3_SR
                           005241    71 UART_DR=UART3_DR
                           005242    72 UART_BRR1=UART3_BRR1
                           005243    73 UART_BRR2=UART3_BRR2
                           005244    74 UART_CR1=UART3_CR1
                           005245    75 UART_CR2=UART3_CR2
                                     76 
                                     77 ; TX, RX pin
                           000005    78 UART_TX_PIN=UART3_TX_PIN 

ASxxxx Assembler V02.00 + NoICE + SDCC mods  (STMicroelectronics STM8), page 31.
Hexadecimal [24-Bits]

                           000006    79 UART_RX_PIN=UART3_RX_PIN 
                                     80 ;-------------------------
                                     81 ;  SPI interface 
                                     82 ;-------------------------
                                     83 ; SPI port 
                           00500A    84 SPI_PORT= PC_BASE
                           00500A    85 SPI_PORT_ODR=PC_ODR 
                           00500B    86 SPI_PORT_IDR=PC_IDR 
                           00500C    87 SPI_PORT_DDR=PC_DDR 
                           00500D    88 SPI_PORT_CR1=PC_CR1 
                           00500E    89 SPI_PORT_CR2=PC_CR2 
                                     90 ; spi pins bits 
                           000007    91 SPI_MISO= 7;PC7 
                           000006    92 SPI_MOSI= 6;PC6
                           000005    93 SPI_CLK=  5;PC5 
                                     94 ; SPI channel select pins 
                           000003    95 SPI_CS0=3   ; PC3 FLASH0  
                           000004    96 SPI_CS1=4   ; PC4 XRAM 
                           000002    97 SPI_CS2=2   ; PC2 external device 
                           000001    98 SPI_CS3=1   ; PC1 external device 
                           000003    99 FLASH0=SPI_CS0 ; fixed internal
                           000003   100 FLASH1=SPI_CS0 ; duplicate 
                           000004   101 FLASH2=SPI_CS1 ; external drive 
                           000002   102 FLASH3=SPI_CS2 ; external drive 
                           000004   103 XRAM=SPI_CS1 ; extended RAM  
                                    104 

ASxxxx Assembler V02.00 + NoICE + SDCC mods  (STMicroelectronics STM8), page 32.
Hexadecimal [24-Bits]
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

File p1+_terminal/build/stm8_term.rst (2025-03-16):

ASxxxx Assembler V02.00 + NoICE + SDCC mods  (STMicroelectronics STM8), page 1.
Hexadecimal [24-Bits]

                                      1 ;;
                                      2 ; Copyright Jacques Deschênes 2023  
                                      3 ; This file is part of stm8_terminal 
                                      4 ;
                                      5 ;     stm8_terminal is free software: you can redistribute it and/or modify
                                      6 ;     it under the terms of the GNU General Public License as published by
                                      7 ;     the Free Software Foundation, either version 3 of the License, or
                                      8 ;     (at your option) any later version.
                                      9 ;
                                     10 ;     stm8_terminal is distributed in the hope that it will be useful,
                                     11 ;     but WITHOUT ANY WARRANTY; without even the implied warranty of
                                     12 ;     MERCHANTABILITY or FITNESS FOR A PARTICULAR PURPOSE.  See the
                                     13 ;     GNU General Public License for more details.
                                     14 ;
                                     15 ;     You should have received a copy of the GNU General Public License
                                     16 ;     along with stm8_terminal.  If not, see <http://www.gnu.org/licenses/>.
                                     17 ;;
                                     18 
                                     19 ;;;;;;;;;;;;;;;;;;;;;;;;;;;;;;;
                                     20 ;;; hardware initialization
                                     21 ;;;;;;;;;;;;;;;;;;;;;;;;;;;;;; 
                                     22 
                                     23 ;------------------------
                                     24 ; if unified compilation 
                                     25 ; must be first in list 
                                     26 ;-----------------------
                                     27 
                                     28     .module HW_INIT 
                                     29 

ASxxxx Assembler V02.00 + NoICE + SDCC mods  (STMicroelectronics STM8), page 2.
Hexadecimal [24-Bits]

                                     30     .include "config.inc"
                                      1 ;;;;;;;;;;;;;;;;;;;;;;;;;;;;;;
                                      2 ;;  configuration parameters 
                                      3 ;;;;;;;;;;;;;;;;;;;;;;;;;;;;;;
                                      4 
                                      5 ;;;;;;;;;;;;;;;;;;;;;;;;;;;;;;;;;;;;;;;;;;;;;;;;;;
                                      6 ;;   NOTE: 
                                      7 ;;      ON NUCLEO_8S207K8 
                                      8 ;;      JUMPERS  SB3,SB4 MUST BE MOVED TO SB7,SB9 
                                      9 ;;;;;;;;;;;;;;;;;;;;;;;;;;;;;;;;;;;;;;;;;;;;;;;;;;
                                     10 
                           000000    11 DEBUG=0 ; set to 1 to include debugging code 
                                     12 
                                     13 ; version 
                           000001    14     MAJOR=1 
                           000001    15     MINOR=1 
                           000000    16     REV=0
                                     17     
                           000001    18 HSE=1   
                           000001    19 MAX_FREQ=1 ; 24MHZ maximum frequency, for 20Mhz crystal set to 0 
                           000001    20 .if MAX_FREQ   
                           000018    21 FMSTR=24 ; MHZ
                           000000    22 .else
                                     23 FMSTR=20 ; MHZ 
                                     24 .endif 
                                     25 
                                     26 

ASxxxx Assembler V02.00 + NoICE + SDCC mods  (STMicroelectronics STM8), page 3.
Hexadecimal [24-Bits]

                                     27     .include "inc/stm8s207.inc" 
                                      1 ;;
                                      2 ; Copyright Jacques Deschênes 2019,2022 
                                      3 ; This file is part of MONA 
                                      4 ;
                                      5 ;     MONA is free software: you can redistribute it and/or modify
                                      6 ;     it under the terms of the GNU General Public License as published by
                                      7 ;     the Free Software Foundation, either version 3 of the License, or
                                      8 ;     (at your option) any later version.
                                      9 ;
                                     10 ;     MONA is distributed in the hope that it will be useful,
                                     11 ;     but WITHOUT ANY WARRANTY; without even the implied warranty of
                                     12 ;     MERCHANTABILITY or FITNESS FOR A PARTICULAR PURPOSE.  See the
                                     13 ;     GNU General Public License for more details.
                                     14 ;
                                     15 ;     You should have received a copy of the GNU General Public License
                                     16 ;     along with MONA.  If not, see <http://www.gnu.org/licenses/>.
                                     17 ;;
                                     18 ;;;;;;;;;;;;;;;;;;;;;;;;;;;;;;;;;;;
                                     19 ; 2022/11/14
                                     20 ; STM8S207K8 µC registers map
                                     21 ; sdas source file
                                     22 ; author: Jacques Deschênes, copyright 2018,2019,2022
                                     23 ; licence: GPLv3
                                     24 ;;;;;;;;;;;;;;;;;;;;;;;;;;;;;;;;;;;;
                                     25 
                                     26 ;;;;;;;;;;;
                                     27 ; bits
                                     28 ;;;;;;;;;;;;
                           000000    29  BIT0 = 0
                           000001    30  BIT1 = 1
                           000002    31  BIT2 = 2
                           000003    32  BIT3 = 3
                           000004    33  BIT4 = 4
                           000005    34  BIT5 = 5
                           000006    35  BIT6 = 6
                           000007    36  BIT7 = 7
                                     37  	
                                     38 ;;;;;;;;;;;;
                                     39 ; bits masks
                                     40 ;;;;;;;;;;;;
                           000001    41  B0_MASK = (1<<0)
                           000002    42  B1_MASK = (1<<1)
                           000004    43  B2_MASK = (1<<2)
                           000008    44  B3_MASK = (1<<3)
                           000010    45  B4_MASK = (1<<4)
                           000020    46  B5_MASK = (1<<5)
                           000040    47  B6_MASK = (1<<6)
                           000080    48  B7_MASK = (1<<7)
                                     49 
                                     50 ; HSI oscillator frequency 16Mhz
                           F42400    51  FHSI = 16000000
                                     52 ; LSI oscillator frequency 128Khz
                           01F400    53  FLSI = 128000 
                                     54 

ASxxxx Assembler V02.00 + NoICE + SDCC mods  (STMicroelectronics STM8), page 4.
Hexadecimal [24-Bits]

                                     55 ; controller memory regions
                           001800    56  RAM_SIZE = (0x1800) ; 6KB 
                           000400    57  EEPROM_SIZE = (0x400) ; 1KB
                                     58 ; STM8S207K8 have 64K flash
                           010000    59  FLASH_SIZE = (0x10000)
                                     60 ; erase block size 
                           000080    61 BLOCK_SIZE=128 ; bytes 
                                     62 
                           000000    63  RAM_BASE = (0)
                           0017FF    64  RAM_END = (RAM_BASE+RAM_SIZE-1)
                           004000    65  EEPROM_BASE = (0x4000)
                           0043FF    66  EEPROM_END = (EEPROM_BASE+EEPROM_SIZE-1)
                           005000    67  SFR_BASE = (0x5000)
                           0057FF    68  SFR_END = (0x57FF)
                           006000    69  BOOT_ROM_BASE = (0x6000)
                           007FFF    70  BOOT_ROM_END = (0x7fff)
                           008000    71  FLASH_BASE = (0x8000)
                           017FFF    72  FLASH_END = (FLASH_BASE+FLASH_SIZE-1)
                           004800    73  OPTION_BASE = (0x4800)
                           000080    74  OPTION_SIZE = (0x80)
                           00487F    75  OPTION_END = (OPTION_BASE+OPTION_SIZE-1)
                           0048CD    76  DEVID_BASE = (0x48CD)
                           0048D8    77  DEVID_END = (0x48D8)
                           007F00    78  DEBUG_BASE = (0X7F00)
                           007FFF    79  DEBUG_END = (0X7FFF)
                                     80 
                                     81 ; options bytes
                                     82 ; this one can be programmed only from SWIM  (ICP)
                           004800    83  OPT0  = (0x4800)
                                     84 ; these can be programmed at runtime (IAP)
                           004801    85  OPT1  = (0x4801)
                           004802    86  NOPT1  = (0x4802)
                           004803    87  OPT2  = (0x4803)
                           004804    88  NOPT2  = (0x4804)
                           004805    89  OPT3  = (0x4805)
                           004806    90  NOPT3  = (0x4806)
                           004807    91  OPT4  = (0x4807)
                           004808    92  NOPT4  = (0x4808)
                           004809    93  OPT5  = (0x4809)
                           00480A    94  NOPT5  = (0x480A)
                           00480B    95  OPT6  = (0x480B)
                           00480C    96  NOPT6 = (0x480C)
                           00480D    97  OPT7 = (0x480D)
                           00480E    98  NOPT7 = (0x480E)
                           00487E    99  OPTBL  = (0x487E)
                           00487F   100  NOPTBL  = (0x487F)
                                    101 ; option registers usage
                                    102 ; read out protection, value 0xAA enable ROP
                           004800   103  ROP = OPT0  
                                    104 ; user boot code, {0..0x3e} 512 bytes row
                           004801   105  UBC = OPT1
                           004802   106  NUBC = NOPT1
                                    107 ; alternate function register
                           004803   108  AFR = OPT2
                           004804   109  NAFR = NOPT2

ASxxxx Assembler V02.00 + NoICE + SDCC mods  (STMicroelectronics STM8), page 5.
Hexadecimal [24-Bits]

                                    110 ; miscelinous options
                           004805   111  WDGOPT = OPT3
                           004806   112  NWDGOPT = NOPT3
                                    113 ; clock options
                           004807   114  CLKOPT = OPT4
                           004808   115  NCLKOPT = NOPT4
                                    116 ; HSE clock startup delay
                           004809   117  HSECNT = OPT5
                           00480A   118  NHSECNT = NOPT5
                                    119 ; flash wait state
                           00480D   120 FLASH_WS = OPT7
                           00480E   121 NFLASH_WS = NOPT7
                                    122 
                                    123 ; watchdog options bits
                           000003   124   WDGOPT_LSIEN   =  BIT3
                           000002   125   WDGOPT_IWDG_HW =  BIT2
                           000001   126   WDGOPT_WWDG_HW =  BIT1
                           000000   127   WDGOPT_WWDG_HALT = BIT0
                                    128 ; NWDGOPT bits
                           FFFFFFFC   129   NWDGOPT_LSIEN    = ~BIT3
                           FFFFFFFD   130   NWDGOPT_IWDG_HW  = ~BIT2
                           FFFFFFFE   131   NWDGOPT_WWDG_HW  = ~BIT1
                           FFFFFFFF   132   NWDGOPT_WWDG_HALT = ~BIT0
                                    133 
                                    134 ; CLKOPT bits
                           000003   135  CLKOPT_EXT_CLK  = BIT3
                           000002   136  CLKOPT_CKAWUSEL = BIT2
                           000001   137  CLKOPT_PRS_C1   = BIT1
                           000000   138  CLKOPT_PRS_C0   = BIT0
                                    139 
                                    140 ; AFR option, remapable functions
                           000007   141  AFR7_BEEP    = BIT7
                           000006   142  AFR6_I2C     = BIT6
                           000005   143  AFR5_TIM1    = BIT5
                           000004   144  AFR4_TIM1    = BIT4
                           000003   145  AFR3_TIM1    = BIT3
                           000002   146  AFR2_CCO     = BIT2
                           000001   147  AFR1_TIM2    = BIT1
                           000000   148  AFR0_ADC     = BIT0
                                    149 
                                    150 ; device ID = (read only)
                           0048CD   151  DEVID_XL  = (0x48CD)
                           0048CE   152  DEVID_XH  = (0x48CE)
                           0048CF   153  DEVID_YL  = (0x48CF)
                           0048D0   154  DEVID_YH  = (0x48D0)
                           0048D1   155  DEVID_WAF  = (0x48D1)
                           0048D2   156  DEVID_LOT0  = (0x48D2)
                           0048D3   157  DEVID_LOT1  = (0x48D3)
                           0048D4   158  DEVID_LOT2  = (0x48D4)
                           0048D5   159  DEVID_LOT3  = (0x48D5)
                           0048D6   160  DEVID_LOT4  = (0x48D6)
                           0048D7   161  DEVID_LOT5  = (0x48D7)
                           0048D8   162  DEVID_LOT6  = (0x48D8)
                                    163 
                                    164 

ASxxxx Assembler V02.00 + NoICE + SDCC mods  (STMicroelectronics STM8), page 6.
Hexadecimal [24-Bits]

                           005000   165 GPIO_BASE = (0x5000)
                           000005   166 GPIO_SIZE = (5)
                                    167 ; PORTS SFR OFFSET
                           000000   168 PA = 0
                           000005   169 PB = 5
                           00000A   170 PC = 10
                           00000F   171 PD = 15
                           000014   172 PE = 20
                           000019   173 PF = 25
                           00001E   174 PG = 30
                           000023   175 PH = 35 
                           000028   176 PI = 40 
                                    177 
                                    178 ; GPIO
                                    179 ; gpio register offset to base
                           000000   180  GPIO_ODR = 0
                           000001   181  GPIO_IDR = 1
                           000002   182  GPIO_DDR = 2
                           000003   183  GPIO_CR1 = 3
                           000004   184  GPIO_CR2 = 4
                           005000   185  GPIO_BASE=(0X5000)
                                    186  
                                    187 ; port A
                           005000   188  PA_BASE = (0X5000)
                           005000   189  PA_ODR  = (0x5000)
                           005001   190  PA_IDR  = (0x5001)
                           005002   191  PA_DDR  = (0x5002)
                           005003   192  PA_CR1  = (0x5003)
                           005004   193  PA_CR2  = (0x5004)
                                    194 ; port B
                           005005   195  PB_BASE = (0X5005)
                           005005   196  PB_ODR  = (0x5005)
                           005006   197  PB_IDR  = (0x5006)
                           005007   198  PB_DDR  = (0x5007)
                           005008   199  PB_CR1  = (0x5008)
                           005009   200  PB_CR2  = (0x5009)
                                    201 ; port C
                           00500A   202  PC_BASE = (0X500A)
                           00500A   203  PC_ODR  = (0x500A)
                           00500B   204  PC_IDR  = (0x500B)
                           00500C   205  PC_DDR  = (0x500C)
                           00500D   206  PC_CR1  = (0x500D)
                           00500E   207  PC_CR2  = (0x500E)
                                    208 ; port D
                           00500F   209  PD_BASE = (0X500F)
                           00500F   210  PD_ODR  = (0x500F)
                           005010   211  PD_IDR  = (0x5010)
                           005011   212  PD_DDR  = (0x5011)
                           005012   213  PD_CR1  = (0x5012)
                           005013   214  PD_CR2  = (0x5013)
                                    215 ; port E
                           005014   216  PE_BASE = (0X5014)
                           005014   217  PE_ODR  = (0x5014)
                           005015   218  PE_IDR  = (0x5015)
                           005016   219  PE_DDR  = (0x5016)

ASxxxx Assembler V02.00 + NoICE + SDCC mods  (STMicroelectronics STM8), page 7.
Hexadecimal [24-Bits]

                           005017   220  PE_CR1  = (0x5017)
                           005018   221  PE_CR2  = (0x5018)
                                    222 ; port F
                           005019   223  PF_BASE = (0X5019)
                           005019   224  PF_ODR  = (0x5019)
                           00501A   225  PF_IDR  = (0x501A)
                           00501B   226  PF_DDR  = (0x501B)
                           00501C   227  PF_CR1  = (0x501C)
                           00501D   228  PF_CR2  = (0x501D)
                                    229 ; port G
                           00501E   230  PG_BASE = (0X501E)
                           00501E   231  PG_ODR  = (0x501E)
                           00501F   232  PG_IDR  = (0x501F)
                           005020   233  PG_DDR  = (0x5020)
                           005021   234  PG_CR1  = (0x5021)
                           005022   235  PG_CR2  = (0x5022)
                                    236 ; port H not present on LQFP48/LQFP64 package
                           005023   237  PH_BASE = (0X5023)
                           005023   238  PH_ODR  = (0x5023)
                           005024   239  PH_IDR  = (0x5024)
                           005025   240  PH_DDR  = (0x5025)
                           005026   241  PH_CR1  = (0x5026)
                           005027   242  PH_CR2  = (0x5027)
                                    243 ; port I ; only bit 0 on LQFP64 package, not present on LQFP48
                           005028   244  PI_BASE = (0X5028)
                           005028   245  PI_ODR  = (0x5028)
                           005029   246  PI_IDR  = (0x5029)
                           00502A   247  PI_DDR  = (0x502a)
                           00502B   248  PI_CR1  = (0x502b)
                           00502C   249  PI_CR2  = (0x502c)
                                    250 
                                    251 ; input modes CR1
                           000000   252  INPUT_FLOAT = (0) ; no pullup resistor
                           000001   253  INPUT_PULLUP = (1)
                                    254 ; output mode CR1
                           000000   255  OUTPUT_OD = (0) ; open drain
                           000001   256  OUTPUT_PP = (1) ; push pull
                                    257 ; input modes CR2
                           000000   258  INPUT_DI = (0)
                           000001   259  INPUT_EI = (1)
                                    260 ; output speed CR2
                           000000   261  OUTPUT_SLOW = (0)
                           000001   262  OUTPUT_FAST = (1)
                                    263 
                                    264 
                                    265 ; Flash memory
                           000080   266  BLOCK_SIZE=128 
                           00505A   267  FLASH_CR1  = (0x505A)
                           00505B   268  FLASH_CR2  = (0x505B)
                           00505C   269  FLASH_NCR2  = (0x505C)
                           00505D   270  FLASH_FPR  = (0x505D)
                           00505E   271  FLASH_NFPR  = (0x505E)
                           00505F   272  FLASH_IAPSR  = (0x505F)
                           005062   273  FLASH_PUKR  = (0x5062)
                           005064   274  FLASH_DUKR  = (0x5064)

ASxxxx Assembler V02.00 + NoICE + SDCC mods  (STMicroelectronics STM8), page 8.
Hexadecimal [24-Bits]
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

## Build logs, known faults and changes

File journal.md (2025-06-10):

<!-- 
Copyright Jacques Deschênes, 2025
Ce document fait parti du projet pomme-1P
https://github.com/picatout/pomme-1P
-->

### 2025-06-10 

* Modification de **LOAD_RANGE** et **STORE_RANGE** pour accepter plusieurs page de 256 octets.

* Modification de la commande **ZERO_FILL** du moniteur pour permettre l'opération dans l'EEPROM U13.

* Modification au circuit pour enlevé le polling sur pin **1** de l'EEPROM **U13** puisque ça ne fonctionne pas correctement. 

* **MON_V1.3R2** Modifié la boucle d'attente de fin de programmation de **EEWRITE**. La méthode utilisant la broche **1** de l'EEPROM ne fonctionne pas bien. La nouvelle routine utilise la comparaison de du contenu de l'EEPROM avec l'octet écrit. 

* Modifié fonction **MOVE** du moniteur pour que l'opération s'applique aussi à l'EEPROM U13. MON_V1.3R1 

* Modification de la circuit de l'ordinateur pomme-1+. Cette EEPROM peut-être programmée directement dans le circuit de l'ordinateur.
  * Ajout d'une EEPROM AT28BV64 dans le socket **U13**.
  * Utilisation du bit PB1 du VIA pour activer le **WRITE_ENABLE** de **U13**
  * Utilisation du bit PB2 du VIA pour lire l'état de la pin **1** de **U13** qui est a **0** lorsqu'une programmation est en cours.
* BIOS version 1.0R1
* p1+Monitor version 1.3R0.

### 2025-06-07 

* Travail sur [math16.s](BIOS/math16.s)

### 2025-06-06 

* Création de [math16.s](BIOS/math16.s)

* Ajout des routines **PRT_INT** et **UDIV16** dans [bios.s](BIOS/bios.s).

### 2025-05-23

* Modifié routinte **RESET** pour mettre à zéro les 2 piles.

### 2025-05-22

* débuter travail sur [forth.s](BIOS/forth.s).

* Création de macros qui prennent avantage des instructions du W65C02. Modification du code pour utiliser les macros.
  * BBRx, branch bit reset 
  * BBSx, branch bit set 
  * RMBx, reset memory bit 
  * SMBx, set memory bit  

### 2025-05-21

* Corrigé erreur dans la schématique de la carte ssd et son.

### 2025-05-20 

* Paufiner le code du Moniteur. 
* Ajout au manuel [p1+Monitor.pdf](docs/p1+Monitor.pdf).

### 2025-05-19 

* Test mise à jour p1+Monitor.s 

* Ajout de fonctions à p1+Monitor.s 
  * range'M'dest   copie la plage mémoire *range* vers *dest*. 
  * range'V'dest   compare la page mémoire *range* à la plage débutant à *dest* et affiche les différences.
  * range'Z'   met à zéro la plage *range*.

* Création du manuel du [p1+Monitor](docs/p1+Monitor.pdf).

### 2025-05-15

* Travail sur le moniteur
  * Modifié **STORE_RANGE** et **LOAD_RANGE** pour étendre ces opération à une plage de plus de 256 octets.

### 2025-05-12

* Tavail sur le moniteur Version 1.1R0.

### 2025-05-07

* Changement d'organisation du firware BIOS 
   * création d'une pile des paramètres à l'adresse $C0..$FF 
   * Utilisation du registre **X** comme pointeur pour la pile des paramètres.
   * __Tout le code doit-être modifié pour tenir compte de cette modification.__
   * Ajout du fichier [stack.s](stack.s).
   * Le BIOS va fonctionné comme une machine FORTH. Le modèle d'exécution sera **direct threaded.**

### 2025-05-06 

* Travail sur BIOS 
  * Modifié l'utilisation des minuterie du **VIA** (W65C22).
    * TIMER1 utilisé comme générateur d'onde carré pour la fonction **TONE** du BIOS 
    * TIMER2 utilisé pour une interruption au milliseconde 
  * Ajout de la fonction BIOS **TONE**  

* Modification de la schématique, carte SSD + SON ajouté.

### 2025-05-03

* Poursuite du travail sur [p1+Monitor.s](BIOS/p1+Monitor.s).
  * Réussie à déboguer le moniteur 
* Ajout des commandes suivantes au moniteur:
  *	ADR'R'&lt;CR&gt;  run application at ADR 
  *	SECT#'X'&lt;CR&gt;  erase W25Q080 SECTOR# 
  *	'*'&lt;CR&gt;  erase W25Q080 chip  
  * ADR'!'PAGE&lt;CR&gt; store 256 memory bytes in W25Q080 flash memory 
  * ADR'@'PAGE&lt;CR&gt; load 256 bytes from W25Q080 to memory 
  *'Q'&lt;CR&gt; quit monitor 

### 2025-05-02

* Travail sur BIOS.
  * Tester **ENABLE_WRITE** et **FLASH_READ_STATUS**
  * Les problèmes avec la lecteur/écriture de la mémoire FLASH semblent réglés. j'avais une mauvaise compréhension des instruction d'indirection du MPU 6502.
  * Restauration du p1+Monitor 
  * Déplacer le p1+Monitor à l'adresse 0xFE00  car sa taille va augmenté par ajout de fonctionnalités.
    * ADR@PAGE  ssd page load at ADR  
    * ADR!PAGE  ssd store data at page 
    * SECTORX  erase ssd sector
    *  '*'  erasee chip  
    * Quoted string accepted as data to store functions. 

### 2025-05-01

* Travail sur BIOS.
  * Corrigé bogue matériel pin 32 du socket du VIA était mal soudée. 
  * Maintenant il est possible de lire le DEVICE ID correctement.
  * Fonction ERASE_ALL ne fonctionne pas. 
  * Fonction FLASH_WRITE ne fonctionne pas.
  * La fonction FLASH_READ semble fonctionner. À vérifier.

### 2025-04-30

* Travail sur le BIOS. Problème avec l'interface de la mémoire FLASH. 

### 2025-04-29

* Travail sur le BIOS. 
  * Ajout de **RAND** et **RANDOMIZE**. 

### 2025-04-28 

* Travail sur le BIOS.  Écriture des fonctions d'accès à la mémoire FLASH W25Q080.

### 2025-04-27

* Problème avec le W65C22S réglé, l'erreur était dans la conception matérielle. Les entrées **RWB** des W65C22S et W65C51S doivent-être alimentées directement par le signal **RWB** du MPU et on celui à la pin 8 de U3. 

* Repris le travail sur le BIOS.

### 2025-04-26

* Travail sur [bios](BIOS/bios.s). Le W65C22 ne fonctionne pas tous les signaux CS1,CS2B,PHI2 et R/WB  sont correct mais l'écriture des registres ne semble pas s'effectuer.

### 2025-04-25

* Travail sur [bios](BIOS/bios.s).

### 2025-04-24

* Corrigé erreur dans schématique du circuit de la mémoire FLASH W25Q080DV.

* Changement de direction, pour le moment j'ai abandonné le sous-projet **p1+_drive** pour fabriquer une carte contenant seulement la mémoire flash **W25Q080DV** de 1MO et qui et branchée directement sur un connecteur relié au PIA **W65C22**. Donc tous le firmware pour le stockage des programmes dans la mémoire flash cera programmé dans le BIOS du **pomme 1+.** 

carte mémoire flash. 

### 2025-04-09 

* Travail sur p1+_drive:
  * spi.asm complété. 
  * À faire drive_cmd.asm 

### 2025-03-19

* Modification du design 
  * Ajout d'un PIA **W65C22**  au peripheral board.
  * Modification de l'alimentation pour ajouter un régulateur de tension 3.3V.
  * Complété l'assemblage de la modification

  montage révison 2
  
### 2025-03-18

* Modification du circuit du p1+_drive qui fonctionnera entièrment sur 3.3V au lieu de 5V.

* Montage partiel du p1+_drive sur carte sans soudure pour début programmation.

### 2025-03-16

* Corrigé schématique de p1+_drive, régulateur de tension 3.3V et adapteurs de niveaux ajoutés pour interfacé carte SD. 

* Remplacé le p1+_drive par un nouveau circuit utilisant un STM8S207K8T et une carte µSD pour le stockage des programmes.

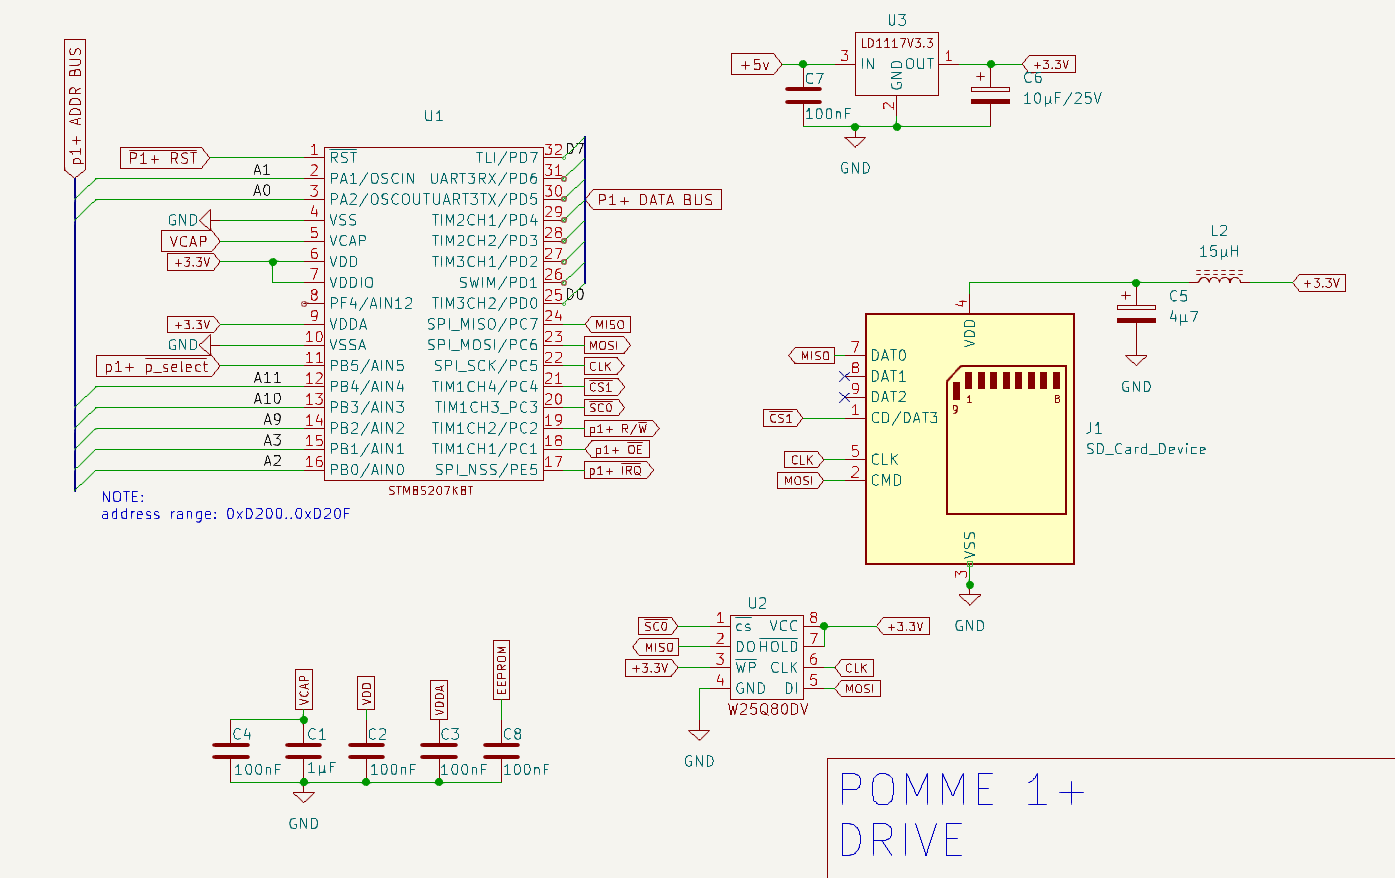
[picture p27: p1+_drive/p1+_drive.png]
p1+ drive


* Modifié schématique du p1+_terminal. Ajout d'un transistor 2n3904 à la sortie TX pour permettre le partage de l'entrée ACIA_RX par plusieurs périphériques. Simulation d'un bus Open drain. 

p1+_terminal

### 2025-03-15

* J'ai pris la décision d'utiliser le même terminal que pour le pomme I avec quelques modifications.
  * la vitesse BAUD sera fixée à 115200
  * Les switches qui servaient à sélectionner le BAUD serviront à sélectionner un indentifiant de périphérique {0..3}.
  * Le terminal et le drive seront montés sur la même carte et utiliseront le même port sériel pour communiquer avec l'ACIA d'ou le besoin d'avoir un identifiant différent pour chacun d'eux. Les firmware du drive et du terminal ne répondront qu'aux messages identifiés par leur identifiant respectifs.
<hr>

* Travail sur la schématique et le firmware du **p1+_terminal**.

* Travail sur la schématique du **p1+_drive**.

### 2025-03-13

* Création du sous projet [p1+_drive](p1+_drive). 

### 2025-03-12

* Début du travails sur p1+_Terminal. Adaptation du [stm8_terminal](https://github.com/Picatout/stm8_terminal).

### 2025-03-11

* Complété schématique alimentation.

*Création d'une vidéo de présenstation du projet.

### 2025-03-08

* Moniteur V1.0R0 débogué et fonctionnel.

* Déboguer le moniteur 

### 2025-03-07

* Adaptation du moniteur WOZMON à l'ordinateur **pomme-1+**

* Ajout du fichier [docs/montage-pomme-1+.jpg](docs/montage-pomme-1+.jpg).

### 2025-02-13

* Début du projet **pomme-1P** construction d'un ordinateur simple basé sur le MPU W65C02S de [Western Design Center](https://www.westerndesigncenter.com/).

#### 2021-03-24

* Travail sur la documentation. 
  * Complété [manuel_util_tb.md](docs/manuel_util_tb.md)
  * Complété [user-manual.md](docs/user-manual.md)

* Ajout de la commande **DSTACK** et mise à jour des manuels de références français et anglais. 

#### 2021-03-23

* Ajouter support pour les interruptions écrite en BASIC. Annuler le transfert de la table des vecteurs au début de la RAM. À la place réserve 60*4 octets pour les adresses IRQ BASIC.

* Ajout de *nvic_enable_irq* et *nvic_disable_iqr* dans [stm32-tbi.s](stm32-tbi.s).

* Ajout de file de réception de 4 octets pour UART2|3. 

#### 2021-03-22

* Corrigé bogue dans [cmd_index.inc](command_index.inc).

#### 2021-03-21

* Mise à jour documentation [tbi_reference.md](docs/tbi_reference.md) et [refman.md](docs/refman.md).

* Mots ajoutés:  **UART_GETC**, **UART_INIT** et **UART_PUTC**. 

* Ajout support UART2 et UART3. 

* Modifié **WORDS** pour réduire la limite avant le retour à la ligne a 70 au lieu de 80. 

* Renommé programme pwm_soft.bas en [pwm-soft.bas](tb_progs/pwm-soft.bas) et modifié code. Maintenant commandes insensible à la casse. 

#### 2021-03-20
* Optimisation: Le compte des arguments est maintenant vérifié dans arg_list 
  plutôt que dans chaque commande ou fonction BASIC.

* Complété [refman.md](docs/refman.md).
#### 2021-03-19

* Modifié **PUT** pour inverser l'ordre des arguments, maintenant **PUT slot,value**.

* Modifié **GET** pour remplacer le **mul** par un **lsl**. 

* Travail sur [refman.md](docs/refman.md).

#### 2021-03-18

* Ajout de la commande **RANDOMIZE** et de sa docmentation. 

* Ajout de la documentation pour les commandes **SPI_xxx** dans [tbi_reference.md](tbi_reference.md).

* Réécriture de [spi-test.bas](tb_progs/spi-test.bas).

* Complété et testé les commandes du groupes **SPI_xxx**. 

* Added constants for GPIO modes in [stm32f103.inc](stm32f103.inc). 

#### 2021-03-17

* Travail sur commande **SPI_xxxx**. 

* Travail sur [refman.md](docs/refman.md) 

* Modifié **LOAD*** et *create_gap* qui ne mettait pas à jour la variable **HERE**.

#### 2021-03-16

* Travail sur [refman.md](docs/refman.md).

* Le mode GPIO pour les servo-moteur est maintenant **OUTPUT_AFOD** et requiert donc un résistance pull up externe branché à 5 volts. Ce changement est pour tenir compte de la différence de voltage d'alimentation entre MCU de la blue pill (3.3volts) et celui d'un petit servo-moteur qui est de 5 volts. 

* Modifié [servo-test.bas](tb_progs/servo-test.bas) pour tenir compte des 2 nouveaux canneaux. 

* Ajout des canneaux servo-moteurs 5 et 6. Modifié code et tester code. Note les canaux 5 et 6 ne peuvent-être utilisé en même temps que *TONE** est activé.  

#### 2021-03-15

* Création de **pwm_dc**.

* Création de la sous-routine **pwm_config**, facteur commun a **SERVO_INIT** et **TONE_INIT**.

* Corrigé bogue dans commande **AWU**.

* Travail sur [refman.md](docs/refman.md)

#### 2021-03-14

* Complété le manuel de référence.

#### 2021-03-13

* Travail sur le manuel de référence.

* Modifié fonction **RANDOM** pour refuser les entiers négatif.

#### 2021-03-12

* Travail sur manuel de référence.

* Corrigé bogue dand **readln**.

* Modification à la commande **AWU** contrôle de limite. 

* Modification à **ADC** pour ajouter délais après activation et calibration.

#### 2021-03-11

* Modifié *prt_chars* pour que les caractères ASCII>126 s'affiche comme un **'_'**. 

* Écris et testé commande  **AUTORUN**.

#### 2021-03-09

* Travail sur manuel de référence. 

* Corrigé bogue dans **term**. 

#### 2021-03-07

* Corrigé bogue dans **gpio_config**. 

* Ajout de **SERVO_OFF** pour désactiver un canal servo-moteur.

* Supprimer constantes **SERVO_x** maintenant **SERVO_INIT** et **SERVO_POS** prennent pour argument entiers {1..4}.

* Supprimer les constantes **ON** et **OFF**  maintenant les arguments {1|0} doivent-être utilisés.

#### 2021-03-06

* Modifié **SERVO_INIT** la configuration du GPIO utilisé est maintenant faite par cette commande.

* Ajout des mots **TONE_INIT**, **TONE**.

* Modifié **uart_init** pour ajouter verouillage de broches PA9,PA10.

#### 2021-03-05

* Corrigé erreur erronées pour les constantes système **OUTPUT_AFPP** et **OUTPUT_AFOD**.

* Ajout du programme [servo-tes.bas](tb_progs/servo-test.bas).

* Testé **SERVO_INIT** et **SERVO_POS**.

* Ajout du programme [gpio-tes.bas](tb_progs/gpio-test.bas)

* Désactivation de signaux **JTDI,JTDO,JTRST** qui empêchaient l'utilisation des **GPIOA:15,GPIOB:3,GPIOB:4**.

#### 2021-03-04

* Ajout des constantes système **SERVO_A**, **SERVO_B**, **SERVO_C** et **SERVO_D**.

* Ajout des mots **SERVO_INIT** et **SERVO_POS**. 

#### 2021-03-03

* Corrigé bogue dans fonction **READ** qui n'acceptait pas les entiers négatifs. 

* Supprimer la commande **DATALN** et remplacé par un argument de la commande **RESTORE**.

* Ajout des mots **ADC**,**ANA** 

* Ajout des constantes système: **ON**,**OFF**

* Ajout du programme [pmode-test.bas](tb_progs/pmode-test.bas).

#### 2021-03-02

* Corrigé bogue dans **decompile_line**,  lable were not decompressed properly. 

* Now accept underscore in label and keywords. 

* Ajout des constantes système **OUTPUT_OD**,**OUTPUT_PP**,**OUTPUT_AFOD**,**OUTPUT_AFPP**,**INPUT_FLOT**,**INPUT_PD**,**INPUT_PU** et **INPUT_ANA**

#### 2021-03-01

* Modifié **INPUT** pour accepter les entiers négatifs. 

* Modifié **ASC()** pour accepter les **TK_CFUNC** comme argument. 

* Modifié le type de la fonction **KEY** dans le dictionnaire de **TK_INTGR**  à **TK_CHAR**.

* Corrigé bogue dans **next_token** qui ne retournait pas **TK_QSTR** dans r0.

* Retravaillé  **relation** et **expression** ainsi que code dépendant. 

#### 2021-02-28

* Modifié **décompile_line** pour insérer espace après variable et fonction.

* Optimisé **next_token**. 

* Trouver bogue dans **decompile_line** qui m'a obligé à créer **TK_SCONST** pour distinguer les constantes système de celles-créées par l'utilisateur. Ajustement de code nécessaire.

* Création branche **interpreter** pour travaillé la performance de l'interpréteur.  

* Corrigé bogue dans **readln**  la commande **CTRL_E** ne fonctionnait plus, c'était un bogue régressif. 

#### 2021-02-27

* Débogué **DUMP**,  la pile était débalancée lorsque l'entrée se faisait au point **dump01**. 

* Ajout de **XPOS** et **YPOS** pour connaître la position actuelle du curseur à l'écran du terminal. 

* Renommé **SIZE** en **FREE** 

* Déboguage **relation**, **decompile_line**, **comp_token**. 

#### 2021-02-26

* Modification identifiants tokens et tout le code impliqué. 
* Modififié **GOSUB** et **RETURN** maintenant sauvegarde adresse retour sur pile principale au lieu de la pile des arguments. 
```
list
10  INPUT A,B
20  PUSH A,B GOSUB PROD
30  PRINT  POP
40  GOTO 10 
50 PROD PUSH  POP* POP  RETURN 
READY
RUN
A=23
B=67
1541 
A=
READY
```

* Débogué **readln**  **CTRL_R** ne fonctionnait plus. 

* Renommé les mots suivants: **PEEK8** en **PEEKB**, **PEEK16** en **PEEKH**  et **PEEK32** en **PEEKW**

* Renommé les mots suivants: **POKE8** en **POKEB**, **POKE16** en **POKEH** et **POKE32** en **POKEW** 

* Renommé le mot **FLASH** en **STORE** 

* Modifié **pasre_label**  le compilateur convertie les symboles qui représente des constantes dans le dictionaire comme des **TK_INTGER** maintenant. Exécution plus rapide.

#### 2021-02-25

* Ajout de **GPIOA**,**GPIOB**,**GPIOC**

* Renommé **INP** à **IN** 

* Ajout de **CLS** et **LOCATE** 

* Racourci **REMARK** à **REM**.

* Renommé  **PICK** **GET** et **STORE** **PUT** 

* nettoyage du code. 

* correction bogue dans **decompile_line**. 

* changer limite no de ligne pour 65535.

#### 2021-02-24

* exemple utiliation du mot **CONST** 
```
LIST
10  CONST CA=2 *3 ,CB=2 *CA
20  ? CA,CB
30  END 
READY
RUN
6 12 
READY
```

* exemple utilisant les mots de gestion de la pile des arguments ainsi que les étiquettes. 
```
list
10  FOR I=1  TO 10  PUSH I GOSUB SQUARE ?  POP , NEXT I
20  END 
30 SQUARE PUT  GET (2 )* GET (2 ),2  RETURN 
READY
run
1 4 9 16 25 36 49 64 81 100 
READY
```

* **TK_LBL**  Les étiquettes cibles pour les **GOTO** et **GOSUB** débute par le caractère **!** suivit d'un maximum de 6 lettres.

* Ajout de **CONST** et d'étiquettes cibles.

#### 2021-02-23

* Ajout de la variable système **HERE** dans le but d'ajouter le mot BASIC **CONST**. Le système va permettre de créer des constantes symboliques dans l'espace libre après le code BASIC.

* Ajout des mots BASIC **PUSH**,**POP**,**PICK**,**STORE** et **DROP**. 

```
a=ticks:for i=0 to 100000: next i:? ticks-a
433 

```

* Ajout des mots **FLASH** et **ERASE** 

#### 2021-02-22

* Modifié **uart_rx_handler** pour pour que **CTRL_B** branche directement sur **warm_start** à la sortie de l'isr.

#### 2021-02-20

* Ajout des commandes **DIR** et **LOAD** 

#### 2021-02-19

* Ajout de **SAVE** et **FORGET** 

* Corrigé bogue dans **readln** 

* Ajouté constantes pour **IWDG** et **WWDG** dans [stm32f103.inc](stm32f103.inc)

#### 2021-02-18

* Débogué **GOTO**, la variable **COUNT** n'était pas initialisée. 

* Remplacé **SHOW** par **TRACE** 

* Ajout des commandes **TAB** et **SPC** 

#### 2021-02-17

* Ajout de **SHOW** 

* Modifié **tb_error** maintenant rt_error affiche ligne décompilée. 

#### 2021-02-16

* Débuté travail sur **PMODE** 

* Modifié **PRINT** pour accepté le **;** comme séprateur de liste. Ce caractère sera utilisé pour engendré une tabulation. 

* Modifié **INPUT** pour accepter une lettre comme réponse. La lettre est convertie en majuscule et la valeur ASCII affectée à la variable.

#### 2021-02-15

* Ajout de **WAIT** ,**DREAD**,**DWRITE**,**OUT**,**INP** 

#### 2021-02-14

* Ajout de **SLEEP** et **STOP**, supprimer **BYE**
 
* Ajouter **KEY**, **RSHIFT**, **LSHIFT**,**PEEK8**,**PEEK16**,**PEEK32**,**POKE8**,**POKE16**,**POKE32**  

* Modifié **INPUT** pour afficher soit la chaîne, soit le nom de la variable mais pas les 2.

* Modifier readln, home ne doit pas retourner à gauche de l'écran mais au début de la ligne de texte qui ne débute pas forcément à la colonne 1.

#### 2021-02-13

* Ajout de **INPUT** et **INVERT**

* Améliorer **DUMP** ainsi que l'affichage des erreurs run time.

* Ajout de **CTRL_B** dans le gestionnaire **uart_rx_handler** pour stopper un programme bloqué dans une boucle indéfinie.

* Déboguer **decompile_line** et **readln**. 

#### 2021-02-12

* créer routine decompile reste à déboguer.

* Corrigé bogue dans **readln** 

* Ajout de **THEN**, **BIT** , **DO** , **UNTIL**

* Ajout de **CHAR** 

* Améliorer commmande **DUMP** pour aligner la colonne des octetes à la position 11.

* Améliorer **PRINT** pour tenir compte de la largeur des colonnes **TAB_WIDTH**.

#### 2021-02-11

* Ajout des fonctions BASIC **AND**,**OR**,**XOR**,**ASC** 

* Déboguer commande **PRINT** qui ne fesait le CR lorsque le dernier argument éait une expression.

* Ajout des mots BASIC  **DATA**,**DATALN**,**READ** et **RESTORE**.

* Déboguer fonctions d'éditions, **inster_line**, **create_gap**, **delete_line** 

* Corrigé **compile** qui ne traitait pas les commentaires correctement.

* Corrigé commande **LIST** qui n'affichait pas les commentaires.

#### 2021-02-10

* Déboguer **next_token** et **interpreter**.

* Écris et testé mots BASIC **TICKS**,**TIMER**,**TIMEOUT**,**PAUSE**,**NOT**

* Écris et testé mots BASIC **FOR**,**TO**,**STEP** et **NEXT**. 

* Écris et testé mots BASIC **GOSUB** et **RETURN**.

* Ajout de la commande BASIC **NEW**.

* Travail sur commande BASIC **LIST**. 

#### 2021-02-09

* Corrigé bogue dans **is_digit** 

* Modifié **next_token** et **interpreter**

#### 2021-02-08

* Tester et déboguer **relation**

* Écrire code pour commande **IF**. 

* Ajouter **DUMP** au vocabulaire BASIC 

* Compléter et tester commande **LET**.

#### 2021-02-05

* Modification de *parse_keyword* pour accepter les variables.
* Déboguer *expression* et *search_dict*
**À faire** 
* déboguer @(expr)

#### 2021-02-04

* Corrigé bogue dans *is_special* qui retournait la mauvaise la valeur.
* Corrigé bogue dans *skip* ne préservait pas **r1** et avancait **r3** avant vérification.
* Écriture de la commande BASIC **PRINT**

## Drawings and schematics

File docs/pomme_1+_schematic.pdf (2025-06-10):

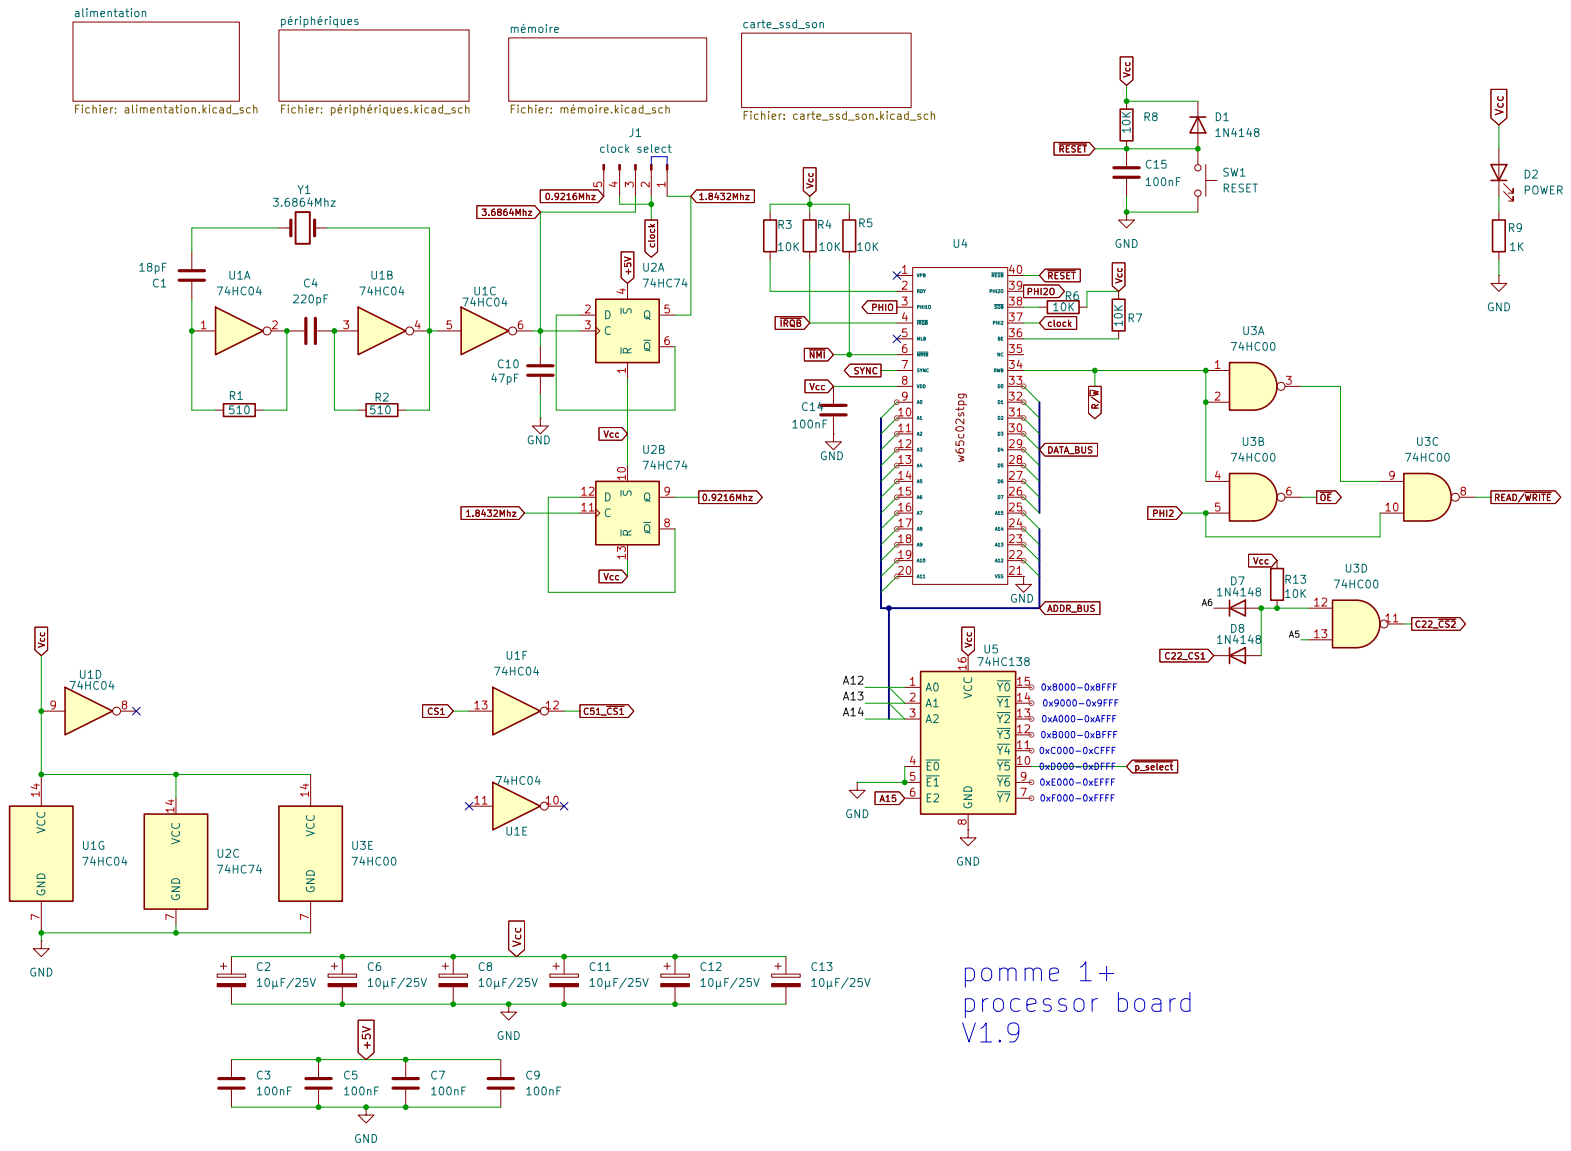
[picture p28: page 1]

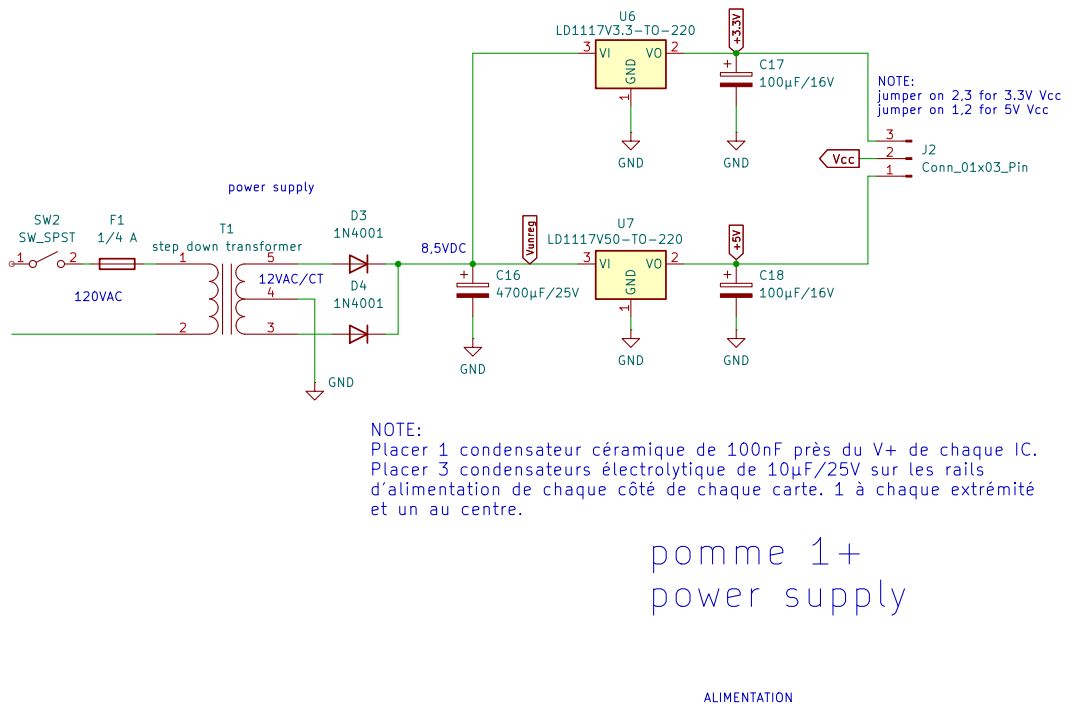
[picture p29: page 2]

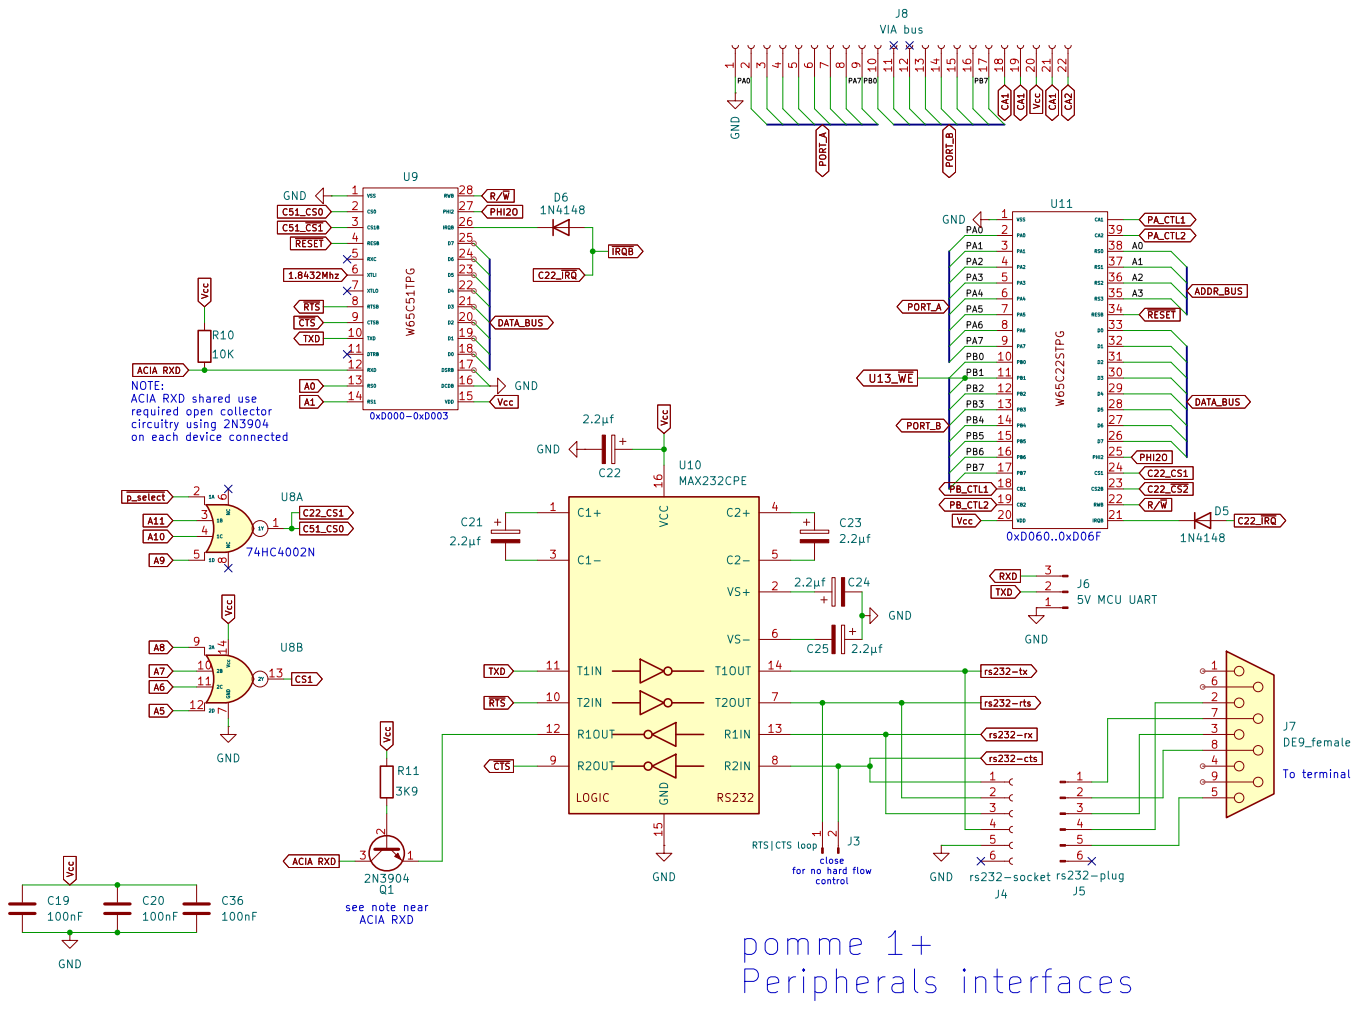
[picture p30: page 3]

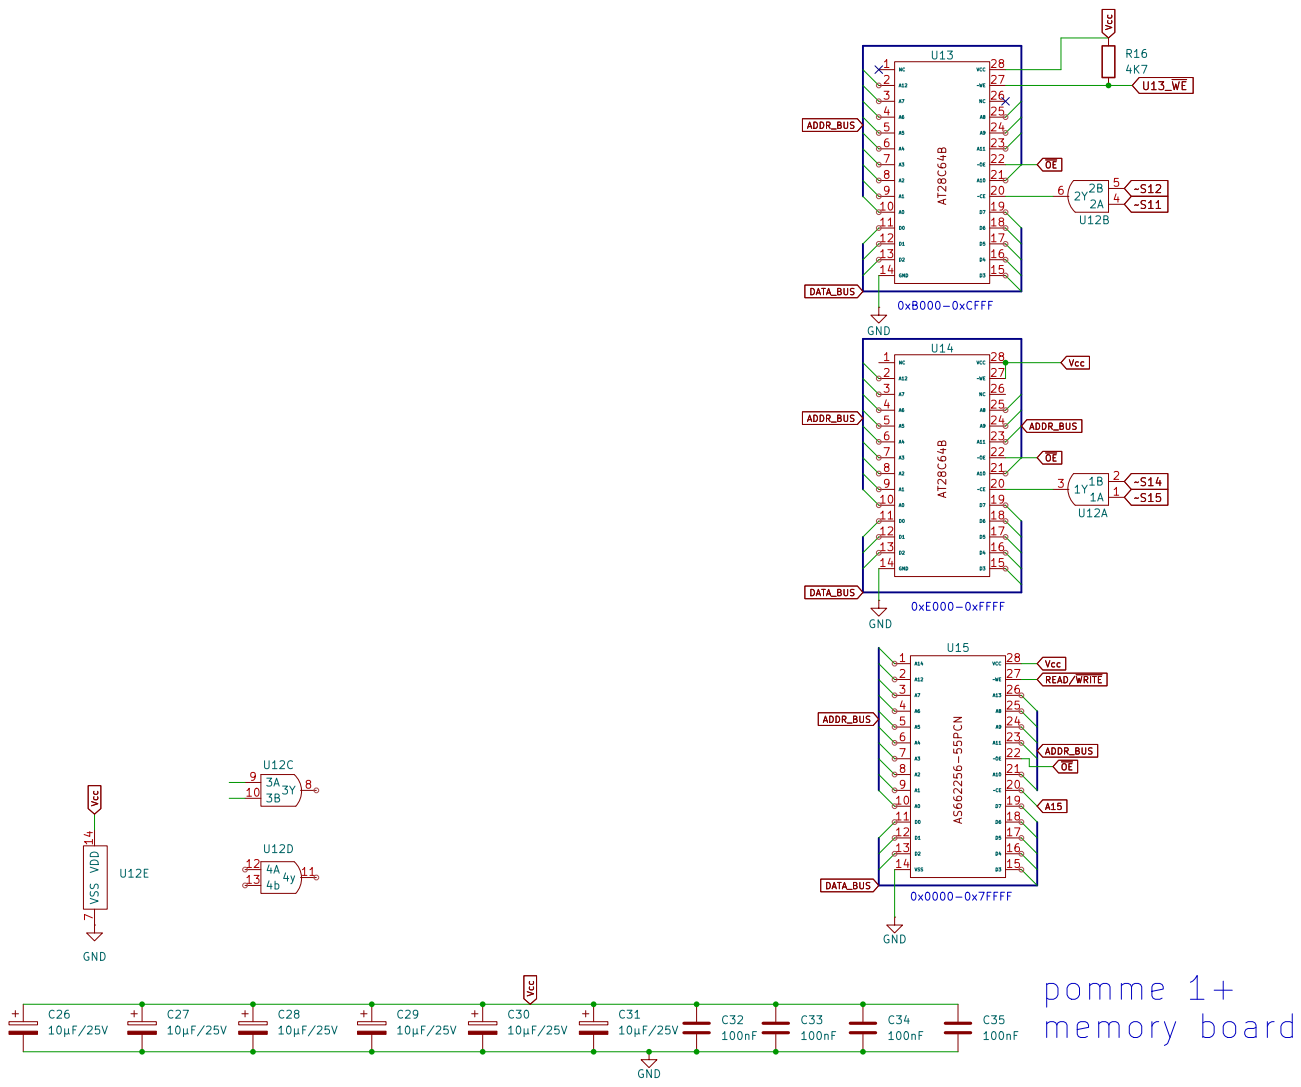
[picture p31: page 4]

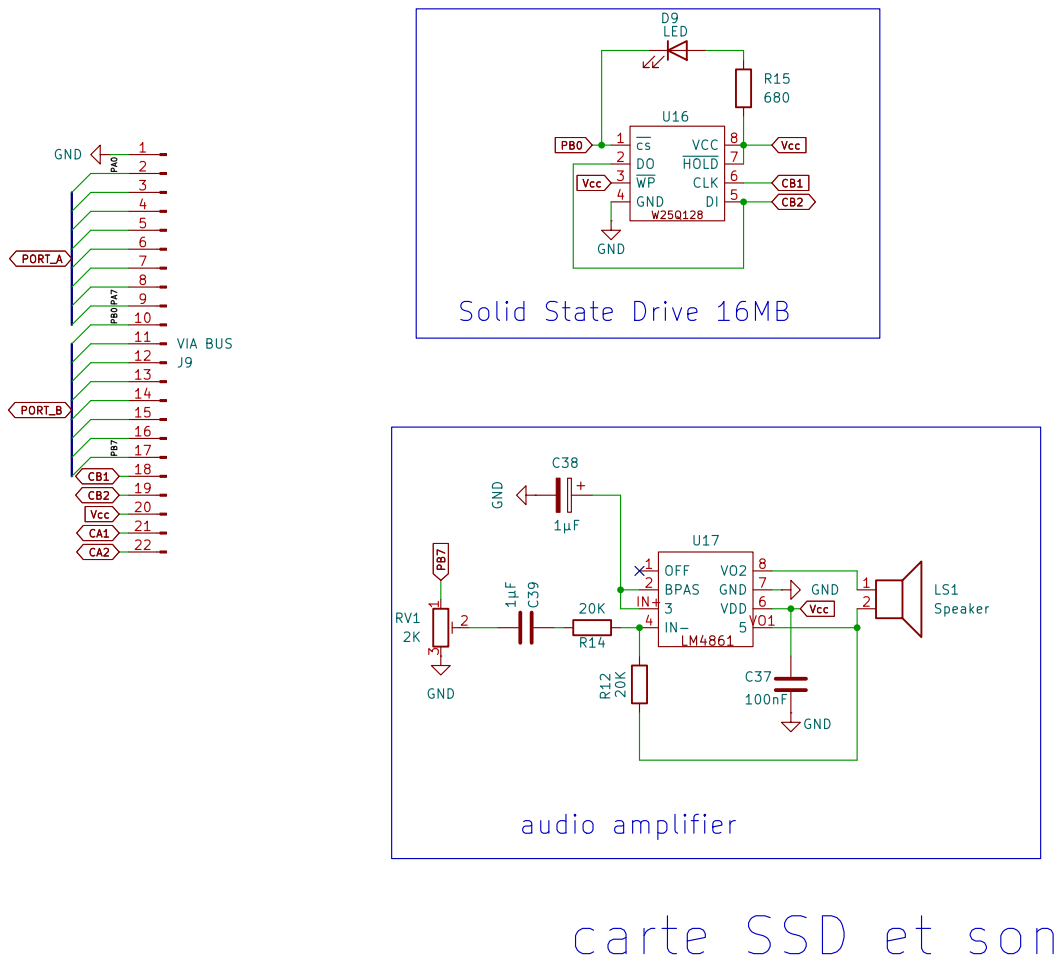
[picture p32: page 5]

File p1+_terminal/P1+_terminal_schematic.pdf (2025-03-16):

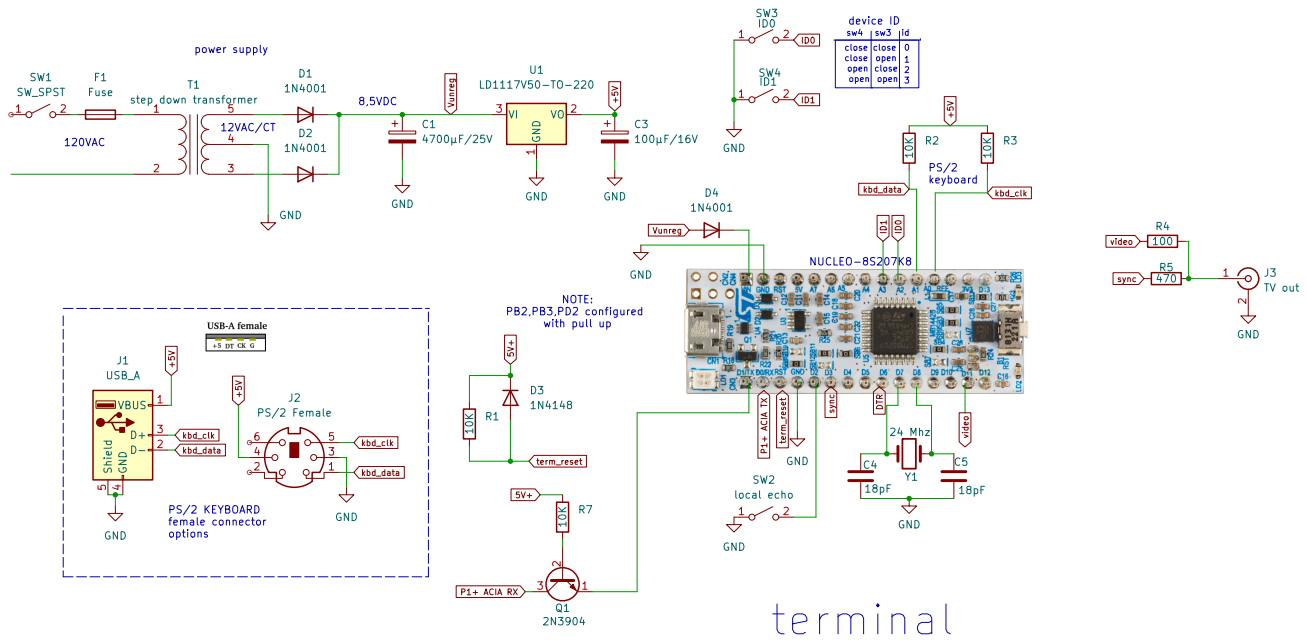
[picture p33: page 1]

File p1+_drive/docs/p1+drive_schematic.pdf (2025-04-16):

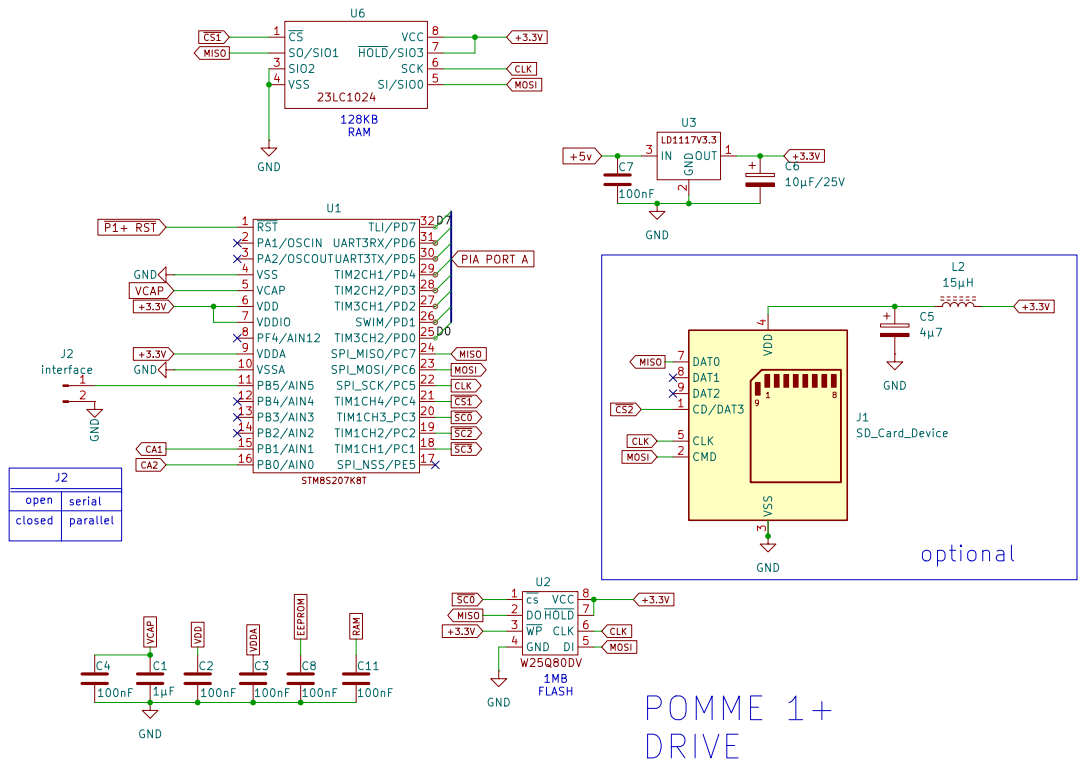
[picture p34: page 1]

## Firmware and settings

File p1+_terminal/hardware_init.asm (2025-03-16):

;;
; Copyright Jacques Deschênes 2023  
; This file is part of stm8_terminal 
;
;     stm8_terminal is free software: you can redistribute it and/or modify
;     it under the terms of the GNU General Public License as published by
;     the Free Software Foundation, either version 3 of the License, or
;     (at your option) any later version.
;
;     stm8_terminal is distributed in the hope that it will be useful,
;     but WITHOUT ANY WARRANTY; without even the implied warranty of
;     MERCHANTABILITY or FITNESS FOR A PARTICULAR PURPOSE.  See the
;     GNU General Public License for more details.
;
;     You should have received a copy of the GNU General Public License
;     along with stm8_terminal.  If not, see <http://www.gnu.org/licenses/>.
;;

;;;;;;;;;;;;;;;;;;;;;;;;;;;;;;;
;;; hardware initialization
;;;;;;;;;;;;;;;;;;;;;;;;;;;;;; 

;------------------------
; if unified compilation 
; must be first in list 
;-----------------------

    .module HW_INIT 

    .include "config.inc"

STACK_SIZE=128   
;;-----------------------------------
    .area SSEG (ABS)
;; working buffers and stack at end of RAM. 	
;;-----------------------------------
    .org RAM_SIZE-STACK_SIZE
stack_full:: .ds STACK_SIZE   ; control stack full 
stack_unf: ; stack underflow ; RAM end +1 -> 0x1800


;;--------------------------------------
    .area HOME 
;; interrupt vector table at 0x8000
;;--------------------------------------

    int cold_start			; RESET vector 
	int NonHandledInterrupt ; trap instruction 
	int NonHandledInterrupt ;int0 TLI   external top level interrupt
	int NonHandledInterrupt ;int1 AWU   auto wake up from halt
	int NonHandledInterrupt ;int2 CLK   clock controller
	int NonHandledInterrupt ;int3 EXTI0 gpio A external interrupts
	int ps2_intr_handler    ;int4 EXTI1 gpio B external interrupts
	int NonHandledInterrupt ;int5 EXTI2 gpio C external interrupts
	int NonHandledInterrupt ;int6 EXTI3 gpio D external interrupts
	int NonHandledInterrupt ;int7 EXTI4 gpio E external interrupts
	int NonHandledInterrupt ;int8 beCAN RX interrupt
	int NonHandledInterrupt ;int9 beCAN TX/ER/SC interrupt
	int NonHandledInterrupt ;int10 SPI End of transfer
	int ntsc_sync_interrupt ;int11 TIM1 update/overflow/underflow/trigger/break
	int ntsc_video_interrupt ; int12 TIM1 capture/compare
	int NonHandledInterrupt ;int13 TIM2 update /overflow
	int NonHandledInterrupt ;int14 TIM2 capture/compare
	int NonHandledInterrupt ;int15 TIM3 Update/overflow
	int NonHandledInterrupt ;int16 TIM3 Capture/compare
	int NonHandledInterrupt ;int17 UART1 TX completed
	int NonHandledInterrupt ;int18 UART1 RX full 
	int NonHandledInterrupt ;int19 I2C 
	int NonHandledInterrupt ;int20 UART3 TX completed
	int UartRxHandler 		;int21 UART3 RX full
	int NonHandledInterrupt ;int22 ADC2 end of conversion
	int NonHandledInterrupt	;int23 TIM4 update/overflow ; use to blink tv cursor 
	int NonHandledInterrupt ;int24 flash writing EOP/WR_PG_DIS
	int NonHandledInterrupt ;int25  not used
	int NonHandledInterrupt ;int26  not used
	int NonHandledInterrupt ;int27  not used
	int NonHandledInterrupt ;int28  not used
	int NonHandledInterrupt ;int29  not used


KERNEL_VAR_ORG=4
;--------------------------------------
    .area DATA (ABS)
	.org KERNEL_VAR_ORG 
;--------------------------------------	

; keep the following 3 variables in this order 
acc16:: .blkb 1 ; 16 bits accumulator, acc24 high-byte
acc8::  .blkb 1 ;  8 bits accumulator, acc24 low-byte  
ptr16::  .blkb 1 ; 16 bits pointer , farptr high-byte 
ptr8:   .blkb 1 ; 8 bits pointer, farptr low-byte  
flags:: .blkb 1 ; various boolean flags

; keyboard variables
; received scan codes queue 
SC_QUEUE_SIZE=32  
sc_queue: .blkb SC_QUEUE_SIZE ; scan codes queue 
sc_qhead: .blkb 1  ; sc_queue head index 
sc_qtail: .blkb 1  ; sc_queue tail index 
in_byte:  .blkb 1 ; shift in byte buffer 
parity:   .blkb 1 ; parity bit 
sc_rx_flags: .blkb 1 ; receive code flags 
sc_rx_phase: .blkb 1 ; scan code receive phase 
;; transmission to keyboard variables 
out_byte: .blkb 1 ; send byte to keyboard 
tx_bit_cntr: .blkb 1 ;bit counter for out_byte shifting.
tx_phase: .blkb 1 ; sending to keyboard phases 
tx_parity: .blkb 1 ; parity counter  

KBD_QUEUE_SIZE=16
kbd_queue: .blkb KBD_QUEUE_SIZE 
kbd_queue_head: .blkb 1 
kbd_queue_tail: .blkb 1 
kbd_state: .blkb 1 ; keyboard state flags 

; tvout variables 
ntsc_flags: .blkb 1 
ntsc_phase: .blkb 1 ; 
scan_line: .blkw 1 ; video lines {0..262} 
font_addr: .blkw 1 ; font table address 

; tv terminal variables 
cursor_x: .blkb 1 
cursor_y: .blkb 1 
cursor_delay: .blkb 1 ;  20/60 sec delay 
char_under: .blkb 1 ; character under cursor 
char_cursor: .blkb 1 ; character used for cursor 
saved_cx: .blkb 1 ; saved cursor position
saved_cy: .blkb 1 ; restored cursor position
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

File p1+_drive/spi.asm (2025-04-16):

;;
; Copyright Jacques Deschênes 2025 
; This file is part of pomme_1+ 
;
;     pomme_1+ is free software: you can redistribute it and/or modify
;     it under the terms of the GNU General Public License as published by
;     the Free Software Foundation, either version 3 of the License, or
;     (at your option) any later version.
;
;     pomme_1+ is distributed in the hope that it will be useful,
;     but WITHOUT ANY WARRANTY; without even the implied warranty of
;     MERCHANTABILITY or FITNESS FOR A PARTICULAR PURPOSE.  See the
;     GNU General Public License for more details.
;
;     You should have received a copy of the GNU General Public License
;     along with pomme_1+.  If not, see <http://www.gnu.org/licenses/>.
;;

;-------------------------------
;  SPI peripheral support
;  low level driver 
;--------------------------------

	.module SPI



;;;;;;;;;;;;;;;;;;;;;;;;;;;;;;;;
; W25Q FLASH memory parameters 
;;;;;;;;;;;;;;;;;;;;;;;;;;;;;;;;
W25Q_PAGE_SIZE=256 ; bytes 
W25Q_ERASE_BLOCK_SIZE=4096 ; byts 
W25Q_ADR_SIZE=3 ; address size in bytes 
;-----------------------------------------------
; W25Q80DV programming
; 1) set /CS TO 0  
; 2) enable FLASH WRITE with WREN cmd 
; 3) send 24 bits address most significant byte first  
; 4) send data bytes up to W25Q_PAGE_SIZE 
; 5) rise /CS to 1  
;-----------------------------------------------
W25Q_SECTOR_SIZE=4096 ; bytes 
SR1_BUSY=0  ; busy writting/erasing bit position in SR1   
SR1_WEL=1  ; write enable bit position in SR1  
; W25Q commands 
W25Q_WREN=6      ; set WEL bit 
W25Q_READ=3  ; can read sequential address no size limit.
W25Q_WRITE=2 ; program up to W25_PAGE_SIZE at once.
W25Q_B4K_ERASE=0x20   ; erase 4KB block   
W25Q_B32K_ERASE=0x52 ; erase 32KB block 
W25Q_B64K_ERASE=0XD8 ; erase 64KB block 
W25Q_CHIP_ERASE=0xC7   ; whole memory  
W25Q_READ_SR1=5 ; read status register 1
W25Q_READ_SR2=0x35 ; read status register 2
W25Q_MFG_ID=0x90 ; read manufacturer device id 
W25Q_080_ID=0x13 ; device id for 1MB type 
W25Q_128_ID=0x17 ; device id for 16MB type  

; xram functions 
XRAM_READ=3 
XRAM_WRITE=2 

    .area CODE 


;---------------------------------
; enable SPI peripheral to maximum 
; frequency = Fspi=Fmstr/2 
; input:
;    none  
; output:
;    none 
;--------------------------------- 
spi_init::
	bset CLK_PCKENR1,#CLK_PCKENR1_SPI ; enable clock signal 
; configure ~CS pins as output open drain  
	ld a,#(1<<SPI_CS0)+(1<<SPI_CS1)+(1<<SPI_CS2)+(1<<SPI_CS3)
	ld SPI_PORT_DDR,a ; pins as output 
	ld SPI_PORT_ODR,a ; high level 
	ld SPI_PORT_CR2,a ; fast speed 
; interrupts not used 
	clr SPI_ICR ; no interrupt enabled 
; software controlled MSTR/SLAVE mode 
	ld a,#(1<<SPI_CR2_SSM)+(1<<SPI_CR2_SSI)
	ld SPI_CR2,a 
; configure SPI as master mode 0 and enable.	
	ld a,#(1<<SPI_CR1_MSTR)+(1<<SPI_CR1_SPE)
	ld SPI_CR1,a 
; clear status register 
1$: btjt SPI_SR,#SPI_SR_BSY,.
	btjf SPI_SR,#SPI_SR_RXNE,9$
	ld a,#SPI_DR 
	jra 1$ 
;select default device 
9$:	ld a,#FLASH0  ; internal flash memory 
	call spi_select_device
	ret 

;----------------------------
; disable SPI peripheral 
;----------------------------
spi_disable::
; wait spi idle 
	btjf SPI_SR,#SPI_SR_TXE,. 
	btjf SPI_SR,#SPI_SR_RXNE,. 
	btjt SPI_SR,#SPI_SR_BSY,.
	bres SPI_CR1,#SPI_CR1_SPE
	bres CLK_PCKENR1,#CLK_PCKENR1_SPI 
	bres SPI_PORT_DDR,#SPI_CS0 
	bres SPI_PORT_DDR,#SPI_CS1  
	ret 

;------------------------
; clear SPI error 
;-----------------------
spi_clear_error::
	ld a,SPI_SR 
	ld a,SPI_DR 
1$: ret 

;----------------------
; send byte 
; input:
;   A     byte to send 
; output:
;   A     byte received 
;----------------------
spi_send_byte::
	btjf SPI_SR,#SPI_SR_TXE,.
	ld SPI_DR,a
	btjf SPI_SR,#SPI_SR_RXNE,.  
	ld a,SPI_DR 
	ret 

;------------------------------
;  receive SPI byte 
; output:
;    A 
;------------------------------
spi_rcv_byte::
	clr a 
	btjf SPI_SR,#SPI_SR_RXNE,spi_send_byte 
	ld a,SPI_DR 
	ret

;----------------------------
;  create bit mask
;  input:
;     A     bit 
;  output:
;     A     2^bit 
;-----------------------------
create_bit_mask::
	push a 
	ld a,#1 
	tnz (1,sp)
	jreq 9$
1$:
	sll a 
	dec (1,sp)
	jrne 1$
9$: _drop 1
	ret 

;-------------------------------
; SPI select device  
; input:
;   A    device FLASH0 || 
;--------------------------------
spi_select_device::
	call create_bit_mask
	_straz spi_device
	call device_id
	cp a,#W25Q_080_ID
	jrne 1$ 
	mov device_size,#1 
;	ld a,#1  ; MB
;	_straz device_size  
	jra 9$
1$:	cp a,#W25Q_128_ID
	jrne 9$ 
	ld a,#16
	_straz device_size ; 16MB  
9$: 
	ret 

;--------------------------
; open selected channel 
;--------------------------
open_channel:
	push a 
	_ldaz spi_device 
	cpl a  
	and a,SPI_PORT_ODR 
	ld SPI_PORT_ODR,a 
	pop a  
	ret 


;------------------------------
; SPI deselect channel 
;-------------------------------
close_channel::
	push a 
	btjt SPI_SR,#SPI_SR_BSY,.
	_ldaz spi_device 
	or a,SPI_PORT_ODR 
	ld SPI_PORT_ODR,a 
	pop a  
	ret 

;-----------------------------
; send 24 bits address to 
; opened device,  
; input:
;   farptr   address 
;------------------------------
spi_send_addr::
	_ldaz farptr 
	call spi_send_byte 
	_ldaz ptr16 
	call spi_send_byte 
	_ldaz ptr8 
	call spi_send_byte 
	ret 

;---------------------
; enable write to flash  
;----------------------
flash_enable_write:
	call open_channel 
	ld a,#W25Q_WREN 
	call spi_send_byte 
	call close_channel 
	ret 

;----------------------------
;  read flash status register
;----------------------------
flash_read_status:
	call open_channel 
	ld a,#W25Q_READ_SR1 
	call spi_send_byte
	call spi_rcv_byte 
	call close_channel
	ret

;------------------------------
;  poll busy bit in SR1 
;  of selected channel 
;  until operation end 
;-------------------------------
busy_polling:
1$:	call flash_read_status 
	bcp a,#(1<<SR1_BUSY)
	jrne 1$
	ret 

;----------------------------
; write data to W25Q80DV
; selected device  
; input:
;   farptr  address 
;   A       byte count, 0 == 256
;   X       buffer address 
; output:
;   none 
;----------------------------
	BUF_ADR=1 
	COUNT=BUF_ADR+2
	VSIZE=3 
flash_write::
	push a 
	pushw x
	call flash_enable_write
	call open_channel 
	ld a,#W25Q_WRITE 
	call spi_send_byte 
	call spi_send_addr 
	ldw x,(BUF_ADR,sp)
1$:
	ld a,(x)
	call spi_send_byte
	incw x
	dec (COUNT,sp) 
	jrne 1$ 
6$: 
	call close_channel
	call busy_polling ; wait completion 
	_drop VSIZE
	ret 

;-------------------------- 
; read bytes from flash 
; memory in buffer 
; input:
;   farptr flash memory address  
;   x     count, {0..4095},0=4096 bytes 
;   y     buffer addr
;---------------------------
flash_read::
	pushw y 
	pushw x 
	call open_channel
	ld a,#W25Q_READ 
	call spi_send_byte
	call spi_send_addr  
1$: call spi_rcv_byte 
	ld (y),a 
	incw y 
	ldw x,(1,sp)
	decw x
	ldw (1,sp),x 
	jrne 1$ 
9$: 
	call close_channel
	_drop 2 
	popw y 
	ret
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

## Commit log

2025-02-17 Ajout du dossier p1pMonitor
    [p1pWozmon.cfg]
2025-02-17 Assembler, linker et flasher p1pMon.s
    [p1pMon.cfg]
2025-03-06 Modification de test1.s et de la schématique. L'ordinateur fonctionne à 3.68Mhz
    [alimentation.kicad_sch, pomme-1.5.kicad_sch, périphériques.kicad_sch]
2025-03-07 Premier commit du porjet
    [test1.cfg]
2025-03-08 Travail sur p1+Monitor
    [p1+Monitor.cfg, p1pMon.cfg]
2025-03-11 Complété schématique alimentation
    [alimentation.kicad_sch, pomme-1.5.kicad_sch]
2025-03-11 Correction schematique
    [alimentation.kicad_sch]
2025-03-11 modification du readme.md pour inclure un lien vers une vidéo de présentation du projet.
2025-03-13 Ajout de p1+_terminal au projet
    [périphériques.kicad_sch, stm8_terminal.kicad_pcb, stm8_terminal.kicad_sch]
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2025-03-14 Ajout du sous-projet p1+_drive
    [pomme-1.5.kicad_sch, stm8_terminal.kicad_sch]
2025-03-16 Remplacement du p1+ drive par un circuit différent et modication à p1+ terminal et au pomme 1+
    [drive.kicad_sch, p1+_drive.kicad_pcb, p1+_drive.kicad_sch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]
2025-03-17 Modification à la schématique de p1+_drive
    [p1+_drive.kicad_sch]
2025-03-19 test terminal
    [p1+_drive.kicad_sch]
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2025-03-19 Modification de la conception du pomme 1+ Ajout d'un PIA W65C22 à la carte périphériques Ajout d'un régulateur de tension 3.3V à l'alimentation
    [alimentation.kicad_sch, drive.kicad_sch, mémoire.kicad_sch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]
2025-03-20 Ajout de photos du montage révisé, Maintenant le pome 1+ à un périphérique PIA W65C22 et fonctionne à 3.3 volts
2025-03-20 Modification documents
    [alimentation.kicad_sch, mémoire.kicad_sch, pomme-1.5.kicad_sch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]
2025-03-20 Mise à jour du readme.md suite à la modification du circuit
2025-04-09 spi.asm complété
    [p1+_drive.kicad_sch, stm8l151.kicad_sch]
2025-04-11 modification schématique p1+_drive
    [p1+_drive.kicad_sch]
2025-04-16 Ajout d'une RAM 128KB 23LC1024 au circuit du p1+_drive
    [p1+_drive.kicad_sch]
2025-04-24 Modification schématique peripherals board
    [périphériques.kicad_sch]
2025-04-24 Création d'une carte avec mémoire flash W25Q080DV de 1MO pour le stockage des fichiers du pomme 1+
    [pomme-1.5.kicad_sch, périphériques.kicad_sch]
2025-04-25 Corrigé erreur dans schématique du circuit de la mémoire FLASH W25Q080DV.
    [périphériques.kicad_sch]
2025-04-25 travail sur bios.s
    [p1+Monitor.cfg]
2025-04-26 Modification schématique V1.5
    [pomme-1.5.kicad_sch, périphériques.kicad_sch]
2025-04-27 Tentative de déboguer le W65C22 non réussi, même si tous les signaux semble OK, le chip ne répond pas.
2025-04-27 Schematic V1.6, modifié circuit pin 12 de U3D pour que la sortie du NAND ne passe à 0 qui si C22_CS1 est à 1
    [pomme-1.5.kicad_sch]
2025-04-27 Modification circuit périphériques
    [périphériques.kicad_sch]
2025-04-28 Correction à la schématique les W65C51S et W65C22S doivent revevoir le signal RWB du mpu plutôt que le signal READ/WRITEB à la pin 8 de U3
    [pomme-1.5.kicad_sch, périphériques.kicad_sch]
2025-04-28 Reprise du travail sur le BIOS. Configuration d'une minuterie continue d'une milliseconde avec interruption pour incrémenter la variable MSEC et décrémenter la variable TIMER
2025-04-28 Ajout du dossier BIOS
    [bios.cfg]
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2025-04-29 Ajout de RAND et RANDOMIZE
    [bios.cfg]
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2025-05-02 Corrigé bogue matériel pin 32 socket du VIA avait une mauvaise soudure. lecture du chip fonctionne. Effacement et écriture ne fonctionne pas.
2025-05-02 Les problèmes avec la lecteur/écriture de la mémoire FLASH semblent réglés. j'avais une mauvaise compréhension des instruction d'indirection du MPU 6502.
2025-05-03 ajout de p1+Monitor.s
    [bios.cfg]
2025-05-04 Moniteur dégogé Ajouts de commandes supplémentaires pour accéder à la mémoire flash W25Q080
2025-05-06 * Modifié l'utilisation des minuterie du **VIA** (W65C22). * TIMER1 utilisé comme générateur d'onde carré pour la fonction **TONE** du BIOS * TIMER2 utilisé pour une interruption au milliseconde * Aj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
2025-05-06 Modification du circuit pour ajouter un amplificateur audio LM4861 sur la carte amovible qui se branche sur le connecteur VIA BUS
    [alimentation.kicad_sch, mémoire.kicad_sch, pomme-1.5.kicad_sch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]
2025-05-13 Tavail sur le moniteur Version 1.1R0
    [bios.cfg]
2025-05-16 Modifié **STORE_RANGE** et **LOAD_RANGE** pour étendre ces opération à une plage de plus de 256 octets.
2025-05-19 p1+Monitor version 1.1R0 Ajout des fonction 'M','Z','V'
    [bios.cfg]
2025-05-21 MON_V1.2R2 paufiner le code du moniteur et ajout au manuel de l'utilateur p1+Monitor.pdf
2025-05-21 Mise à jour de la schématique de la carte SSD et son mise à jour du readme.md
2025-05-22 ajout de macros pour tirer avantage des instructions BBRx, BBSx, RMBx et SMBx
2025-05-24 Modifié routine RESET pour mettre à zéro les 2 piles
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2025-06-10 Modification au circuit du pomme-1+ ajout d'une seconde EEPROM (U13) 0xC000...0xDFFF. Celle-ci peut-être programmée dans le circuit.
    [mémoire.kicad_sch, pomme-1.5.kicad_sch, périphériques.kicad_sch]
2025-06-10 MON_V1.3R1 Modification de la commande MOVE du moniteur pour que celle-ci fonctionne aussi avec l'EEPROM U13dans l'intervalle mémoire ...
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2025-06-10 Modification au circuit pour supprimer le polling de la pin 1 de U13, car ça ne fonctionne pas bien. La solution logiciel est plus fiable.
    [mémoire.kicad_sch, périphériques.kicad_sch]
2025-06-10 MON_V1.3R3 Modification de la commande **Z** pour la rendre effective dans EEPROM U13. Modification des commande **W** et **R** pour permettre un étendu multiple de 256 octets Mise à jour du manuel p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

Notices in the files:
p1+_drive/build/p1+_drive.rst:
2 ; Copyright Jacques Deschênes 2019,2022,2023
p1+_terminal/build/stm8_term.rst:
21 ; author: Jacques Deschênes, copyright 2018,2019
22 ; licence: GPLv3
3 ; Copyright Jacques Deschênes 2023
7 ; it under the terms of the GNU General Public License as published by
